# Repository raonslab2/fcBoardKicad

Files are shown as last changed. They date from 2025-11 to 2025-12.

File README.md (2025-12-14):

# fcBoard - ACU5EV SoM Carrier Board

ACU5EV (Zynq UltraScale+ XCZU5EV) SoM용 캐리어 보드 KiCad 프로젝트

## 프로젝트 구조

```
fcBoardKicad/
├── fcBoard.kicad_pro          # KiCad 프로젝트 파일
├── fcBoard.kicad_sch          # 메인 회로도
├── fcBoard.kicad_pcb          # PCB 레이아웃
├── libraries/                  # 커스텀 라이브러리
│   ├── fcBoard.kicad_sym      # 심볼 라이브러리
│   └── fcBoard.pretty/        # 풋프린트 라이브러리
├── datasheets/                # 데이터시트
├── docs/                      # 설계 문서
│   └── pinmap/                # SoM 커넥터 핀맵
├── gerber/                    # 거버 출력
└── production/                # 생산 파일 (BOM, PnP)
```

## SoM 커넥터 정보

| 커넥터 | 핀 수 | 주요 신호 |
|---|---|---|
| J29 | 120핀 | BANK65, BANK66 (HDMI, MIPI, Ethernet PL) |
| J30 | 120핀 | BANK25, BANK26, MGT505 (PCIe, SFP) |
| J31 | 120핀 | BANK24, BANK44 (RS485, LED, 버튼) |
| J32 | 120핀 | PS MIO, 전원 (+12V, VCCO) |

**커넥터 모델:** Panasonic AXK6A2337YG (120핀, 0.5mm 피치)

## 인터페이스 목록

### PS (Processing System) 인터페이스
- USB 3.0 x4 (USB Hub: USB5744)
- Gigabit Ethernet (PS GEM3, RGMII)
- SD Card (SDIO1)
- UART (USB-UART: CP2102)
- CAN x2
- DisplayPort (SoM 커넥터에서 직접 출력)

### PL (Programmable Logic) 인터페이스
- HDMI 입력 (IT6801FN)
- HDMI 출력 (IT66121FN)
- Gigabit Ethernet (PL RGMII)
- PCIe x2 (MGT505)
- MIPI CSI-2 (2 Lane)
- RS485 x2
- SFP+ x2 (옵션)

## 전원 요구사항

| 전원 | 전압 | 용도 |
|---|---|---|
| 입력 | DC 12V | 메인 전원 (최소 5A) |
| VCCO_65 | 1.8V | BANK65 I/O (캐리어 공급) |
| VCCO_66 | 1.8V | BANK66 I/O (캐리어 공급) |
| 내부 | 5V, 3.3V | 주변 IC 전원 |

## 참조 자료

- [ACU5EV SoM 회로도](../ACU2CG_ACU3EG_ACU4EV_ACU5EV/Schematics/ACU5EV_SCH.pdf)
- [AXU5EV-P 캐리어 보드 참조](../AXU4EV-P_AXU5EV-P/hardware/Schematics/)
- [ACU5EV 사용자 매뉴얼](../ACU2CG_ACU3EG_ACU4EV_ACU5EV/Technical_Reference_Manual/)

## 핀맵 파일

- `docs/pinmap/J29_BANK65_66.csv` - HDMI, MIPI, Ethernet PL
- `docs/pinmap/J30_BANK25_26_MGT.csv` - PCIe, SFP
- `docs/pinmap/J31_BANK24_44.csv` - RS485, GPIO
- `docs/pinmap/J32_MIO_POWER.csv` - PS MIO, 전원

## KiCad Auto Builder (회로도 자동 생성)

YAML 설정 파일로 KiCad 회로도를 자동 생성합니다.

### Quickstart

```bash
# 1. 설정 검증
python -m kicad_auto_builder.cli validate kicad_auto_builder/examples/fcboard_power.yaml

# 2. 빌드 실행
python -m kicad_auto_builder.cli build kicad_auto_builder/examples/fcboard_power.yaml

# 3. 출력 확인
# out/fcboard_power/
#   ├── fcBoard_Power_Auto.kicad_sch
#   ├── lib/custom.kicad_sym
#   ├── lib/custom.pretty/
#   ├── bom_jlc.csv
#   └── report.md
```

### YAML 예제

- `kicad_auto_builder/examples/fcboard_power.yaml` - 전원 공급 회로
- `kicad_auto_builder/examples/fcboard_usb.yaml` - USB 인터페이스
- `kicad_auto_builder/examples/hierarchical_board.yaml` - 계층 시트 예제

## 설계 시작하기

1. KiCad 8.0 이상 설치
2. `fcBoard.kicad_pro` 열기
3. 라이브러리 경로 설정 (libraries/ 폴더)
4. 핀맵 CSV 참조하여 회로도 작성
5. PCB 레이아웃 (6층 권장)

## PCB 권장 사양

- 층수: 6층
- 두께: 1.6mm
- 임피던스: 단일 50Ω, 차동 100Ω
- 최소 선폭/간격: 0.1mm / 0.1mm
- 최소 비아: 0.3mm 드릴

## 라이선스

MIT License

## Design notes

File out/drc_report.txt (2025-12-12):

** Drc report for fcBoard.kicad_pcb **
** Created on 2025-12-01T13:50:49+0900 **

** Found 384 DRC violations **
[clearance]: Clearance violation (netclass 'Default' clearance 0.2000 mm; actual 0.0000 mm)
    Rule: netclass 'Default'; error
    @(126.1200 mm, 369.1400 mm): Pad 2 [unconnected-(Y9-Pad2)] of Y9 on F.Cu
    @(125.6200 mm, 367.8150 mm): Pad 31 [<no net>] of U41 on F.Cu
[clearance]: Clearance violation (netclass 'Default' clearance 0.2000 mm; actual 0.0000 mm)
    Rule: netclass 'Default'; error
    @(126.1200 mm, 369.1400 mm): Pad 2 [unconnected-(Y9-Pad2)] of Y9 on F.Cu
    @(126.1200 mm, 367.8150 mm): Pad 32 [<no net>] of U41 on F.Cu
[shorting_items]: Items shorting two nets (nets unconnected-(J4-SHIELD-Pad5) and unconnected-(J3-SHIELD-Pad5))
    Local override; error
    @(272.3800 mm, 57.4400 mm): PTH pad 5 [unconnected-(J4-SHIELD-Pad5)] of J4
    @(272.3800 mm, 58.5800 mm): PTH pad 5 [unconnected-(J3-SHIELD-Pad5)] of J3
[shorting_items]: Items shorting two nets (nets Net-(U26-VIN) and GND)
    Local override; error
    @(42.6050 mm, 177.5450 mm): Pad 1 [Net-(U26-VIN)] of U28 on F.Cu
    @(36.7550 mm, 180.9450 mm): Pad 3 [GND] of U27 on F.Cu
[shorting_items]: Items shorting two nets (nets Net-(D14-A) and GND)
    Local override; error
    @(42.6050 mm, 179.2450 mm): Pad 2 [Net-(D14-A)] of U28 on F.Cu
    @(36.7550 mm, 180.9450 mm): Pad 3 [GND] of U27 on F.Cu
[shorting_items]: Items shorting two nets (nets unconnected-(U28-FB-Pad4) and GND)
    Local override; error
    @(42.6050 mm, 182.6450 mm): Pad 4 [unconnected-(U28-FB-Pad4)] of U28 on F.Cu
    @(36.7550 mm, 180.9450 mm): Pad 3 [GND] of U27 on F.Cu
[shorting_items]: Items shorting two nets (nets unconnected-(U28-~{ON}{slash}OFF-Pad5) and GND)
    Local override; error
    @(42.6050 mm, 184.3450 mm): Pad 5 [unconnected-(U28-~{ON}/OFF-Pad5)] of U28 on F.Cu
    @(36.7550 mm, 180.9450 mm): Pad 3 [GND] of U27 on F.Cu
[clearance]: Clearance violation (netclass 'Default' clearance 0.2000 mm; actual 0.0250 mm)
    Rule: netclass 'Default'; error
    @(121.3750 mm, 50.4450 mm): Pad 2 [unconnected-(U17-D--Pad2)] of U17 on F.Cu
    @(120.7000 mm, 51.5950 mm): Pad 9 [unconnected-(J11-CD-Pad9)] of J11 on F.Cu
[shorting_items]: Items shorting two nets (nets unconnected-(U17-VBUS-Pad3) and unconnected-(J11-CD-Pad9))
    Local override; error
    @(121.3750 mm, 50.9450 mm): Pad 3 [unconnected-(U17-VBUS-Pad3)] of U17 on F.Cu
    @(120.7000 mm, 51.5950 mm): Pad 9 [unconnected-(J11-CD-Pad9)] of J11 on F.Cu
[shorting_items]: Items shorting two nets (nets unconnected-(U17-TXD-Pad4) and unconnected-(J11-CD-Pad9))
    Local override; error
    @(121.3750 mm, 51.4450 mm): Pad 4 [unconnected-(U17-TXD-Pad4)] of U17 on F.Cu
    @(120.7000 mm, 51.5950 mm): Pad 9 [unconnected-(J11-CD-Pad9)] of J11 on F.Cu
[shorting_items]: Items shorting two nets (nets unconnected-(U17-RXD-Pad5) and unconnected-(J11-CD-Pad9))
    Local override; error
    @(121.3750 mm, 51.9450 mm): Pad 5 [unconnected-(U17-RXD-Pad5)] of U17 on F.Cu
    @(120.7000 mm, 51.5950 mm): Pad 9 [unconnected-(J11-CD-Pad9)] of J11 on F.Cu
[shorting_items]: Items shorting two nets (nets unconnected-(U17-RTS-Pad6) and unconnected-(J11-CD-Pad9))
    Local override; error
    @(121.3750 mm, 52.4450 mm): Pad 6 [unconnected-(U17-RTS-Pad6)] of U17 on F.Cu
    @(120.7000 mm, 51.5950 mm): Pad 9 [unconnected-(J11-CD-Pad9)] of J11 on F.Cu
[shorting_items]: Items shorting two nets (nets unconnected-(J3-SHIELD-Pad5) and unconnected-(J2-SHIELD-Pad5))
    Local override; error
    @(272.3800 mm, 45.4400 mm): PTH pad 5 [unconnected-(J3-SHIELD-Pad5)] of J3
    @(272.3800 mm, 46.5800 mm): PTH pad 5 [unconnected-(J2-SHIELD-Pad5)] of J2
[shorting_items]: Items shorting two nets (nets unconnected-(J11-CD-Pad9) and unconnected-(U16-~{RE}-Pad2))
    Local override; error
    @(106.9500 mm, 51.5950 mm): Pad 9 [unconnected-(J11-CD-Pad9)] of J11 on F.Cu
    @(106.3500 mm, 50.8100 mm): Pad 2 [unconnected-(U16-~{RE}-Pad2)] of U16 on F.Cu
[shorting_items]: Items shorting two nets (nets unconnected-(J11-CD-Pad9) and unconnected-(U16-DE-Pad3))
    Local override; error
    @(106.9500 mm, 51.5950 mm): Pad 9 [unconnected-(J11-CD-Pad9)] of J11 on F.Cu
    @(106.3500 mm, 52.0800 mm): Pad 3 [unconnected-(U16-DE-Pad3)] of U16 on F.Cu
[clearance]: Clearance violation (netclass 'Default' clearance 0.2000 mm; actual 0.1850 mm)
    Rule: netclass 'Default'; error
    @(232.1075 mm, 36.3100 mm): Pad 1 [unconnected-(U5-D+-Pad1)] of U5 on F.Cu
    @(232.6700 mm, 35.6475 mm): Pad 9 [<no net>] of U5 on F.Cu
[clearance]: Clearance violation (netclass 'Default' clearance 0.2000 mm; actual 0.1750 mm)
    Rule: netclass 'Default'; error
    @(232.1075 mm, 36.3100 mm): Pad 1 [unconnected-(U5-D+-Pad1)] of U5 on F.Cu
    @(232.2700 mm, 35.6475 mm): Pad 10 [<no net>] of U5 on F.Cu
[clearance]: Clearance violation (netclass 'Default' clearance 0.2000 mm; actual 0.1750 mm)
    Rule: netclass 'Default'; error
    @(232.0075 mm, 36.7100 mm): Pad 2 [unconnected-(U5-D--Pad2)] of U5 on F.Cu
    @(232.2700 mm, 37.3725 mm): Pad 3 [unconnected-(U5-D+_OUT-Pad3)] of U5 on F.Cu
[clearance]: Clearance violation (netclass 'Default' clearance 0.2000 mm; actual 0.1750 mm)
    Rule: netclass 'Default'; error
    @(233.0700 mm, 37.3725 mm): Pad 5 [GND] of U5 on F.Cu
    @(233.3325 mm, 36.7100 mm): Pad 6 [+3V3] of U5 on F.Cu
[clearance]: Clearance violation (netclass 'Default' clearance 0.2000 mm; actual 0.1750 mm)
    Rule: netclass 'Default'; error
    @(233.3325 mm, 36.3100 mm): Pad 7 [<no net>] of U5 on F.Cu
    @(233.0700 mm, 35.6475 mm): Pad 8 [<no net>] of U5 on F.Cu
[clearance]: Clearance violation (netclass 'Default' clearance 0.2000 mm; actual 0.1850 mm)
    Rule: netclass 'Default'; error
    @(242.1075 mm, 66.3100 mm): Pad 1 [unconnected-(U4-D+-Pad1)] of U4 on F.Cu
    @(242.6700 mm, 65.6475 mm): Pad 9 [<no net>] of U4 on F.Cu
[clearance]: Clearance violation (netclass 'Default' clearance 0.2000 mm; actual 0.1750 mm)
    Rule: netclass 'Default'; error
    @(242.1075 mm, 66.3100 mm): Pad 1 [unconnected-(U4-D+-Pad1)] of U4 on F.Cu
    @(242.2700 mm, 65.6475 mm): Pad 10 [<no net>] of U4 on F.Cu
[clearance]: Clearance violation (netclass 'Default' clearance 0.2000 mm; actual 0.1750 mm)
    Rule: netclass 'Default'; error
    @(242.0075 mm, 66.7100 mm): Pad 2 [unconnected-(U4-D--Pad2)] of U4 on F.Cu
    @(242.2700 mm, 67.3725 mm): Pad 3 [unconnected-(U4-D+_OUT-Pad3)] of U4 on F.Cu
[clearance]: Clearance violation (netclass 'Default' clearance 0.2000 mm; actual 0.1750 mm)
    Rule: netclass 'Default'; error
    @(243.0700 mm, 67.3725 mm): Pad 5 [GND] of U4 on F.Cu
    @(243.3325 mm, 66.7100 mm): Pad 6 [+3V3] of U4 on F.Cu
[clearance]: Clearance violation (netclass 'Default' clearance 0.2000 mm; actual 0.1750 mm)
    Rule: netclass 'Default'; error
    @(243.3325 mm, 66.3100 mm): Pad 7 [<no net>] of U4 on F.Cu
    @(243.0700 mm, 65.6475 mm): Pad 8 [<no net>] of U4 on F.Cu
[shorting_items]: Items shorting two nets (nets unconnected-(J2-SHIELD-Pad5) and unconnected-(J1-SHIELD-Pad5))
    Local override; error
    @(272.3800 mm, 33.4400 mm): PTH pad 5 [unconnected-(J2-SHIELD-Pad5)] of J2
    @(272.3800 mm, 34.5800 mm): PTH pad 5 [unconnected-(J1-SHIELD-Pad5)] of J1
[shorting_items]: Items shorting two nets (nets /HDMI In/Out/HDMI_IN_D2P and Net-(U41-CEC))
    Local override; error
    @(135.4075 mm, 375.8900 mm): Pad 1 [/HDMI In/Out/HDMI_IN_D2P] of U44 on F.Cu
    @(135.4075 mm, 375.8900 mm): Pad 5 [Net-(U41-CEC)] of U45 on F.Cu
[shorting_items]: Items shorting two nets (nets unconnected-(U44-D2--Pad2) and Net-(U41-CEC))
    Local override; error
    @(135.4075 mm, 376.3900 mm): Pad 2 [unconnected-(U44-D2--Pad2)] of U44 on F.Cu
    @(135.4075 mm, 376.3900 mm): Pad 6 [Net-(U41-CEC)] of U45 on F.Cu
[clearance]: Clearance violation (netclass 'Default' clearance 0.2000 mm; actual 0.1750 mm)
    Rule: netclass 'Default'; error
    @(135.4075 mm, 376.8900 mm): Pad 3 [/HDMI In/Out/HDMI_IN_D2N] of U44 on F.Cu
    @(136.1200 mm, 377.1025 mm): Pad 7 [Net-(U41-CEC)] of U45 on F.Cu
[clearance]: Clearance violation (netclass 'Default' clearance 0.2000 mm; actual 0.1750 mm)
    Rule: netclass 'Default'; error
    @(135.4075 mm, 377.3900 mm): Pad 4 [unconnected-(U44-D1--Pad4)] of U44 on F.Cu
    @(136.1200 mm, 377.1025 mm): Pad 7 [Net-(U41-CEC)] of U45 on F.Cu
[clearance]: Clearance violation (netclass 'Default' clearance 0.2000 mm; actual 0.1750 mm)
    Rule: netclass 'Default'; error
    @(139.3325 mm, 377.3900 mm): Pad 15 [Net-(U43-TMDS_CLK-)] of U44 on F.Cu
    @(138.6200 mm, 377.1025 mm): Pad 12 [Net-(J23-TMDS_D2-)] of U45 on F.Cu
[clearance]: Clearance violation (netclass 'Default' clearance 0.2000 mm; actual 0.1750 mm)
    Rule: netclass 'Default'; error
    @(139.3325 mm, 376.8900 mm): Pad 16 [unconnected-(U44-CLK+_O-Pad16)] of U44 on F.Cu
    @(138.6200 mm, 377.1025 mm): Pad 12 [Net-(J23-TMDS_D2-)] of U45 on F.Cu
[shorting_items]: Items shorting two nets (nets Net-(U43-CEC) and Net-(J23-TMDS_D1+))
    Local override; error
    @(139.3325 mm, 376.3900 mm): Pad 17 [Net-(U43-CEC)] of U44 on F.Cu
    @(139.3325 mm, 376.3900 mm): Pad 13 [Net-(J23-TMDS_D1+)] of U45 on F.Cu
[clearance]: Clearance violation (netclass 'Default' clearance 0.2000 mm; actual 0.0000 mm)
    Rule: netclass 'Default'; error
    @(139.3325 mm, 375.8900 mm): Pad 18 [<no net>] of U44 on F.Cu
    @(139.3325 mm, 375.8900 mm): Pad 14 [Net-(J23-TMDS_D1_SH)] of U45 on F.Cu
[clearance]: Clearance violation (netclass 'Default' clearance 0.2000 mm; actual 0.0000 mm)
    Rule: netclass 'Default'; error
    @(138.6200 mm, 375.1775 mm): Pad 19 [<no net>] of U44 on F.Cu
    @(137.3700 mm, 375.1400 mm): Pad 25 [<no net>] of U45 on F.Cu
[clearance]: Clearance violation (netclass 'Default' clearance 0.2000 mm; actual 0.1750 mm)
    Rule: netclass 'Default'; error
    @(138.6200 mm, 375.1775 mm): Pad 19 [<no net>] of U44 on F.Cu
    @(139.3325 mm, 375.3900 mm): Pad 15 [Net-(J23-TMDS_D1-)] of U45 on F.Cu
[clearance]: Clearance violation (netclass 'Default' clearance 0.2000 mm; actual 0.1750 mm)
    Rule: netclass 'Default'; error
    @(138.6200 mm, 375.1775 mm): Pad 19 [<no net>] of U44 on F.Cu
    @(139.3325 mm, 374.8900 mm): Pad 16 [Net-(J23-TMDS_D0+)] of U45 on F.Cu
[clearance]: Clearance violation (netclass 'Default' clearance 0.2000 mm; actual 0.0000 mm)
    Rule: netclass 'Default'; error
    @(138.1200 mm, 375.1775 mm): Pad 20 [<no net>] of U44 on F.Cu
    @(137.3700 mm, 375.1400 mm): Pad 25 [<no net>] of U45 on F.Cu
[clearance]: Clearance violation (netclass 'Default' clearance 0.2000 mm; actual 0.0000 mm)
    Rule: netclass 'Default'; error
    @(137.6200 mm, 375.1775 mm): Pad 21 [<no net>] of U44 on F.Cu
    @(137.3700 mm, 375.1400 mm): Pad 25 [<no net>] of U45 on F.Cu
[clearance]: Clearance violation (netclass 'Default' clearance 0.2000 mm; actual 0.0000 mm)
    Rule: netclass 'Default'; error
    @(137.1200 mm, 375.1775 mm): Pad 22 [<no net>] of U44 on F.Cu
    @(137.3700 mm, 375.1400 mm): Pad 25 [<no net>] of U45 on F.Cu
[clearance]: Clearance violation (netclass 'Default' clearance 0.2000 mm; actual 0.0000 mm)
    Rule: netclass 'Default'; error
    @(136.6200 mm, 375.1775 mm): Pad 23 [<no net>] of U44 on F.Cu
    @(137.3700 mm, 375.1400 mm): Pad 25 [<no net>] of U45 on F.Cu
[clearance]: Clearance violation (netclass 'Default' clearance 0.2000 mm; actual 0.0000 mm)
    Rule: netclass 'Default'; error
    @(136.1200 mm, 375.1775 mm): Pad 24 [<no net>] of U44 on F.Cu
    @(137.3700 mm, 375.1400 mm): Pad 25 [<no net>] of U45 on F.Cu
[clearance]: Clearance violation (netclass 'Default' clearance 0.2000 mm; actual 0.1750 mm)
    Rule: netclass 'Default'; error
    @(136.1200 mm, 375.1775 mm): Pad 24 [<no net>] of U44 on F.Cu
    @(135.4075 mm, 374.8900 mm): Pad 3 [Net-(U41-CEC)] of U45 on F.Cu
[clearance]: Clearance violation (netclass 'Default' clearance 0.2000 mm; actual 0.1750 mm)
    Rule: netclass 'Default'; error
    @(136.1200 mm, 375.1775 mm): Pad 24 [<no net>] of U44 on F.Cu
    @(135.4075 mm, 375.3900 mm): Pad 4 [Net-(U41-CEC)] of U45 on F.Cu
[clearance]: Clearance violation (netclass 'Default' clearance 0.2000 mm; actual 0.0000 mm)
    Rule: netclass 'Default'; error
    @(137.3700 mm, 377.1400 mm): Pad 25 [<no net>] of U44 on F.Cu
    @(137.3700 mm, 375.1400 mm): Pad 25 [<no net>] of U45 on F.Cu
[clearance]: Clearance violation (netclass 'Default' clearance 0.2000 mm; actual 0.0000 mm)
    Rule: netclass 'Default'; error
    @(137.3700 mm, 377.1400 mm): Pad 25 [<no net>] of U44 on F.Cu
    @(136.1200 mm, 377.1025 mm): Pad 7 [Net-(U41-CEC)] of U45 on F.Cu
[clearance]: Clearance violation (netclass 'Default' clearance 0.2000 mm; actual 0.0000 mm)
    Rule: netclass 'Default'; error
    @(137.3700 mm, 377.1400 mm): Pad 25 [<no net>] of U44 on F.Cu
    @(136.6200 mm, 377.1025 mm): Pad 8 [Net-(U41-CEC)] of U45 on F.Cu
[clearance]: Clearance violation (netclass 'Default' clearance 0.2000 mm; actual 0.0000 mm)
    Rule: netclass 'Default'; error
    @(137.3700 mm, 377.1400 mm): Pad 25 [<no net>] of U44 on F.Cu
    @(137.1200 mm, 377.1025 mm): Pad 9 [Net-(U41-CEC)] of U45 on F.Cu
[clearance]: Clearance violation (netclass 'Default' clearance 0.2000 mm; actual 0.0000 mm)
    Rule: netclass 'Default'; error
    @(137.3700 mm, 377.1400 mm): Pad 25 [<no net>] of U44 on F.Cu
    @(137.6200 mm, 377.1025 mm): Pad 10 [Net-(J23-TMDS_D2+)] of U45 on F.Cu
[clearance]: Clearance violation (netclass 'Default' clearance 0.2000 mm; actual 0.0000 mm)
    Rule: netclass 'Default'; error
    @(137.3700 mm, 377.1400 mm): Pad 25 [<no net>] of U44 on F.Cu
    @(138.1200 mm, 377.1025 mm): Pad 11 [Net-(J23-TMDS_D2_SH)] of U45 on F.Cu
[clearance]: Clearance violation (netclass 'Default' clearance 0.2000 mm; actual 0.0000 mm)
    Rule: netclass 'Default'; error
    @(137.3700 mm, 377.1400 mm): Pad 25 [<no net>] of U44 on F.Cu
    @(138.6200 mm, 377.1025 mm): Pad 12 [Net-(J23-TMDS_D2-)] of U45 on F.Cu
[shorting_items]: Items shorting two nets (nets Net-(J23-TMDS_D2+) and Net-(J23-TMDS_D2-))
    Local override; error
    @(168.7200 mm, 389.4000 mm): Pad 1 [Net-(J23-TMDS_D2+)] of J23 on F.Cu
    @(168.7200 mm, 388.4000 mm): Pad 3 [Net-(J23-TMDS_D2-)] of J23 on F.Cu
[shorting_items]: Items shorting two nets (nets Net-(J23-TMDS_D2+) and Net-(J23-TMDS_D1_SH))
    Local override; error
    @(168.7200 mm, 389.4000 mm): Pad 1 [Net-(J23-TMDS_D2+)] of J23 on F.Cu
    @(168.7200 mm, 387.4000 mm): Pad 5 [Net-(J23-TMDS_D1_SH)] of J23 on F.Cu
[clearance]: Clearance violation (netclass 'Default' clearance 0.2000 mm; actual 0.0000 mm)
    Rule: netclass 'Default'; error
    @(168.7200 mm, 389.4000 mm): Pad 1 [Net-(J23-TMDS_D2+)] of J23 on F.Cu
    @(168.8200 mm, 391.6750 mm): Pad SH [<no net>] of J23 on F.Cu
[shorting_items]: Items shorting two nets (nets Net-(J23-TMDS_D2_SH) and Net-(J23-TMDS_D1+))
    Local override; error
    @(168.7200 mm, 388.9000 mm): Pad 2 [Net-(J23-TMDS_D2_SH)] of J23 on B.Cu
    @(168.7200 mm, 387.9000 mm): Pad 4 [Net-(J23-TMDS_D1+)] of J23 on B.Cu
[shorting_items]: Items shorting two nets (nets Net-(J23-TMDS_D2_SH) and Net-(J23-TMDS_D1-))
    Local override; error
    @(168.7200 mm, 388.9000 mm): Pad 2 [Net-(J23-TMDS_D2_SH)] of J23 on B.Cu
    @(168.7200 mm, 386.9000 mm): Pad 6 [Net-(J23-TMDS_D1-)] of J23 on B.Cu
[clearance]: Clearance violation (netclass 'Default' clearance 0.2000 mm; actual 0.0750 mm)
    Rule: netclass 'Default'; error
    @(168.7200 mm, 388.9000 mm): Pad 2 [Net-(J23-TMDS_D2_SH)] of J23 on B.Cu
    @(168.8200 mm, 391.6750 mm): Pad SH [<no net>] of J23 on B.Cu
[shorting_items]: Items shorting two nets (nets Net-(J23-TMDS_D2-) and Net-(J23-TMDS_D1_SH))
    Local override; error
    @(168.7200 mm, 388.4000 mm): Pad 3 [Net-(J23-TMDS_D2-)] of J23 on F.Cu
    @(168.7200 mm, 387.4000 mm): Pad 5 [Net-(J23-TMDS_D1_SH)] of J23 on F.Cu
[shorting_items]: Items shorting two nets (nets Net-(J23-TMDS_D2-) and Net-(J23-TMDS_D0+))
    Local override; error
    @(168.7200 mm, 388.4000 mm): Pad 3 [Net-(J23-TMDS_D2-)] of J23 on F.Cu
    @(168.7200 mm, 386.4000 mm): Pad 7 [Net-(J23-TMDS_D0+)] of J23 on F.Cu
[shorting_items]: Items shorting two nets (nets Net-(J23-TMDS_D1+) and Net-(J23-TMDS_D1-))
    Local override; error
    @(168.7200 mm, 387.9000 mm): Pad 4 [Net-(J23-TMDS_D1+)] of J23 on B.Cu
    @(168.7200 mm, 386.9000 mm): Pad 6 [Net-(J23-TMDS_D1-)] of J23 on B.Cu
[shorting_items]: Items shorting two nets (nets Net-(J23-TMDS_D1+) and Net-(J23-TMDS_D0_SH))
    Local override; error
    @(168.7200 mm, 387.9000 mm): Pad 4 [Net-(J23-TMDS_D1+)] of J23 on B.Cu
    @(168.7200 mm, 385.9000 mm): Pad 8 [Net-(J23-TMDS_D0_SH)] of J23 on B.Cu
[shorting_items]: Items shorting two nets (nets Net-(J23-TMDS_D1_SH) and Net-(J23-TMDS_D0+))
    Local override; error
    @(168.7200 mm, 387.4000 mm): Pad 5 [Net-(J23-TMDS_D1_SH)] of J23 on F.Cu
    @(168.7200 mm, 386.4000 mm): Pad 7 [Net-(J23-TMDS_D0+)] of J23 on F.Cu
[shorting_items]: Items shorting two nets (nets Net-(J23-TMDS_D1_SH) and unconnected-(J23-TMDS_D0--Pad9))
    Local override; error
    @(168.7200 mm, 387.4000 mm): Pad 5 [Net-(J23-TMDS_D1_SH)] of J23 on F.Cu
    @(168.7200 mm, 385.4000 mm): Pad 9 [unconnected-(J23-TMDS_D0--Pad9)] of J23 on F.Cu
[shorting_items]: Items shorting two nets (nets Net-(J23-TMDS_D1-) and Net-(J23-TMDS_D0_SH))
    Local override; error
    @(168.7200 mm, 386.9000 mm): Pad 6 [Net-(J23-TMDS_D1-)] of J23 on B.Cu
    @(168.7200 mm, 385.9000 mm): Pad 8 [Net-(J23-TMDS_D0_SH)] of J23 on B.Cu
[shorting_items]: Items shorting two nets (nets Net-(J23-TMDS_D1-) and unconnected-(J23-TMDS_CLK+-Pad10))
    Local override; error
    @(168.7200 mm, 386.9000 mm): Pad 6 [Net-(J23-TMDS_D1-)] of J23 on B.Cu
    @(168.7200 mm, 384.9000 mm): Pad 10 [unconnected-(J23-TMDS_CLK+-Pad10)] of J23 on B.Cu
[shorting_items]: Items shorting two nets (nets Net-(J23-TMDS_D0+) and unconnected-(J23-TMDS_D0--Pad9))
    Local override; error
    @(168.7200 mm, 386.4000 mm): Pad 7 [Net-(J23-TMDS_D0+)] of J23 on F.Cu
    @(168.7200 mm, 385.4000 mm): Pad 9 [unconnected-(J23-TMDS_D0--Pad9)] of J23 on F.Cu
[shorting_items]: Items shorting two nets (nets Net-(J23-TMDS_D0+) and unconnected-(J23-TMDS_CLK_SH-Pad11))
    Local override; error
    @(168.7200 mm, 386.4000 mm): Pad 7 [Net-(J23-TMDS_D0+)] of J23 on F.Cu
    @(168.7200 mm, 384.4000 mm): Pad 11 [unconnected-(J23-TMDS_CLK_SH-Pad11)] of J23 on F.Cu
[shorting_items]: Items shorting two nets (nets Net-(J23-TMDS_D0_SH) and unconnected-(J23-TMDS_CLK+-Pad10))
    Local override; error
    @(168.7200 mm, 385.9000 mm): Pad 8 [Net-(J23-TMDS_D0_SH)] of J23 on B.Cu
    @(168.7200 mm, 384.9000 mm): Pad 10 [unconnected-(J23-TMDS_CLK+-Pad10)] of J23 on B.Cu
[shorting_items]: Items shorting two nets (nets Net-(J23-TMDS_D0_SH) and unconnected-(J23-TMDS_CLK--Pad12))
    Local override; error
    @(168.7200 mm, 385.9000 mm): Pad 8 [Net-(J23-TMDS_D0_SH)] of J23 on B.Cu
    @(168.7200 mm, 383.9000 mm): Pad 12 [unconnected-(J23-TMDS_CLK--Pad12)] of J23 on B.Cu
[shorting_items]: Items shorting two nets (nets unconnected-(J23-TMDS_D0--Pad9) and unconnected-(J23-TMDS_CLK_SH-Pad11))
    Local override; error
    @(168.7200 mm, 385.4000 mm): Pad 9 [unconnected-(J23-TMDS_D0--Pad9)] of J23 on F.Cu
    @(168.7200 mm, 384.4000 mm): Pad 11 [unconnected-(J23-TMDS_CLK_SH-Pad11)] of J23 on F.Cu
[shorting_items]: Items shorting two nets (nets unconnected-(J23-TMDS_D0--Pad9) and unconnected-(J23-CEC-Pad13))
    Local override; error
    @(168.7200 mm, 385.4000 mm): Pad 9 [unconnected-(J23-TMDS_D0--Pad9)] of J23 on F.Cu
    @(168.7200 mm, 383.4000 mm): Pad 13 [unconnected-(J23-CEC-Pad13)] of J23 on F.Cu
[shorting_items]: Items shorting two nets (nets unconnected-(J23-TMDS_CLK+-Pad10) and unconnected-(J23-TMDS_CLK--Pad12))
    Local override; error
    @(168.7200 mm, 384.9000 mm): Pad 10 [unconnected-(J23-TMDS_CLK+-Pad10)] of J23 on B.Cu
    @(168.7200 mm, 383.9000 mm): Pad 12 [unconnected-(J23-TMDS_CLK--Pad12)] of J23 on B.Cu
[shorting_items]: Items shorting two nets (nets unconnected-(J23-TMDS_CLK+-Pad10) and unconnected-(J23-NC-Pad14))
    Local override; error
    @(168.7200 mm, 384.9000 mm): Pad 10 [unconnected-(J23-TMDS_CLK+-Pad10)] of J23 on B.Cu
    @(168.7200 mm, 382.9000 mm): Pad 14 [unconnected-(J23-NC-Pad14)] of J23 on B.Cu
[shorting_items]: Items shorting two nets (nets unconnected-(J23-TMDS_CLK_SH-Pad11) and unconnected-(J23-CEC-Pad13))
    Local override; error
    @(168.7200 mm, 384.4000 mm): Pad 11 [unconnected-(J23-TMDS_CLK_SH-Pad11)] of J23 on F.Cu
    @(168.7200 mm, 383.4000 mm): Pad 13 [unconnected-(J23-CEC-Pad13)] of J23 on F.Cu
[shorting_items]: Items shorting two nets (nets unconnected-(J23-TMDS_CLK_SH-Pad11) and unconnected-(J23-SCL-Pad15))
    Local override; error
    @(168.7200 mm, 384.4000 mm): Pad 11 [unconnected-(J23-TMDS_CLK_SH-Pad11)] of J23 on F.Cu
    @(168.7200 mm, 382.4000 mm): Pad 15 [unconnected-(J23-SCL-Pad15)] of J23 on F.Cu
[shorting_items]: Items shorting two nets (nets unconnected-(J23-TMDS_CLK--Pad12) and unconnected-(J23-NC-Pad14))
    Local override; error
    @(168.7200 mm, 383.9000 mm): Pad 12 [unconnected-(J23-TMDS_CLK--Pad12)] of J23 on B.Cu
    @(168.7200 mm, 382.9000 mm): Pad 14 [unconnected-(J23-NC-Pad14)] of J23 on B.Cu
[shorting_items]: Items shorting two nets (nets unconnected-(J23-TMDS_CLK--Pad12) and unconnected-(J23-SDA-Pad16))
    Local override; error
    @(168.7200 mm, 383.9000 mm): Pad 12 [unconnected-(J23-TMDS_CLK--Pad12)] of J23 on B.Cu
    @(168.7200 mm, 381.9000 mm): Pad 16 [unconnected-(J23-SDA-Pad16)] of J23 on B.Cu
[shorting_items]: Items shorting two nets (nets unconnected-(J23-CEC-Pad13) and unconnected-(J23-SCL-Pad15))
    Local override; error
    @(168.7200 mm, 383.4000 mm): Pad 13 [unconnected-(J23-CEC-Pad13)] of J23 on F.Cu
    @(168.7200 mm, 382.4000 mm): Pad 15 [unconnected-(J23-SCL-Pad15)] of J23 on F.Cu
[shorting_items]: Items shorting two nets (nets unconnected-(J23-CEC-Pad13) and GND)
    Local override; error
    @(168.7200 mm, 383.4000 mm): Pad 13 [unconnected-(J23-CEC-Pad13)] of J23 on F.Cu
    @(168.7200 mm, 381.4000 mm): Pad 17 [GND] of J23 on F.Cu
[shorting_items]: Items shorting two nets (nets unconnected-(J23-NC-Pad14) and unconnected-(J23-SDA-Pad16))
    Local override; error
    @(168.7200 mm, 382.9000 mm): Pad 14 [unconnected-(J23-NC-Pad14)] of J23 on B.Cu
    @(168.7200 mm, 381.9000 mm): Pad 16 [unconnected-(J23-SDA-Pad16)] of J23 on B.Cu
[shorting_items]: Items shorting two nets (nets unconnected-(J23-NC-Pad14) and unconnected-(J23-+5V-Pad18))
    Local override; error
    @(168.7200 mm, 382.9000 mm): Pad 14 [unconnected-(J23-NC-Pad14)] of J23 on B.Cu
    @(168.7200 mm, 380.9000 mm): Pad 18 [unconnected-(J23-+5V-Pad18)] of J23 on B.Cu
[shorting_items]: Items shorting two nets (nets unconnected-(J23-SCL-Pad15) and GND)
    Local override; error
    @(168.7200 mm, 382.4000 mm): Pad 15 [unconnected-(J23-SCL-Pad15)] of J23 on F.Cu
    @(168.7200 mm, 381.4000 mm): Pad 17 [GND] of J23 on F.Cu
[shorting_items]: Items shorting two nets (nets unconnected-(J23-SCL-Pad15) and unconnected-(J23-HPD-Pad19))
    Local override; error
    @(168.7200 mm, 382.4000 mm): Pad 15 [unconnected-(J23-SCL-Pad15)] of J23 on F.Cu
    @(168.7200 mm, 380.4000 mm): Pad 19 [unconnected-(J23-HPD-Pad19)] of J23 on F.Cu
[shorting_items]: Items shorting two nets (nets unconnected-(J23-SDA-Pad16) and unconnected-(J23-+5V-Pad18))
    Local override; error
    @(168.7200 mm, 381.9000 mm): Pad 16 [unconnected-(J23-SDA-Pad16)] of J23 on B.Cu
    @(168.7200 mm, 380.9000 mm): Pad 18 [unconnected-(J23-+5V-Pad18)] of J23 on B.Cu
[shorting_items]: Items shorting two nets (nets GND and unconnected-(J23-HPD-Pad19))
    Local override; error
    @(168.7200 mm, 381.4000 mm): Pad 17 [GND] of J23 on F.Cu
    @(168.7200 mm, 380.4000 mm): Pad 19 [unconnected-(J23-HPD-Pad19)] of J23 on F.Cu
[clearance]: Clearance violation (netclass 'Default' clearance 0.2000 mm; actual 0.0750 mm)
    Rule: netclass 'Default'; error
    @(168.7200 mm, 380.9000 mm): Pad 18 [unconnected-(J23-+5V-Pad18)] of J23 on B.Cu
    @(168.8200 mm, 378.1250 mm): Pad SH [<no net>] of J23 on B.Cu
[clearance]: Clearance violation (netclass 'Default' clearance 0.2000 mm; actual 0.0000 mm)
    Rule: netclass 'Default'; error
    @(168.7200 mm, 380.4000 mm): Pad 19 [unconnected-(J23-HPD-Pad19)] of J23 on F.Cu
    @(168.8200 mm, 378.1250 mm): Pad SH [<no net>] of J23 on F.Cu
[clearance]: Clearance violation (netclass 'Default' clearance 0.2000 mm; actual 0.1850 mm)
    Rule: netclass 'Default'; error
    @(232.1075 mm, 51.3100 mm): Pad 1 [unconnected-(U6-D+-Pad1)] of U6 on F.Cu
    @(232.6700 mm, 50.6475 mm): Pad 9 [<no net>] of U6 on F.Cu
[clearance]: Clearance violation (netclass 'Default' clearance 0.2000 mm; actual 0.1750 mm)
    Rule: netclass 'Default'; error
    @(232.1075 mm, 51.3100 mm): Pad 1 [unconnected-(U6-D+-Pad1)] of U6 on F.Cu
    @(232.2700 mm, 50.6475 mm): Pad 10 [<no net>] of U6 on F.Cu
[clearance]: Clearance violation (netclass 'Default' clearance 0.2000 mm; actual 0.1750 mm)
    Rule: netclass 'Default'; error
    @(232.0075 mm, 51.7100 mm): Pad 2 [unconnected-(U6-D--Pad2)] of U6 on F.Cu
    @(232.2700 mm, 52.3725 mm): Pad 3 [unconnected-(U6-D+_OUT-Pad3)] of U6 on F.Cu
[clearance]: Clearance violation (netclass 'Default' clearance 0.2000 mm; actual 0.1750 mm)
    Rule: netclass 'Default'; error
    @(233.0700 mm, 52.3725 mm): Pad 5 [GND] of U6 on F.Cu
    @(233.3325 mm, 51.7100 mm): Pad 6 [+3V3] of U6 on F.Cu
[clearance]: Clearance violation (netclass 'Default' clearance 0.2000 mm; actual 0.1750 mm)
    Rule: netclass 'Default'; error
    @(233.3325 mm, 51.3100 mm): Pad 7 [<no net>] of U6 on F.Cu
    @(233.0700 mm, 50.6475 mm): Pad 8 [<no net>] of U6 on F.Cu
[clearance]: Clearance violation (netclass 'Default' clearance 0.2000 mm; actual 0.1850 mm)
    Rule: netclass 'Default'; error
    @(242.1075 mm, 51.3100 mm): Pad 1 [unconnected-(U3-D+-Pad1)] of U3 on F.Cu
    @(242.6700 mm, 50.6475 mm): Pad 9 [<no net>] of U3 on F.Cu
[clearance]: Clearance violation (netclass 'Default' clearance 0.2000 mm; actual 0.1750 mm)
    Rule: netclass 'Default'; error
    @(242.1075 mm, 51.3100 mm): Pad 1 [unconnected-(U3-D+-Pad1)] of U3 on F.Cu
    @(242.2700 mm, 50.6475 mm): Pad 10 [<no net>] of U3 on F.Cu
[clearance]: Clearance violation (netclass 'Default' clearance 0.2000 mm; actual 0.1750 mm)
    Rule: netclass 'Default'; error
    @(242.0075 mm, 51.7100 mm): Pad 2 [unconnected-(U3-D--Pad2)] of U3 on F.Cu
    @(242.2700 mm, 52.3725 mm): Pad 3 [unconnected-(U3-D+_OUT-Pad3)] of U3 on F.Cu
[clearance]: Clearance violation (netclass 'Default' clearance 0.2000 mm; actual 0.1750 mm)
    Rule: netclass 'Default'; error
    @(243.0700 mm, 52.3725 mm): Pad 5 [GND] of U3 on F.Cu
    @(243.3325 mm, 51.7100 mm): Pad 6 [+3V3] of U3 on F.Cu
[clearance]: Clearance violation (netclass 'Default' clearance 0.2000 mm; actual 0.1750 mm)
    Rule: netclass 'Default'; error
    @(243.3325 mm, 51.3100 mm): Pad 7 [<no net>] of U3 on F.Cu
    @(243.0700 mm, 50.6475 mm): Pad 8 [<no net>] of U3 on F.Cu
[shorting_items]: Items shorting two nets (nets unconnected-(J24-TMDS_D2+-Pad1) and unconnected-(J24-TMDS_D2--Pad3))
    Local override; error
    @(148.8000 mm, 390.8150 mm): Pad 1 [unconnected-(J24-TMDS_D2+-Pad1)] of J24 on F.Cu
    @(148.8000 mm, 389.8150 mm): Pad 3 [unconnected-(J24-TMDS_D2--Pad3)] of J24 on F.Cu
[shorting_items]: Items shorting two nets (nets unconnected-(J24-TMDS_D2+-Pad1) and unconnected-(J24-TMDS_D1_SH-Pad5))
    Local override; error
    @(148.8000 mm, 390.8150 mm): Pad 1 [unconnected-(J24-TMDS_D2+-Pad1)] of J24 on F.Cu
    @(148.8000 mm, 388.8150 mm): Pad 5 [unconnected-(J24-TMDS_D1_SH-Pad5)] of J24 on F.Cu
[clearance]: Clearance violation (netclass 'Default' clearance 0.2000 mm; actual 0.0000 mm)
    Rule: netclass 'Default'; error
    @(148.8000 mm, 390.8150 mm): Pad 1 [unconnected-(J24-TMDS_D2+-Pad1)] of J24 on F.Cu
    @(148.9000 mm, 393.0900 mm): Pad SH [<no net>] of J24 on F.Cu
[shorting_items]: Items shorting two nets (nets unconnected-(J24-TMDS_D2_SH-Pad2) and unconnected-(J24-TMDS_D1+-Pad4))
    Local override; error
    @(148.8000 mm, 390.3150 mm): Pad 2 [unconnected-(J24-TMDS_D2_SH-Pad2)] of J24 on B.Cu
    @(148.8000 mm, 389.3150 mm): Pad 4 [unconnected-(J24-TMDS_D1+-Pad4)] of J24 on B.Cu
[shorting_items]: Items shorting two nets (nets unconnected-(J24-TMDS_D2_SH-Pad2) and unconnected-(J24-TMDS_D1--Pad6))
    Local override; error
    @(148.8000 mm, 390.3150 mm): Pad 2 [unconnected-(J24-TMDS_D2_SH-Pad2)] of J24 on B.Cu
    @(148.8000 mm, 388.3150 mm): Pad 6 [unconnected-(J24-TMDS_D1--Pad6)] of J24 on B.Cu
[clearance]: Clearance violation (netclass 'Default' clearance 0.2000 mm; actual 0.0750 mm)
    Rule: netclass 'Default'; error
    @(148.8000 mm, 390.3150 mm): Pad 2 [unconnected-(J24-TMDS_D2_SH-Pad2)] of J24 on B.Cu
    @(148.9000 mm, 393.0900 mm): Pad SH [<no net>] of J24 on B.Cu
[shorting_items]: Items shorting two nets (nets unconnected-(J24-TMDS_D2--Pad3) and unconnected-(J24-TMDS_D1_SH-Pad5))
    Local override; error
    @(148.8000 mm, 389.8150 mm): Pad 3 [unconnected-(J24-TMDS_D2--Pad3)] of J24 on F.Cu
    @(148.8000 mm, 388.8150 mm): Pad 5 [unconnected-(J24-TMDS_D1_SH-Pad5)] of J24 on F.Cu
[shorting_items]: Items shorting two nets (nets unconnected-(J24-TMDS_D2--Pad3) and unconnected-(J24-TMDS_D0+-Pad7))
    Local override; error
    @(148.8000 mm, 389.8150 mm): Pad 3 [unconnected-(J24-TMDS_D2--Pad3)] of J24 on F.Cu
    @(148.8000 mm, 387.8150 mm): Pad 7 [unconnected-(J24-TMDS_D0+-Pad7)] of J24 on F.Cu
[shorting_items]: Items shorting two nets (nets unconnected-(J24-TMDS_D1+-Pad4) and unconnected-(J24-TMDS_D1--Pad6))
    Local override; error
    @(148.8000 mm, 389.3150 mm): Pad 4 [unconnected-(J24-TMDS_D1+-Pad4)] of J24 on B.Cu
    @(148.8000 mm, 388.3150 mm): Pad 6 [unconnected-(J24-TMDS_D1--Pad6)] of J24 on B.Cu
[shorting_items]: Items shorting two nets (nets unconnected-(J24-TMDS_D1+-Pad4) and unconnected-(J24-TMDS_D0_SH-Pad8))
    Local override; error
    @(148.8000 mm, 389.3150 mm): Pad 4 [unconnected-(J24-TMDS_D1+-Pad4)] of J24 on B.Cu
    @(148.8000 mm, 387.3150 mm): Pad 8 [unconnected-(J24-TMDS_D0_SH-Pad8)] of J24 on B.Cu
[shorting_items]: Items shorting two nets (nets unconnected-(J24-TMDS_D1_SH-Pad5) and unconnected-(J24-TMDS_D0+-Pad7))
    Local override; error
    @(148.8000 mm, 388.8150 mm): Pad 5 [unconnected-(J24-TMDS_D1_SH-Pad5)] of J24 on F.Cu
    @(148.8000 mm, 387.8150 mm): Pad 7 [unconnected-(J24-TMDS_D0+-Pad7)] of J24 on F.Cu
[shorting_items]: Items shorting two nets (nets unconnected-(J24-TMDS_D1_SH-Pad5) and unconnected-(J24-TMDS_D0--Pad9))
    Local override; error
    @(148.8000 mm, 388.8150 mm): Pad 5 [unconnected-(J24-TMDS_D1_SH-Pad5)] of J24 on F.Cu
    @(148.8000 mm, 386.8150 mm): Pad 9 [unconnected-(J24-TMDS_D0--Pad9)] of J24 on F.Cu
[shorting_items]: Items shorting two nets (nets unconnected-(J24-TMDS_D1--Pad6) and unconnected-(J24-TMDS_D0_SH-Pad8))
    Local override; error
    @(148.8000 mm, 388.3150 mm): Pad 6 [unconnected-(J24-TMDS_D1--Pad6)] of J24 on B.Cu
    @(148.8000 mm, 387.3150 mm): Pad 8 [unconnected-(J24-TMDS_D0_SH-Pad8)] of J24 on B.Cu
[shorting_items]: Items shorting two nets (nets unconnected-(J24-TMDS_D1--Pad6) and /HDMI In/Out/HDMI_IN_D2P)
    Local override; error
    @(148.8000 mm, 388.3150 mm): Pad 6 [unconnected-(J24-TMDS_D1--Pad6)] of J24 on B.Cu
    @(148.8000 mm, 386.3150 mm): Pad 10 [/HDMI In/Out/HDMI_IN_D2P] of J24 on B.Cu
[shorting_items]: Items shorting two nets (nets unconnected-(J24-TMDS_D0+-Pad7) and unconnected-(J24-TMDS_D0--Pad9))
    Local override; error
    @(148.8000 mm, 387.8150 mm): Pad 7 [unconnected-(J24-TMDS_D0+-Pad7)] of J24 on F.Cu
    @(148.8000 mm, 386.8150 mm): Pad 9 [unconnected-(J24-TMDS_D0--Pad9)] of J24 on F.Cu
[shorting_items]: Items shorting two nets (nets unconnected-(J24-TMDS_D0+-Pad7) and unconnected-(J24-TMDS_CLK_SH-Pad11))
    Local override; error
    @(148.8000 mm, 387.8150 mm): Pad 7 [unconnected-(J24-TMDS_D0+-Pad7)] of J24 on F.Cu
    @(148.8000 mm, 385.8150 mm): Pad 11 [unconnected-(J24-TMDS_CLK_SH-Pad11)] of J24 on F.Cu
[shorting_items]: Items shorting two nets (nets unconnected-(J24-TMDS_D0_SH-Pad8) and /HDMI In/Out/HDMI_IN_D2P)
    Local override; error
    @(148.8000 mm, 387.3150 mm): Pad 8 [unconnected-(J24-TMDS_D0_SH-Pad8)] of J24 on B.Cu
    @(148.8000 mm, 386.3150 mm): Pad 10 [/HDMI In/Out/HDMI_IN_D2P] of J24 on B.Cu
[shorting_items]: Items shorting two nets (nets unconnected-(J24-TMDS_D0_SH-Pad8) and /HDMI In/Out/HDMI_IN_D2N)
    Local override; error
    @(148.8000 mm, 387.3150 mm): Pad 8 [unconnected-(J24-TMDS_D0_SH-Pad8)] of J24 on B.Cu
    @(148.8000 mm, 385.3150 mm): Pad 12 [/HDMI In/Out/HDMI_IN_D2N] of J24 on B.Cu
[shorting_items]: Items shorting two nets (nets unconnected-(J24-TMDS_D0--Pad9) and unconnected-(J24-TMDS_CLK_SH-Pad11))
    Local override; error
    @(148.8000 mm, 386.8150 mm): Pad 9 [unconnected-(J24-TMDS_D0--Pad9)] of J24 on F.Cu
    @(148.8000 mm, 385.8150 mm): Pad 11 [unconnected-(J24-TMDS_CLK_SH-Pad11)] of J24 on F.Cu
[shorting_items]: Items shorting two nets (nets unconnected-(J24-TMDS_D0--Pad9) and unconnected-(J24-CEC-Pad13))
    Local override; error
    @(148.8000 mm, 386.8150 mm): Pad 9 [unconnected-(J24-TMDS_D0--Pad9)] of J24 on F.Cu
    @(148.8000 mm, 384.8150 mm): Pad 13 [unconnected-(J24-CEC-Pad13)] of J24 on F.Cu
[shorting_items]: Items shorting two nets (nets /HDMI In/Out/HDMI_IN_D2P and /HDMI In/Out/HDMI_IN_D2N)
    Local override; error
    @(148.8000 mm, 386.3150 mm): Pad 10 [/HDMI In/Out/HDMI_IN_D2P] of J24 on B.Cu
    @(148.8000 mm, 385.3150 mm): Pad 12 [/HDMI In/Out/HDMI_IN_D2N] of J24 on B.Cu
[shorting_items]: Items shorting two nets (nets /HDMI In/Out/HDMI_IN_D2P and unconnected-(J24-NC-Pad14))
    Local override; error
    @(148.8000 mm, 386.3150 mm): Pad 10 [/HDMI In/Out/HDMI_IN_D2P] of J24 on B.Cu
    @(148.8000 mm, 384.3150 mm): Pad 14 [unconnected-(J24-NC-Pad14)] of J24 on B.Cu
[shorting_items]: Items shorting two nets (nets unconnected-(J24-TMDS_CLK_SH-Pad11) and unconnected-(J24-CEC-Pad13))
    Local override; error
    @(148.8000 mm, 385.8150 mm): Pad 11 [unconnected-(J24-TMDS_CLK_SH-Pad11)] of J24 on F.Cu
    @(148.8000 mm, 384.8150 mm): Pad 13 [unconnected-(J24-CEC-Pad13)] of J24 on F.Cu
[shorting_items]: Items shorting two nets (nets unconnected-(J24-TMDS_CLK_SH-Pad11) and /HDMI In/Out/HDMI_IN_D1P)
    Local override; error
    @(148.8000 mm, 385.8150 mm): Pad 11 [unconnected-(J24-TMDS_CLK_SH-Pad11)] of J24 on F.Cu
    @(148.8000 mm, 383.8150 mm): Pad 15 [/HDMI In/Out/HDMI_IN_D1P] of J24 on F.Cu
[shorting_items]: Items shorting two nets (nets /HDMI In/Out/HDMI_IN_D2N and unconnected-(J24-NC-Pad14))
    Local override; error
    @(148.8000 mm, 385.3150 mm): Pad 12 [/HDMI In/Out/HDMI_IN_D2N] of J24 on B.Cu
    @(148.8000 mm, 384.3150 mm): Pad 14 [unconnected-(J24-NC-Pad14)] of J24 on B.Cu
[shorting_items]: Items shorting two nets (nets /HDMI In/Out/HDMI_IN_D2N and /HDMI In/Out/HDMI_IN_D1N)
    Local override; error
    @(148.8000 mm, 385.3150 mm): Pad 12 [/HDMI In/Out/HDMI_IN_D2N] of J24 on B.Cu
    @(148.8000 mm, 383.3150 mm): Pad 16 [/HDMI In/Out/HDMI_IN_D1N] of J24 on B.Cu
[shorting_items]: Items shorting two nets (nets unconnected-(J24-CEC-Pad13) and /HDMI In/Out/HDMI_IN_D1P)
    Local override; error
    @(148.8000 mm, 384.8150 mm): Pad 13 [unconnected-(J24-CEC-Pad13)] of J24 on F.Cu
    @(148.8000 mm, 383.8150 mm): Pad 15 [/HDMI In/Out/HDMI_IN_D1P] of J24 on F.Cu
[shorting_items]: Items shorting two nets (nets unconnected-(J24-CEC-Pad13) and unconnected-(J24-GND-Pad17))
    Local override; error
    @(148.8000 mm, 384.8150 mm): Pad 13 [unconnected-(J24-CEC-Pad13)] of J24 on F.Cu
    @(148.8000 mm, 382.8150 mm): Pad 17 [unconnected-(J24-GND-Pad17)] of J24 on F.Cu
[shorting_items]: Items shorting two nets (nets unconnected-(J24-NC-Pad14) and /HDMI In/Out/HDMI_IN_D1N)
    Local override; error
    @(148.8000 mm, 384.3150 mm): Pad 14 [unconnected-(J24-NC-Pad14)] of J24 on B.Cu
    @(148.8000 mm, 383.3150 mm): Pad 16 [/HDMI In/Out/HDMI_IN_D1N] of J24 on B.Cu
[shorting_items]: Items shorting two nets (nets unconnected-(J24-NC-Pad14) and unconnected-(J24-+5V-Pad18))
    Local override; error
    @(148.8000 mm, 384.3150 mm): Pad 14 [unconnected-(J24-NC-Pad14)] of J24 on B.Cu
    @(148.8000 mm, 382.3150 mm): Pad 18 [unconnected-(J24-+5V-Pad18)] of J24 on B.Cu
[shorting_items]: Items shorting two nets (nets /HDMI In/Out/HDMI_IN_D1P and unconnected-(J24-GND-Pad17))
    Local override; error
    @(148.8000 mm, 383.8150 mm): Pad 15 [/HDMI In/Out/HDMI_IN_D1P] of J24 on F.Cu
    @(148.8000 mm, 382.8150 mm): Pad 17 [unconnected-(J24-GND-Pad17)] of J24 on F.Cu
[shorting_items]: Items shorting two nets (nets /HDMI In/Out/HDMI_IN_D1P and unconnected-(J24-HPD-Pad19))
    Local override; error
    @(148.8000 mm, 383.8150 mm): Pad 15 [/HDMI In/Out/HDMI_IN_D1P] of J24 on F.Cu
    @(148.8000 mm, 381.8150 mm): Pad 19 [unconnected-(J24-HPD-Pad19)] of J24 on F.Cu
[shorting_items]: Items shorting two nets (nets /HDMI In/Out/HDMI_IN_D1N and unconnected-(J24-+5V-Pad18))
    Local override; error
    @(148.8000 mm, 383.3150 mm): Pad 16 [/HDMI In/Out/HDMI_IN_D1N] of J24 on B.Cu
    @(148.8000 mm, 382.3150 mm): Pad 18 [unconnected-(J24-+5V-Pad18)] of J24 on B.Cu
[shorting_items]: Items shorting two nets (nets unconnected-(J24-GND-Pad17) and unconnected-(J24-HPD-Pad19))
    Local override; error
    @(148.8000 mm, 382.8150 mm): Pad 17 [unconnected-(J24-GND-Pad17)] of J24 on F.Cu
    @(148.8000 mm, 381.8150 mm): Pad 19 [unconnected-(J24-HPD-Pad19)] of J24 on F.Cu
[clearance]: Clearance violation (netclass 'Default' clearance 0.2000 mm; actual 0.0750 mm)
    Rule: netclass 'Default'; error
    @(148.8000 mm, 382.3150 mm): Pad 18 [unconnected-(J24-+5V-Pad18)] of J24 on B.Cu
    @(148.9000 mm, 379.5400 mm): Pad SH [<no net>] of J24 on B.Cu
[clearance]: Clearance violation (netclass 'Default' clearance 0.2000 mm; actual 0.0000 mm)
    Rule: netclass 'Default'; error
    @(148.8000 mm, 381.8150 mm): Pad 19 [unconnected-(J24-HPD-Pad19)] of J24 on F.Cu
    @(148.9000 mm, 379.5400 mm): Pad SH [<no net>] of J24 on F.Cu
[courtyards_overlap]: Courtyards overlap
    Rule: board setup constraints courtyard; error
    @(103.8250 mm, 37.4450 mm): Footprint J7
    @(108.8250 mm, 39.4450 mm): Footprint U13
[courtyards_overlap]: Courtyards overlap
    Rule: board setup constraints courtyard; error
    @(127.3700 mm, 369.1400 mm): Footprint Y9
    @(122.3700 mm, 362.1400 mm): Footprint U41
[courtyards_overlap]: Courtyards overlap
    Rule: board setup constraints courtyard; error
    @(113.8250 mm, 37.4450 mm): Footprint J10
    @(108.8250 mm, 39.4450 mm): Footprint U13
[courtyards_overlap]: Courtyards overlap
    Rule: board setup constraints courtyard; error
    @(113.8250 mm, 37.4450 mm): Footprint J10
    @(113.8250 mm, 47.4450 mm): Footprint J11
[courtyards_overlap]: Courtyards overlap
    Rule: board setup constraints courtyard; error
    @(113.8250 mm, 57.4450 mm): Footprint J12
    @(113.8250 mm, 47.4450 mm): Footprint J11
[courtyards_overlap]: Courtyards overlap
    Rule: board setup constraints courtyard; error
    @(108.8250 mm, 39.4450 mm): Footprint U13
    @(113.8250 mm, 47.4450 mm): Footprint J11
[courtyards_overlap]: Courtyards overlap
    Rule: board setup constraints courtyard; error
    @(269.6700 mm, 67.5100 mm): Footprint J4
    @(269.6700 mm, 55.5100 mm): Footprint J3
[courtyards_overlap]: Courtyards overlap
    Rule: board setup constraints courtyard; error
    @(50.2550 mm, 180.9450 mm): Footprint U28
    @(35.2550 mm, 180.9450 mm): Footprint U27
[courtyards_overlap]: Courtyards overlap
    Rule: board setup constraints courtyard; error
    @(123.8250 mm, 51.4450 mm): Footprint U17
    @(113.8250 mm, 47.4450 mm): Footprint J11
[courtyards_overlap]: Courtyards overlap
    Rule: board setup constraints courtyard; error
    @(269.6700 mm, 55.5100 mm): Footprint J3
    @(269.6700 mm, 43.5100 mm): Footprint J2
[courtyards_overlap]: Courtyards overlap
    Rule: board setup constraints courtyard; error
    @(113.8250 mm, 47.4450 mm): Footprint J11
    @(123.8250 mm, 39.4450 mm): Footprint U14
[courtyards_overlap]: Courtyards overlap
    Rule: board setup constraints courtyard; error
    @(113.8250 mm, 47.4450 mm): Footprint J11
    @(108.8250 mm, 51.4450 mm): Footprint U16
[courtyards_overlap]: Courtyards overlap
    Rule: board setup constraints courtyard; error
    @(269.6700 mm, 43.5100 mm): Footprint J2
    @(269.6700 mm, 31.5100 mm): Footprint J1
[courtyards_overlap]: Courtyards overlap
    Rule: board setup constraints courtyard; error
    @(137.3700 mm, 377.1400 mm): Footprint U44
    @(137.3700 mm, 375.1400 mm): Footprint U45
[courtyards_overlap]: Courtyards overlap
    Rule: board setup constraints courtyard; error
    @(103.8250 mm, 47.4450 mm): Footprint J8
    @(108.8250 mm, 51.4450 mm): Footprint U16
[solder_mask_bridge]: Front solder mask aperture bridges items with different nets
    Rule: board setup solder mask min width; error
    @(126.1200 mm, 369.1400 mm): Pad 2 [unconnected-(Y9-Pad2)] of Y9 on F.Cu
    @(125.6200 mm, 367.8150 mm): Pad 31 [<no net>] of U41 on F.Cu
[solder_mask_bridge]: Front solder mask aperture bridges items with different nets
    Rule: board setup solder mask min width; error
    @(126.1200 mm, 369.1400 mm): Pad 2 [unconnected-(Y9-Pad2)] of Y9 on F.Cu
    @(126.1200 mm, 367.8150 mm): Pad 32 [<no net>] of U41 on F.Cu
[solder_mask_bridge]: Front solder mask aperture bridges items with different nets
    Rule: board setup solder mask min width; error
    @(272.3800 mm, 57.4400 mm): PTH pad 5 [unconnected-(J4-SHIELD-Pad5)] of J4
    @(272.3800 mm, 58.5800 mm): PTH pad 5 [unconnected-(J3-SHIELD-Pad5)] of J3
[solder_mask_bridge]: Rear solder mask aperture bridges items with different nets
    Rule: board setup solder mask min width; error
    @(272.3800 mm, 57.4400 mm): PTH pad 5 [unconnected-(J4-SHIELD-Pad5)] of J4
    @(272.3800 mm, 58.5800 mm): PTH pad 5 [unconnected-(J3-SHIELD-Pad5)] of J3
[solder_mask_bridge]: Front solder mask aperture bridges items with different nets
    Rule: board setup solder mask min width; error
    @(42.6050 mm, 177.5450 mm): Pad 1 [Net-(U26-VIN)] of U28 on F.Cu
    @(36.7550 mm, 180.9450 mm): Pad 3 [GND] of U27 on F.Cu
[solder_mask_bridge]: Front solder mask aperture bridges items with different nets
    Rule: board setup solder mask min width; error
    @(42.6050 mm, 179.2450 mm): Pad 2 [Net-(D14-A)] of U28 on F.Cu
    @(36.7550 mm, 180.9450 mm): Pad 3 [GND] of U27 on F.Cu
[solder_mask_bridge]: Front solder mask aperture bridges items with different nets
    Rule: board setup solder mask min width; error
    @(42.6050 mm, 182.6450 mm): Pad 4 [unconnected-(U28-FB-Pad4)] of U28 on F.Cu
    @(36.7550 mm, 180.9450 mm): Pad 3 [GND] of U27 on F.Cu
[solder_mask_bridge]: Front solder mask aperture bridges items with different nets
    Rule: board setup solder mask min width; error
    @(42.6050 mm, 184.3450 mm): Pad 5 [unconnected-(U28-~{ON}/OFF-Pad5)] of U28 on F.Cu
    @(36.7550 mm, 180.9450 mm): Pad 3 [GND] of U27 on F.Cu
[solder_mask_bridge]: Front solder mask aperture bridges items with different nets
    Rule: board setup solder mask min width; error
    @(121.3750 mm, 50.4450 mm): Pad 2 [unconnected-(U17-D--Pad2)] of U17 on F.Cu
    @(120.7000 mm, 51.5950 mm): Pad 9 [unconnected-(J11-CD-Pad9)] of J11 on F.Cu
[solder_mask_bridge]: Front solder mask aperture bridges items with different nets
    Rule: board setup solder mask min width; error
    @(121.3750 mm, 50.9450 mm): Pad 3 [unconnected-(U17-VBUS-Pad3)] of U17 on F.Cu
    @(120.7000 mm, 51.5950 mm): Pad 9 [unconnected-(J11-CD-Pad9)] of J11 on F.Cu
[solder_mask_bridge]: Front solder mask aperture bridges items with different nets
    Rule: board setup solder mask min width; error
    @(121.3750 mm, 51.4450 mm): Pad 4 [unconnected-(U17-TXD-Pad4)] of U17 on F.Cu
    @(120.7000 mm, 51.5950 mm): Pad 9 [unconnected-(J11-CD-Pad9)] of J11 on F.Cu
[solder_mask_bridge]: Front solder mask aperture bridges items with different nets
    Rule: board setup solder mask min width; error
    @(121.3750 mm, 51.9450 mm): Pad 5 [unconnected-(U17-RXD-Pad5)] of U17 on F.Cu
    @(120.7000 mm, 51.5950 mm): Pad 9 [unconnected-(J11-CD-Pad9)] of J11 on F.Cu
[solder_mask_bridge]: Front solder mask aperture bridges items with different nets
    Rule: board setup solder mask min width; error
    @(121.3750 mm, 52.4450 mm): Pad 6 [unconnected-(U17-RTS-Pad6)] of U17 on F.Cu
    @(120.7000 mm, 51.5950 mm): Pad 9 [unconnected-(J11-CD-Pad9)] of J11 on F.Cu
[solder_mask_bridge]: Front solder mask aperture bridges items with different nets
    Rule: board setup solder mask min width; error
    @(272.3800 mm, 45.4400 mm): PTH pad 5 [unconnected-(J3-SHIELD-Pad5)] of J3
    @(272.3800 mm, 46.5800 mm): PTH pad 5 [unconnected-(J2-SHIELD-Pad5)] of J2
[solder_mask_bridge]: Rear solder mask aperture bridges items with different nets
    Rule: board setup solder mask min width; error
    @(272.3800 mm, 45.4400 mm): PTH pad 5 [unconnected-(J3-SHIELD-Pad5)] of J3
    @(272.3800 mm, 46.5800 mm): PTH pad 5 [unconnected-(J2-SHIELD-Pad5)] of J2
[solder_mask_bridge]: Front solder mask aperture bridges items with different nets
    Rule: board setup solder mask min width; error
    @(106.9500 mm, 51.5950 mm): Pad 9 [unconnected-(J11-CD-Pad9)] of J11 on F.Cu
    @(106.3500 mm, 50.8100 mm): Pad 2 [unconnected-(U16-~{RE}-Pad2)] of U16 on F.Cu
[solder_mask_bridge]: Front solder mask aperture bridges items with different nets
    Rule: board setup solder mask min width; error
    @(106.9500 mm, 51.5950 mm): Pad 9 [unconnected-(J11-CD-Pad9)] of J11 on F.Cu
    @(106.3500 mm, 52.0800 mm): Pad 3 [unconnected-(U16-DE-Pad3)] of U16 on F.Cu
[solder_mask_bridge]: Front solder mask aperture bridges items with different nets
    Rule: board setup solder mask min width; error
    @(272.3800 mm, 33.4400 mm): PTH pad 5 [unconnected-(J2-SHIELD-Pad5)] of J2
    @(272.3800 mm, 34.5800 mm): PTH pad 5 [unconnected-(J1-SHIELD-Pad5)] of J1
[solder_mask_bridge]: Rear solder mask aperture bridges items with different nets
    Rule: board setup solder mask min width; error
    @(272.3800 mm, 33.4400 mm): PTH pad 5 [unconnected-(J2-SHIELD-Pad5)] of J2
    @(272.3800 mm, 34.5800 mm): PTH pad 5 [unconnected-(J1-SHIELD-Pad5)] of J1
[solder_mask_bridge]: Front solder mask aperture bridges items with different nets
    Rule: board setup solder mask min width; error
    @(135.4075 mm, 375.8900 mm): Pad 1 [/HDMI In/Out/HDMI_IN_D2P] of U44 on F.Cu
    @(135.4075 mm, 375.8900 mm): Pad 5 [Net-(U41-CEC)] of U45 on F.Cu
[solder_mask_bridge]: Front solder mask aperture bridges items with different nets
    Rule: board setup solder mask min width; error
    @(135.4075 mm, 376.3900 mm): Pad 2 [unconnected-(U44-D2--Pad2)] of U44 on F.Cu
    @(135.4075 mm, 376.3900 mm): Pad 6 [Net-(U41-CEC)] of U45 on F.Cu
[solder_mask_bridge]: Front solder mask aperture bridges items with different nets
    Rule: board setup solder mask min width; error
    @(139.3325 mm, 376.3900 mm): Pad 17 [Net-(U43-CEC)] of U44 on F.Cu
    @(139.3325 mm, 376.3900 mm): Pad 13 [Net-(J23-TMDS_D1+)] of U45 on F.Cu
[solder_mask_bridge]: Front solder mask aperture bridges items with different nets
    Rule: board setup solder mask min width; error
    @(139.3325 mm, 375.8900 mm): Pad 18 [<no net>] of U44 on F.Cu
    @(139.3325 mm, 375.8900 mm): Pad 14 [Net-(J23-TMDS_D1_SH)] of U45 on F.Cu
[solder_mask_bridge]: Front solder mask aperture bridges items with different nets
    Rule: board setup solder mask min width; error
    @(138.6200 mm, 375.1775 mm): Pad 19 [<no net>] of U44 on F.Cu
    @(137.3700 mm, 375.1400 mm): Pad 25 [<no net>] of U45 on F.Cu
[solder_mask_bridge]: Front solder mask aperture bridges items with different nets
    Rule: board setup solder mask min width; error
    @(138.1200 mm, 375.1775 mm): Pad 20 [<no net>] of U44 on F.Cu
    @(137.3700 mm, 375.1400 mm): Pad 25 [<no net>] of U45 on F.Cu
[solder_mask_bridge]: Front solder mask aperture bridges items with different nets
    Rule: board setup solder mask min width; error
    @(137.6200 mm, 375.1775 mm): Pad 21 [<no net>] of U44 on F.Cu
    @(137.3700 mm, 375.1400 mm): Pad 25 [<no net>] of U45 on F.Cu
[solder_mask_bridge]: Front solder mask aperture bridges items with different nets
    Rule: board setup solder mask min width; error
    @(137.1200 mm, 375.1775 mm): Pad 22 [<no net>] of U44 on F.Cu
    @(137.3700 mm, 375.1400 mm): Pad 25 [<no net>] of U45 on F.Cu
[solder_mask_bridge]: Front solder mask aperture bridges items with different nets
    Rule: board setup solder mask min width; error
    @(136.6200 mm, 375.1775 mm): Pad 23 [<no net>] of U44 on F.Cu
    @(137.3700 mm, 375.1400 mm): Pad 25 [<no net>] of U45 on F.Cu
[solder_mask_bridge]: Front solder mask aperture bridges items with different nets
    Rule: board setup solder mask min width; error
    @(136.1200 mm, 375.1775 mm): Pad 24 [<no net>] of U44 on F.Cu
    @(137.3700 mm, 375.1400 mm): Pad 25 [<no net>] of U45 on F.Cu
[solder_mask_bridge]: Front solder mask aperture bridges items with different nets
    Rule: board setup solder mask min width; error
    @(137.3700 mm, 377.1400 mm): Pad 25 [<no net>] of U44 on F.Cu
    @(137.3700 mm, 375.1400 mm): Pad 25 [<no net>] of U45 on F.Cu
[solder_mask_bridge]: Front solder mask aperture bridges items with different nets
    Rule: board setup solder mask min width; error
    @(137.3700 mm, 377.1400 mm): Pad 25 [<no net>] of U44 on F.Cu
    @(136.1200 mm, 377.1025 mm): Pad 7 [Net-(U41-CEC)] of U45 on F.Cu
[solder_mask_bridge]: Front solder mask aperture bridges items with different nets
    Rule: board setup solder mask min width; error
    @(137.3700 mm, 377.1400 mm): Pad 25 [<no net>] of U44 on F.Cu
    @(136.6200 mm, 377.1025 mm): Pad 8 [Net-(U41-CEC)] of U45 on F.Cu
[solder_mask_bridge]: Front solder mask aperture bridges items with different nets
    Rule: board setup solder mask min width; error
    @(137.3700 mm, 377.1400 mm): Pad 25 [<no net>] of U44 on F.Cu
    @(137.1200 mm, 377.1025 mm): Pad 9 [Net-(U41-CEC)] of U45 on F.Cu
[solder_mask_bridge]: Front solder mask aperture bridges items with different nets
    Rule: board setup solder mask min width; error
    @(137.3700 mm, 377.1400 mm): Pad 25 [<no net>] of U44 on F.Cu
    @(137.6200 mm, 377.1025 mm): Pad 10 [Net-(J23-TMDS_D2+)] of U45 on F.Cu
[solder_mask_bridge]: Front solder mask aperture bridges items with different nets
    Rule: board setup solder mask min width; error
    @(137.3700 mm, 377.1400 mm): Pad 25 [<no net>] of U44 on F.Cu
    @(138.1200 mm, 377.1025 mm): Pad 11 [Net-(J23-TMDS_D2_SH)] of U45 on F.Cu
[solder_mask_bridge]: Front solder mask aperture bridges items with different nets
    Rule: board setup solder mask min width; error
    @(137.3700 mm, 377.1400 mm): Pad 25 [<no net>] of U44 on F.Cu
    @(138.6200 mm, 377.1025 mm): Pad 12 [Net-(J23-TMDS_D2-)] of U45 on F.Cu
[solder_mask_bridge]: Front solder mask aperture bridges items with different nets
    Rule: board setup solder mask min width; error
    @(168.7200 mm, 389.4000 mm): Pad 1 [Net-(J23-TMDS_D2+)] of J23 on F.Cu
    @(168.7200 mm, 388.4000 mm): Pad 3 [Net-(J23-TMDS_D2-)] of J23 on F.Cu
[solder_mask_bridge]: Front solder mask aperture bridges items with different nets
    Rule: board setup solder mask min width; error
    @(168.7200 mm, 389.4000 mm): Pad 1 [Net-(J23-TMDS_D2+)] of J23 on F.Cu
    @(168.7200 mm, 387.4000 mm): Pad 5 [Net-(J23-TMDS_D1_SH)] of J23 on F.Cu
[solder_mask_bridge]: Front solder mask aperture bridges items with different nets
    Rule: board setup solder mask min width; error
    @(168.7200 mm, 389.4000 mm): Pad 1 [Net-(J23-TMDS_D2+)] of J23 on F.Cu
    @(168.8200 mm, 391.6750 mm): Pad SH [<no net>] of J23 on F.Cu
[solder_mask_bridge]: Rear solder mask aperture bridges items with different nets
    Rule: board setup solder mask min width; error
    @(168.7200 mm, 388.9000 mm): Pad 2 [Net-(J23-TMDS_D2_SH)] of J23 on B.Cu
    @(168.7200 mm, 387.9000 mm): Pad 4 [Net-(J23-TMDS_D1+)] of J23 on B.Cu
[solder_mask_bridge]: Rear solder mask aperture bridges items with different nets
    Rule: board setup solder mask min width; error
    @(168.7200 mm, 388.9000 mm): Pad 2 [Net-(J23-TMDS_D2_SH)] of J23 on B.Cu
    @(168.7200 mm, 386.9000 mm): Pad 6 [Net-(J23-TMDS_D1-)] of J23 on B.Cu
[solder_mask_bridge]: Rear solder mask aperture bridges items with different nets
    Rule: board setup solder mask min width; error
    @(168.7200 mm, 388.9000 mm): Pad 2 [Net-(J23-TMDS_D2_SH)] of J23 on B.Cu
    @(168.8200 mm, 391.6750 mm): Pad SH [<no net>] of J23 on B.Cu
[solder_mask_bridge]: Front solder mask aperture bridges items with different nets
    Rule: board setup solder mask min width; error
    @(168.7200 mm, 388.4000 mm): Pad 3 [Net-(J23-TMDS_D2-)] of J23 on F.Cu
    @(168.7200 mm, 387.4000 mm): Pad 5 [Net-(J23-TMDS_D1_SH)] of J23 on F.Cu
[solder_mask_bridge]: Front solder mask aperture bridges items with different nets
    Rule: board setup solder mask min width; error
    @(168.7200 mm, 388.4000 mm): Pad 3 [Net-(J23-TMDS_D2-)] of J23 on F.Cu
    @(168.7200 mm, 386.4000 mm): Pad 7 [Net-(J23-TMDS_D0+)] of J23 on F.Cu
[solder_mask_bridge]: Rear solder mask aperture bridges items with different nets
    Rule: board setup solder mask min width; error
    @(168.7200 mm, 387.9000 mm): Pad 4 [Net-(J23-TMDS_D1+)] of J23 on B.Cu
    @(168.7200 mm, 386.9000 mm): Pad 6 [Net-(J23-TMDS_D1-)] of J23 on B.Cu
[solder_mask_bridge]: Rear solder mask aperture bridges items with different nets
    Rule: board setup solder mask min width; error
    @(168.7200 mm, 387.9000 mm): Pad 4 [Net-(J23-TMDS_D1+)] of J23 on B.Cu
    @(168.7200 mm, 385.9000 mm): Pad 8 [Net-(J23-TMDS_D0_SH)] of J23 on B.Cu
[solder_mask_bridge]: Front solder mask aperture bridges items with different nets
    Rule: board setup solder mask min width; error
    @(168.7200 mm, 387.4000 mm): Pad 5 [Net-(J23-TMDS_D1_SH)] of J23 on F.Cu
    @(168.7200 mm, 386.4000 mm): Pad 7 [Net-(J23-TMDS_D0+)] of J23 on F.Cu
[solder_mask_bridge]: Front solder mask aperture bridges items with different nets
    Rule: board setup solder mask min width; error
    @(168.7200 mm, 387.4000 mm): Pad 5 [Net-(J23-TMDS_D1_SH)] of J23 on F.Cu
    @(168.7200 mm, 385.4000 mm): Pad 9 [unconnected-(J23-TMDS_D0--Pad9)] of J23 on F.Cu
[solder_mask_bridge]: Rear solder mask aperture bridges items with different nets
    Rule: board setup solder mask min width; error
    @(168.7200 mm, 386.9000 mm): Pad 6 [Net-(J23-TMDS_D1-)] of J23 on B.Cu
    @(168.7200 mm, 385.9000 mm): Pad 8 [Net-(J23-TMDS_D0_SH)] of J23 on B.Cu
[solder_mask_bridge]: Rear solder mask aperture bridges items with different nets
    Rule: board setup solder mask min width; error
    @(168.7200 mm, 386.9000 mm): Pad 6 [Net-(J23-TMDS_D1-)] of J23 on B.Cu
    @(168.7200 mm, 384.9000 mm): Pad 10 [unconnected-(J23-TMDS_CLK+-Pad10)] of J23 on B.Cu
[solder_mask_bridge]: Front solder mask aperture bridges items with different nets
    Rule: board setup solder mask min width; error
    @(168.7200 mm, 386.4000 mm): Pad 7 [Net-(J23-TMDS_D0+)] of J23 on F.Cu
    @(168.7200 mm, 385.4000 mm): Pad 9 [unconnected-(J23-TMDS_D0--Pad9)] of J23 on F.Cu
[solder_mask_bridge]: Front solder mask aperture bridges items with different nets
    Rule: board setup solder mask min width; error
    @(168.7200 mm, 386.4000 mm): Pad 7 [Net-(J23-TMDS_D0+)] of J23 on F.Cu
    @(168.7200 mm, 384.4000 mm): Pad 11 [unconnected-(J23-TMDS_CLK_SH-Pad11)] of J23 on F.Cu
[solder_mask_bridge]: Rear solder mask aperture bridges items with different nets
    Rule: board setup solder mask min width; error
    @(168.7200 mm, 385.9000 mm): Pad 8 [Net-(J23-TMDS_D0_SH)] of J23 on B.Cu
    @(168.7200 mm, 384.9000 mm): Pad 10 [unconnected-(J23-TMDS_CLK+-Pad10)] of J23 on B.Cu
[solder_mask_bridge]: Rear solder mask aperture bridges items with different nets
    Rule: board setup solder mask min width; error
    @(168.7200 mm, 385.9000 mm): Pad 8 [Net-(J23-TMDS_D0_SH)] of J23 on B.Cu
    @(168.7200 mm, 383.9000 mm): Pad 12 [unconnected-(J23-TMDS_CLK--Pad12)] of J23 on B.Cu
[solder_mask_bridge]: Front solder mask aperture bridges items with different nets
    Rule: board setup solder mask min width; error
    @(168.7200 mm, 385.4000 mm): Pad 9 [unconnected-(J23-TMDS_D0--Pad9)] of J23 on F.Cu
    @(168.7200 mm, 384.4000 mm): Pad 11 [unconnected-(J23-TMDS_CLK_SH-Pad11)] of J23 on F.Cu
[solder_mask_bridge]: Front solder mask aperture bridges items with different nets
    Rule: board setup solder mask min width; error
    @(168.7200 mm, 385.4000 mm): Pad 9 [unconnected-(J23-TMDS_D0--Pad9)] of J23 on F.Cu
    @(168.7200 mm, 383.4000 mm): Pad 13 [unconnected-(J23-CEC-Pad13)] of J23 on F.Cu
[solder_mask_bridge]: Rear solder mask aperture bridges items with different nets
    Rule: board setup solder mask min width; error
    @(168.7200 mm, 384.9000 mm): Pad 10 [unconnected-(J23-TMDS_CLK+-Pad10)] of J23 on B.Cu
    @(168.7200 mm, 383.9000 mm): Pad 12 [unconnected-(J23-TMDS_CLK--Pad12)] of J23 on B.Cu
[solder_mask_bridge]: Rear solder mask aperture bridges items with different nets
    Rule: board setup solder mask min width; error
    @(168.7200 mm, 384.9000 mm): Pad 10 [unconnected-(J23-TMDS_CLK+-Pad10)] of J23 on B.Cu
    @(168.7200 mm, 382.9000 mm): Pad 14 [unconnected-(J23-NC-Pad14)] of J23 on B.Cu
[solder_mask_bridge]: Front solder mask aperture bridges items with different nets
    Rule: board setup solder mask min width; error
    @(168.7200 mm, 384.4000 mm): Pad 11 [unconnected-(J23-TMDS_CLK_SH-Pad11)] of J23 on F.Cu
    @(168.7200 mm, 383.4000 mm): Pad 13 [unconnected-(J23-CEC-Pad13)] of J23 on F.Cu
[solder_mask_bridge]: Front solder mask aperture bridges items with different nets
    Rule: board setup solder mask min width; error
    @(168.7200 mm, 384.4000 mm): Pad 11 [unconnected-(J23-TMDS_CLK_SH-Pad11)] of J23 on F.Cu
    @(168.7200 mm, 382.4000 mm): Pad 15 [unconnected-(J23-SCL-Pad15)] of J23 on F.Cu
[solder_mask_bridge]: Rear solder mask aperture bridges items with different nets
    Rule: board setup solder mask min width; error
    @(168.7200 mm, 383.9000 mm): Pad 12 [unconnected-(J23-TMDS_CLK--Pad12)] of J23 on B.Cu
    @(168.7200 mm, 382.9000 mm): Pad 14 [unconnected-(J23-NC-Pad14)] of J23 on B.Cu
[solder_mask_bridge]: Rear solder mask aperture bridges items with different nets
    Rule: board setup solder mask min width; error
    @(168.7200 mm, 383.9000 mm): Pad 12 [unconnected-(J23-TMDS_CLK--Pad12)] of J23 on B.Cu
    @(168.7200 mm, 381.9000 mm): Pad 16 [unconnected-(J23-SDA-Pad16)] of J23 on B.Cu
[solder_mask_bridge]: Front solder mask aperture bridges items with different nets
    Rule: board setup solder mask min width; error
    @(168.7200 mm, 383.4000 mm): Pad 13 [unconnected-(J23-CEC-Pad13)] of J23 on F.Cu
    @(168.7200 mm, 382.4000 mm): Pad 15 [unconnected-(J23-SCL-Pad15)] of J23 on F.Cu
[solder_mask_bridge]: Front solder mask aperture bridges items with different nets
    Rule: board setup solder mask min width; error
    @(168.7200 mm, 383.4000 mm): Pad 13 [unconnected-(J23-CEC-Pad13)] of J23 on F.Cu
    @(168.7200 mm, 381.4000 mm): Pad 17 [GND] of J23 on F.Cu
[solder_mask_bridge]: Rear solder mask aperture bridges items with different nets
    Rule: board setup solder mask min width; error
    @(168.7200 mm, 382.9000 mm): Pad 14 [unconnected-(J23-NC-Pad14)] of J23 on B.Cu
    @(168.7200 mm, 381.9000 mm): Pad 16 [unconnected-(J23-SDA-Pad16)] of J23 on B.Cu
[solder_mask_bridge]: Rear solder mask aperture bridges items with different nets
    Rule: board setup solder mask min width; error
    @(168.7200 mm, 382.9000 mm): Pad 14 [unconnected-(J23-NC-Pad14)] of J23 on B.Cu
    @(168.7200 mm, 380.9000 mm): Pad 18 [unconnected-(J23-+5V-Pad18)] of J23 on B.Cu
[solder_mask_bridge]: Front solder mask aperture bridges items with different nets
    Rule: board setup solder mask min width; error
    @(168.7200 mm, 382.4000 mm): Pad 15 [unconnected-(J23-SCL-Pad15)] of J23 on F.Cu
    @(168.7200 mm, 381.4000 mm): Pad 17 [GND] of J23 on F.Cu
[solder_mask_bridge]: Front solder mask aperture bridges items with different nets
    Rule: board setup solder mask min width; error
    @(168.7200 mm, 382.4000 mm): Pad 15 [unconnected-(J23-SCL-Pad15)] of J23 on F.Cu
    @(168.7200 mm, 380.4000 mm): Pad 19 [unconnected-(J23-HPD-Pad19)] of J23 on F.Cu
[solder_mask_bridge]: Rear solder mask aperture bridges items with different nets
    Rule: board setup solder mask min width; error
    @(168.7200 mm, 381.9000 mm): Pad 16 [unconnected-(J23-SDA-Pad16)] of J23 on B.Cu
    @(168.7200 mm, 380.9000 mm): Pad 18 [unconnected-(J23-+5V-Pad18)] of J23 on B.Cu
[solder_mask_bridge]: Front solder mask aperture bridges items with different nets
    Rule: board setup solder mask min width; error
    @(168.7200 mm, 381.4000 mm): Pad 17 [GND] of J23 on F.Cu
    @(168.7200 mm, 380.4000 mm): Pad 19 [unconnected-(J23-HPD-Pad19)] of J23 on F.Cu
[solder_mask_bridge]: Rear solder mask aperture bridges items with different nets
    Rule: board setup solder mask min width; error
    @(168.7200 mm, 380.9000 mm): Pad 18 [unconnected-(J23-+5V-Pad18)] of J23 on B.Cu
    @(168.8200 mm, 378.1250 mm): Pad SH [<no net>] of J23 on B.Cu
[solder_mask_bridge]: Front solder mask aperture bridges items with different nets
    Rule: board setup solder mask min width; error
    @(168.7200 mm, 380.4000 mm): Pad 19 [unconnected-(J23-HPD-Pad19)] of J23 on F.Cu
    @(168.8200 mm, 378.1250 mm): Pad SH [<no net>] of J23 on F.Cu
[solder_mask_bridge]: Front solder mask aperture bridges items with different nets
    Rule: board setup solder mask min width; error
    @(148.8000 mm, 390.8150 mm): Pad 1 [unconnected-(J24-TMDS_D2+-Pad1)] of J24 on F.Cu
    @(148.8000 mm, 389.8150 mm): Pad 3 [unconnected-(J24-TMDS_D2--Pad3)] of J24 on F.Cu
[solder_mask_bridge]: Front solder mask aperture bridges items with different nets
    Rule: board setup solder mask min width; error
    @(148.8000 mm, 390.8150 mm): Pad 1 [unconnected-(J24-TMDS_D2+-Pad1)] of J24 on F.Cu
    @(148.8000 mm, 388.8150 mm): Pad 5 [unconnected-(J24-TMDS_D1_SH-Pad5)] of J24 on F.Cu
[solder_mask_bridge]: Front solder mask aperture bridges items with different nets
    Rule: board setup solder mask min width; error
    @(148.8000 mm, 390.8150 mm): Pad 1 [unconnected-(J24-TMDS_D2+-Pad1)] of J24 on F.Cu
    @(148.9000 mm, 393.0900 mm): Pad SH [<no net>] of J24 on F.Cu
[solder_mask_bridge]: Rear solder mask aperture bridges items with different nets
    Rule: board setup solder mask min width; error
    @(148.8000 mm, 390.3150 mm): Pad 2 [unconnected-(J24-TMDS_D2_SH-Pad2)] of J24 on B.Cu
    @(148.8000 mm, 389.3150 mm): Pad 4 [unconnected-(J24-TMDS_D1+-Pad4)] of J24 on B.Cu
[solder_mask_bridge]: Rear solder mask aperture bridges items with different nets
    Rule: board setup solder mask min width; error
    @(148.8000 mm, 390.3150 mm): Pad 2 [unconnected-(J24-TMDS_D2_SH-Pad2)] of J24 on B.Cu
    @(148.8000 mm, 388.3150 mm): Pad 6 [unconnected-(J24-TMDS_D1--Pad6)] of J24 on B.Cu
[solder_mask_bridge]: Rear solder mask aperture bridges items with different nets
    Rule: board setup solder mask min width; error
    @(148.8000 mm, 390.3150 mm): Pad 2 [unconnected-(J24-TMDS_D2_SH-Pad2)] of J24 on B.Cu
    @(148.9000 mm, 393.0900 mm): Pad SH [<no net>] of J24 on B.Cu
[solder_mask_bridge]: Front solder mask aperture bridges items with different nets
    Rule: board setup solder mask min width; error
    @(148.8000 mm, 389.8150 mm): Pad 3 [unconnected-(J24-TMDS_D2--Pad3)] of J24 on F.Cu
    @(148.8000 mm, 388.8150 mm): Pad 5 [unconnected-(J24-TMDS_D1_SH-Pad5)] of J24 on F.Cu
[solder_mask_bridge]: Front solder mask aperture bridges items with different nets
    Rule: board setup solder mask min width; error
    @(148.8000 mm, 389.8150 mm): Pad 3 [unconnected-(J24-TMDS_D2--Pad3)] of J24 on F.Cu
    @(148.8000 mm, 387.8150 mm): Pad 7 [unconnected-(J24-TMDS_D0+-Pad7)] of J24 on F.Cu
[solder_mask_bridge]: Rear solder mask aperture bridges items with different nets
    Rule: board setup solder mask min width; error
    @(148.8000 mm, 389.3150 mm): Pad 4 [unconnected-(J24-TMDS_D1+-Pad4)] of J24 on B.Cu
    @(148.8000 mm, 388.3150 mm): Pad 6 [unconnected-(J24-TMDS_D1--Pad6)] of J24 on B.Cu
[solder_mask_bridge]: Rear solder mask aperture bridges items with different nets
    Rule: board setup solder mask min width; error
    @(148.8000 mm, 389.3150 mm): Pad 4 [unconnected-(J24-TMDS_D1+-Pad4)] of J24 on B.Cu
    @(148.8000 mm, 387.3150 mm): Pad 8 [unconnected-(J24-TMDS_D0_SH-Pad8)] of J24 on B.Cu
[solder_mask_bridge]: Front solder mask aperture bridges items with different nets
    Rule: board setup solder mask min width; error
    @(148.8000 mm, 388.8150 mm): Pad 5 [unconnected-(J24-TMDS_D1_SH-Pad5)] of J24 on F.Cu
    @(148.8000 mm, 387.8150 mm): Pad 7 [unconnected-(J24-TMDS_D0+-Pad7)] of J24 on F.Cu
[solder_mask_bridge]: Front solder mask aperture bridges items with different nets
    Rule: board setup solder mask min width; error
    @(148.8000 mm, 388.8150 mm): Pad 5 [unconnected-(J24-TMDS_D1_SH-Pad5)] of J24 on F.Cu
    @(148.8000 mm, 386.8150 mm): Pad 9 [unconnected-(J24-TMDS_D0--Pad9)] of J24 on F.Cu
[solder_mask_bridge]: Rear solder mask aperture bridges items with different nets
    Rule: board setup solder mask min width; error
    @(148.8000 mm, 388.3150 mm): Pad 6 [unconnected-(J24-TMDS_D1--Pad6)] of J24 on B.Cu
    @(148.8000 mm, 387.3150 mm): Pad 8 [unconnected-(J24-TMDS_D0_SH-Pad8)] of J24 on B.Cu
[solder_mask_bridge]: Rear solder mask aperture bridges items with different nets
    Rule: board setup solder mask min width; error
    @(148.8000 mm, 388.3150 mm): Pad 6 [unconnected-(J24-TMDS_D1--Pad6)] of J24 on B.Cu
    @(148.8000 mm, 386.3150 mm): Pad 10 [/HDMI In/Out/HDMI_IN_D2P] of J24 on B.Cu
[solder_mask_bridge]: Front solder mask aperture bridges items with different nets
    Rule: board setup solder mask min width; error
    @(148.8000 mm, 387.8150 mm): Pad 7 [unconnected-(J24-TMDS_D0+-Pad7)] of J24 on F.Cu
    @(148.8000 mm, 386.8150 mm): Pad 9 [unconnected-(J24-TMDS_D0--Pad9)] of J24 on F.Cu
[solder_mask_bridge]: Front solder mask aperture bridges items with different nets
    Rule: board setup solder mask min width; error
    @(148.8000 mm, 387.8150 mm): Pad 7 [unconnected-(J24-TMDS_D0+-Pad7)] of J24 on F.Cu
    @(148.8000 mm, 385.8150 mm): Pad 11 [unconnected-(J24-TMDS_CLK_SH-Pad11)] of J24 on F.Cu
[solder_mask_bridge]: Rear solder mask aperture bridges items with different nets
    Rule: board setup solder mask min width; error
    @(148.8000 mm, 387.3150 mm): Pad 8 [unconnected-(J24-TMDS_D0_SH-Pad8)] of J24 on B.Cu
    @(148.8000 mm, 386.3150 mm): Pad 10 [/HDMI In/Out/HDMI_IN_D2P] of J24 on B.Cu
[solder_mask_bridge]: Rear solder mask aperture bridges items with different nets
    Rule: board setup solder mask min width; error
    @(148.8000 mm, 387.3150 mm): Pad 8 [unconnected-(J24-TMDS_D0_SH-Pad8)] of J24 on B.Cu
    @(148.8000 mm, 385.3150 mm): Pad 12 [/HDMI In/Out/HDMI_IN_D2N] of J24 on B.Cu
[solder_mask_bridge]: Front solder mask aperture bridges items with different nets
    Rule: board setup solder mask min width; error
    @(148.8000 mm, 386.8150 mm): Pad 9 [unconnected-(J24-TMDS_D0--Pad9)] of J24 on F.Cu
    @(148.8000 mm, 385.8150 mm): Pad 11 [unconnected-(J24-TMDS_CLK_SH-Pad11)] of J24 on F.Cu
[solder_mask_bridge]: Front solder mask aperture bridges items with different nets
    Rule: board setup solder mask min width; error
    @(148.8000 mm, 386.8150 mm): Pad 9 [unconnected-(J24-TMDS_D0--Pad9)] of J24 on F.Cu
    @(148.8000 mm, 384.8150 mm): Pad 13 [unconnected-(J24-CEC-Pad13)] of J24 on F.Cu
[solder_mask_bridge]: Rear solder mask aperture bridges items with different nets
    Rule: board setup solder mask min width; error
    @(148.8000 mm, 386.3150 mm): Pad 10 [/HDMI In/Out/HDMI_IN_D2P] of J24 on B.Cu
    @(148.8000 mm, 385.3150 mm): Pad 12 [/HDMI In/Out/HDMI_IN_D2N] of J24 on B.Cu
[solder_mask_bridge]: Rear solder mask aperture bridges items with different nets
    Rule: board setup solder mask min width; error
    @(148.8000 mm, 386.3150 mm): Pad 10 [/HDMI In/Out/HDMI_IN_D2P] of J24 on B.Cu
    @(148.8000 mm, 384.3150 mm): Pad 14 [unconnected-(J24-NC-Pad14)] of J24 on B.Cu
[solder_mask_bridge]: Front solder mask aperture bridges items with different nets
    Rule: board setup solder mask min width; error
    @(148.8000 mm, 385.8150 mm): Pad 11 [unconnected-(J24-TMDS_CLK_SH-Pad11)] of J24 on F.Cu
    @(148.8000 mm, 384.8150 mm): Pad 13 [unconnected-(J24-CEC-Pad13)] of J24 on F.Cu
[solder_mask_bridge]: Front solder mask aperture bridges items with different nets
    Rule: board setup solder mask min width; error
    @(148.8000 mm, 385.8150 mm): Pad 11 [unconnected-(J24-TMDS_CLK_SH-Pad11)] of J24 on F.Cu
    @(148.8000 mm, 383.8150 mm): Pad 15 [/HDMI In/Out/HDMI_IN_D1P] of J24 on F.Cu
[solder_mask_bridge]: Rear solder mask aperture bridges items with different nets
    Rule: board setup solder mask min width; error
    @(148.8000 mm, 385.3150 mm): Pad 12 [/HDMI In/Out/HDMI_IN_D2N] of J24 on B.Cu
    @(148.8000 mm, 384.3150 mm): Pad 14 [unconnected-(J24-NC-Pad14)] of J24 on B.Cu
[solder_mask_bridge]: Rear solder mask aperture bridges items with different nets
    Rule: board setup solder mask min width; error
    @(148.8000 mm, 385.3150 mm): Pad 12 [/HDMI In/Out/HDMI_IN_D2N] of J24 on B.Cu
    @(148.8000 mm, 383.3150 mm): Pad 16 [/HDMI In/Out/HDMI_IN_D1N] of J24 on B.Cu
[solder_mask_bridge]: Front solder mask aperture bridges items with different nets
    Rule: board setup solder mask min width; error
    @(148.8000 mm, 384.8150 mm): Pad 13 [unconnected-(J24-CEC-Pad13)] of J24 on F.Cu
    @(148.8000 mm, 383.8150 mm): Pad 15 [/HDMI In/Out/HDMI_IN_D1P] of J24 on F.Cu
[solder_mask_bridge]: Front solder mask aperture bridges items with different nets
    Rule: board setup solder mask min width; error
    @(148.8000 mm, 384.8150 mm): Pad 13 [unconnected-(J24-CEC-Pad13)] of J24 on F.Cu
    @(148.8000 mm, 382.8150 mm): Pad 17 [unconnected-(J24-GND-Pad17)] of J24 on F.Cu
[solder_mask_bridge]: Rear solder mask aperture bridges items with different nets
    Rule: board setup solder mask min width; error
    @(148.8000 mm, 384.3150 mm): Pad 14 [unconnected-(J24-NC-Pad14)] of J24 on B.Cu
    @(148.8000 mm, 383.3150 mm): Pad 16 [/HDMI In/Out/HDMI_IN_D1N] of J24 on B.Cu
[solder_mask_bridge]: Rear solder mask aperture bridges items with different nets
    Rule: board setup solder mask min width; error
    @(148.8000 mm, 384.3150 mm): Pad 14 [unconnected-(J24-NC-Pad14)] of J24 on B.Cu
    @(148.8000 mm, 382.3150 mm): Pad 18 [unconnected-(J24-+5V-Pad18)] of J24 on B.Cu
[solder_mask_bridge]: Front solder mask aperture bridges items with different nets
    Rule: board setup solder mask min width; error
    @(148.8000 mm, 383.8150 mm): Pad 15 [/HDMI In/Out/HDMI_IN_D1P] of J24 on F.Cu
    @(148.8000 mm, 382.8150 mm): Pad 17 [unconnected-(J24-GND-Pad17)] of J24 on F.Cu
[solder_mask_bridge]: Front solder mask aperture bridges items with different nets
    Rule: board setup solder mask min width; error
    @(148.8000 mm, 383.8150 mm): Pad 15 [/HDMI In/Out/HDMI_IN_D1P] of J24 on F.Cu
    @(148.8000 mm, 381.8150 mm): Pad 19 [unconnected-(J24-HPD-Pad19)] of J24 on F.Cu
[solder_mask_bridge]: Rear solder mask aperture bridges items with different nets
    Rule: board setup solder mask min width; error
    @(148.8000 mm, 383.3150 mm): Pad 16 [/HDMI In/Out/HDMI_IN_D1N] of J24 on B.Cu
    @(148.8000 mm, 382.3150 mm): Pad 18 [unconnected-(J24-+5V-Pad18)] of J24 on B.Cu
[solder_mask_bridge]: Front solder mask aperture bridges items with different nets
    Rule: board setup solder mask min width; error
    @(148.8000 mm, 382.8150 mm): Pad 17 [unconnected-(J24-GND-Pad17)] of J24 on F.Cu
    @(148.8000 mm, 381.8150 mm): Pad 19 [unconnected-(J24-HPD-Pad19)] of J24 on F.Cu
[solder_mask_bridge]: Rear solder mask aperture bridges items with different nets
    Rule: board setup solder mask min width; error
    @(148.8000 mm, 382.3150 mm): Pad 18 [unconnected-(J24-+5V-Pad18)] of J24 on B.Cu
    @(148.9000 mm, 379.5400 mm): Pad SH [<no net>] of J24 on B.Cu
[solder_mask_bridge]: Front solder mask aperture bridges items with different nets
    Rule: board setup solder mask min width; error
    @(148.8000 mm, 381.8150 mm): Pad 19 [unconnected-(J24-HPD-Pad19)] of J24 on F.Cu
    @(148.9000 mm, 379.5400 mm): Pad SH [<no net>] of J24 on F.Cu
[hole_to_hole]: Drilled hole too close to other hole (board setup constraints min 0.2495 mm; actual 0.0000 mm)
    Rule: board setup constraints; warning
    @(272.3800 mm, 57.4400 mm): PTH pad 5 [unconnected-(J4-SHIELD-Pad5)] of J4
    @(272.3800 mm, 58.5800 mm): PTH pad 5 [unconnected-(J3-SHIELD-Pad5)] of J3
[hole_to_hole]: Drilled hole too close to other hole (board setup constraints min 0.2495 mm; actual 0.0000 mm)
    Rule: board setup constraints; warning
    @(272.3800 mm, 45.4400 mm): PTH pad 5 [unconnected-(J3-SHIELD-Pad5)] of J3
    @(272.3800 mm, 46.5800 mm): PTH pad 5 [unconnected-(J2-SHIELD-Pad5)] of J2
[hole_to_hole]: Drilled hole too close to other hole (board setup constraints min 0.2495 mm; actual 0.0000 mm)
    Rule: board setup constraints; warning
    @(272.3800 mm, 33.4400 mm): PTH pad 5 [unconnected-(J2-SHIELD-Pad5)] of J2
    @(272.3800 mm, 34.5800 mm): PTH pad 5 [unconnected-(J1-SHIELD-Pad5)] of J1
[lib_footprint_mismatch]: Footprint 'TSSOP-20_4.4x6.5mm_P0.65mm' does not match copy in library 'Package_SO'.
    Local override; warning
    @(122.3700 mm, 377.1400 mm): Footprint U42
[lib_footprint_mismatch]: Footprint 'RJ45_Hanrun_HR911105A_Horizontal' does not match copy in library 'Connector_RJ'.
    Local override; warning
    @(296.1000 mm, 181.4900 mm): Footprint J6
[lib_footprint_mismatch]: Footprint 'QFN-32-1EP_5x5mm_P0.5mm_EP3.1x3.1mm' does not match copy in library 'Package_DFN_QFN'.
    Local override; warning
    @(227.6700 mm, 46.5100 mm): Footprint U1
[lib_footprint_mismatch]: Footprint 'LQFP-64_10x10mm_P0.5mm' does not match copy in library 'Package_QFP'.
    Local override; warning
    @(137.3700 mm, 362.1400 mm): Footprint U43
[lib_footprint_mismatch]: Footprint 'SOT-23-5' does not match copy in library 'Package_TO_SOT_SMD'.
    Local override; warning
    @(252.6700 mm, 36.5100 mm): Footprint U8
[lib_footprint_mismatch]: Footprint 'BarrelJack_Horizontal' does not match copy in library 'Connector_BarrelJack'.
    Local override; warning
    @(77.7700 mm, 171.1500 mm): Footprint J16
[lib_footprint_mismatch]: Footprint 'SOIC-8_3.9x4.9mm_P1.27mm' does not match copy in library 'Package_SO'.
    Local override; warning
    @(108.8250 mm, 39.4450 mm): Footprint U13
[lib_footprint_mismatch]: Footprint 'SOT-23-5' does not match copy in library 'Package_TO_SOT_SMD'.
    Local override; warning
    @(206.0025 mm, 63.6800 mm): Footprint U9
[lib_footprint_mismatch]: Footprint 'USB_A_Stewart_SS-52100-001_Horizontal' does not match copy in library 'Connector_USB'.
    Local override; warning
    @(269.6700 mm, 67.5100 mm): Footprint J4
[lib_footprint_mismatch]: Footprint 'MountingHole_3.2mm_M3_Pad' does not match copy in library 'MountingHole'.
    Local override; warning
    @(245.0000 mm, 105.0000 mm): Footprint MH2
[lib_footprint_mismatch]: Footprint 'QFN-48-1EP_7x7mm_P0.5mm_EP5.6x5.6mm' does not match copy in library 'Package_DFN_QFN'.
    Local override; warning
    @(308.4000 mm, 154.7400 mm): Footprint U11
[lib_footprint_mismatch]: Footprint 'QFN-28-1EP_5x5mm_P0.5mm_EP3.35x3.35mm' does not match copy in library 'Package_DFN_QFN'.
    Local override; warning
    @(123.8250 mm, 51.4450 mm): Footprint U17
[lib_footprint_mismatch]: Footprint 'SOT-23-5' does not match copy in library 'Package_TO_SOT_SMD'.
    Local override; warning
    @(232.6700 mm, 66.5100 mm): Footprint U7
[lib_footprint_mismatch]: Footprint 'QFN-48-1EP_7x7mm_P0.5mm_EP5.6x5.6mm' does not match copy in library 'Package_DFN_QFN'.
    Local override; warning
    @(278.4000 mm, 166.7400 mm): Footprint U12
[lib_footprint_mismatch]: Footprint 'USB_A_Stewart_SS-52100-001_Horizontal' does not match copy in library 'Connector_USB'.
    Local override; warning
    @(269.6700 mm, 55.5100 mm): Footprint J3
[lib_footprint_mismatch]: Footprint 'UQFN-10_1.4x1.8mm_P0.4mm' does not match copy in library 'Package_DFN_QFN'.
    Local override; warning
    @(232.6700 mm, 36.5100 mm): Footprint U5
[lib_footprint_mismatch]: Footprint 'QFN-48-1EP_7x7mm_P0.5mm_EP5.6x5.6mm' does not match copy in library 'Package_DFN_QFN'.
    Local override; warning
    @(242.6700 mm, 36.5100 mm): Footprint U2
[lib_footprint_mismatch]: Footprint 'UQFN-10_1.4x1.8mm_P0.4mm' does not match copy in library 'Package_DFN_QFN'.
    Local override; warning
    @(242.6700 mm, 66.5100 mm): Footprint U4
[lib_footprint_mismatch]: Footprint 'SOT-23-5' does not match copy in library 'Package_TO_SOT_SMD'.
    Local override; warning
    @(221.0025 mm, 63.6800 mm): Footprint U10
[lib_footprint_mismatch]: Footprint 'USB_A_Stewart_SS-52100-001_Horizontal' does not match copy in library 'Connector_USB'.
    Local override; warning
    @(269.6700 mm, 43.5100 mm): Footprint J2
[lib_footprint_mismatch]: Footprint 'USB_A_Stewart_SS-52100-001_Horizontal' does not match copy in library 'Connector_USB'.
    Local override; warning
    @(269.6700 mm, 31.5100 mm): Footprint J1
[lib_footprint_mismatch]: Footprint 'SOIC-8_3.9x4.9mm_P1.27mm' does not match copy in library 'Package_SO'.
    Local override; warning
    @(123.8250 mm, 39.4450 mm): Footprint U14
[lib_footprint_mismatch]: Footprint 'QFN-24-1EP_4x4mm_P0.5mm_EP2.7x2.7mm' does not match copy in library 'Package_DFN_QFN'.
    Local override; warning
    @(137.3700 mm, 377.1400 mm): Footprint U44
[lib_footprint_mismatch]: Footprint 'QFN-24-1EP_4x4mm_P0.5mm_EP2.7x2.7mm' does not match copy in library 'Package_DFN_QFN'.
    Local override; warning
    @(137.3700 mm, 375.1400 mm): Footprint U45
[lib_footprint_mismatch]: Footprint 'LQFP-64_10x10mm_P0.5mm' does not match copy in library 'Package_QFP'.
    Local override; warning
    @(122.3700 mm, 362.1400 mm): Footprint U41
[lib_footprint_mismatch]: Footprint 'MountingHole_3.2mm_M3_Pad' does not match copy in library 'MountingHole'.
    Local override; warning
    @(105.0000 mm, 105.0000 mm): Footprint MH1
[lib_footprint_mismatch]: Footprint 'SOIC-8_3.9x4.9mm_P1.27mm' does not match copy in library 'Package_SO'.
    Local override; warning
    @(93.8250 mm, 51.4450 mm): Footprint U15
[lib_footprint_mismatch]: Footprint 'HDMI_A_Contact_Technology_HDMI-19APL2_Horizontal' does not match copy in library 'fcBoard_Connectors'.
    Local override; warning
    @(168.7200 mm, 384.9000 mm): Footprint J23
[lib_footprint_mismatch]: Footprint 'UQFN-10_1.4x1.8mm_P0.4mm' does not match copy in library 'Package_DFN_QFN'.
    Local override; warning
    @(232.6700 mm, 51.5100 mm): Footprint U6
[lib_footprint_mismatch]: Footprint 'SOIC-8_3.9x4.9mm_P1.27mm' does not match copy in library 'Package_SO'.
    Local override; warning
    @(108.8250 mm, 51.4450 mm): Footprint U16
[lib_footprint_mismatch]: Footprint 'MountingHole_3.2mm_M3_Pad' does not match copy in library 'MountingHole'.
    Local override; warning
    @(245.0000 mm, 195.0000 mm): Footprint MH4
[lib_footprint_mismatch]: Footprint 'UQFN-10_1.4x1.8mm_P0.4mm' does not match copy in library 'Package_DFN_QFN'.
    Local override; warning
    @(242.6700 mm, 51.5100 mm): Footprint U3
[lib_footprint_mismatch]: Footprint 'HDMI_A_Contact_Technology_HDMI-19APL2_Horizontal' does not match copy in library 'fcBoard_Connectors'.
    Local override; warning
    @(148.8000 mm, 386.3150 mm): Footprint J24
[lib_footprint_mismatch]: Footprint 'MountingHole_3.2mm_M3_Pad' does not match copy in library 'MountingHole'.
    Local override; warning
    @(105.0000 mm, 195.0000 mm): Footprint MH3
[silk_over_copper]: Silkscreen clipped by solder mask
    Local override; warning
    @(126.6950 mm, 384.2650 mm): Segment of Y10 on F.Silkscreen
[silk_over_copper]: Silkscreen clipped by solder mask
    Local override; warning
    @(126.6950 mm, 386.0150 mm): Segment of Y10 on F.Silkscreen
[silk_over_copper]: Silkscreen clipped by solder mask
    Local override; warning
    @(126.6950 mm, 368.2650 mm): Segment of Y9 on F.Silkscreen
[silk_over_copper]: Silkscreen clipped by solder mask
    Local override; warning
    @(126.6950 mm, 370.0150 mm): Segment of Y9 on F.Silkscreen
[silk_over_copper]: Silkscreen clipped by solder mask
    Local override; warning
    @(327.7250 mm, 178.8650 mm): Segment of Y2 on F.Silkscreen
[silk_over_copper]: Silkscreen clipped by solder mask
    Local override; warning
    @(327.7250 mm, 180.6150 mm): Segment of Y2 on F.Silkscreen
[silk_over_copper]: Silkscreen clipped by solder mask
    Local override; warning
    @(327.7250 mm, 168.8650 mm): Segment of Y1 on F.Silkscreen
[silk_over_copper]: Silkscreen clipped by solder mask
    Local override; warning
    @(327.7250 mm, 170.6150 mm): Segment of Y1 on F.Silkscreen
[silk_over_copper]: Silkscreen clipped by solder mask
    Local override; warning
    @(37.1550 mm, 152.8450 mm): Segment of L6 on F.Silkscreen
[silk_over_copper]: Silkscreen clipped by solder mask
    Local override; warning
    @(37.1550 mm, 159.0450 mm): Segment of L6 on F.Silkscreen
[silk_over_copper]: Silkscreen clipped by solder mask
    Local override; warning
    @(43.3550 mm, 152.8450 mm): Segment of L6 on F.Silkscreen
[silk_over_copper]: Silkscreen clipped by solder mask
    Local override; warning
    @(43.3550 mm, 159.0450 mm): Segment of L6 on F.Silkscreen
[silk_over_copper]: Silkscreen clipped by solder mask
    Local override; warning
    @(30.2550 mm, 151.3450 mm): Reference field of L5
[silk_over_copper]: Silkscreen clipped by solder mask
    Local override; warning
    @(27.1550 mm, 152.8450 mm): Segment of L5 on F.Silkscreen
[silk_over_copper]: Silkscreen clipped by solder mask
    Local override; warning
    @(27.1550 mm, 159.0450 mm): Segment of L5 on F.Silkscreen
[silk_over_copper]: Silkscreen clipped by solder mask
    Local override; warning
    @(33.3550 mm, 152.8450 mm): Segment of L5 on F.Silkscreen
[silk_over_copper]: Silkscreen clipped by solder mask
    Local override; warning
    @(33.3550 mm, 159.0450 mm): Segment of L5 on F.Silkscreen
[silk_over_copper]: Silkscreen clipped by solder mask
    Local override; warning
    @(113.8250 mm, 39.4550 mm): Reference field of J11
[silk_over_copper]: Silkscreen clipped by solder mask
    Local override; warning
    @(106.9150 mm, 41.6350 mm): Segment of J11 on F.Silkscreen
[silk_over_copper]: Silkscreen clipped by solder mask
    Local override; warning
    @(106.9150 mm, 41.6350 mm): Segment of J11 on F.Silkscreen
[silk_over_copper]: Silkscreen clipped by solder mask
    Local override; warning
    @(106.9150 mm, 44.5550 mm): Segment of J11 on F.Silkscreen
[silk_over_copper]: Silkscreen clipped by solder mask
    Local override; warning
    @(106.9150 mm, 52.8550 mm): Segment of J11 on F.Silkscreen
[silk_over_copper]: Silkscreen clipped by solder mask
    Local override; warning
    @(108.8250 mm, 40.1350 mm): Segment of J11 on F.Silkscreen
[silk_over_copper]: Silkscreen clipped by solder mask
    Local override; warning
    @(109.1250 mm, 40.9350 mm): Segment of J11 on F.Silkscreen
[silk_over_copper]: Silkscreen clipped by solder mask
    Local override; warning
    @(110.8250 mm, 41.2350 mm): Segment of J11 on F.Silkscreen
[silk_over_copper]: Silkscreen clipped by solder mask
    Local override; warning
    @(111.6250 mm, 41.3350 mm): Segment of J11 on F.Silkscreen
[silk_over_copper]: Silkscreen clipped by solder mask
    Local override; warning
    @(120.7350 mm, 41.6350 mm): Segment of J11 on F.Silkscreen
[silk_over_copper]: Silkscreen clipped by solder mask
    Local override; warning
    @(137.3700 mm, 373.8100 mm): Reference field of U44
[silk_over_copper]: Silkscreen clipped by solder mask
    Local override; warning
    @(135.2600 mm, 375.5050 mm): Segment of U44 on F.Silkscreen
[silk_over_copper]: Silkscreen clipped by solder mask
    Local override; warning
    @(135.7350 mm, 375.0300 mm): Segment of U44 on F.Silkscreen
[silk_over_copper]: Silkscreen clipped by solder mask
    Local override; warning
    @(139.0050 mm, 375.0300 mm): Segment of U44 on F.Silkscreen
[silk_over_copper]: Silkscreen clipped by solder mask
    Local override; warning
    @(139.4800 mm, 375.0300 mm): Segment of U44 on F.Silkscreen
[silk_over_copper]: Silkscreen clipped by solder mask
    Local override; warning
    @(135.2600 mm, 375.0300 mm): Polygon of U44 on F.Silkscreen
[silk_over_copper]: Silkscreen clipped by solder mask
    Local override; warning
    @(135.2600 mm, 377.2500 mm): Segment of U45 on F.Silkscreen
[silk_over_copper]: Silkscreen clipped by solder mask
    Local override; warning
    @(135.7350 mm, 377.2500 mm): Segment of U45 on F.Silkscreen
[silk_over_copper]: Silkscreen clipped by solder mask
    Local override; warning
    @(139.0050 mm, 377.2500 mm): Segment of U45 on F.Silkscreen
[silk_over_copper]: Silkscreen clipped by solder mask
    Local override; warning
    @(139.4800 mm, 377.2500 mm): Segment of U45 on F.Silkscreen
[silk_over_copper]: Silkscreen clipped by solder mask
    Local override; warning
    @(167.2600 mm, 378.6900 mm): Segment of J23 on F.Silkscreen
[silk_over_copper]: Silkscreen clipped by solder mask
    Local override; warning
    @(167.2600 mm, 391.1100 mm): Segment of J23 on F.Silkscreen
[silk_over_copper]: Silkscreen clipped by solder mask
    Local override; warning
    @(170.0100 mm, 377.5600 mm): Segment of J23 on F.Silkscreen
[silk_over_copper]: Silkscreen clipped by solder mask
    Local override; warning
    @(170.0100 mm, 389.9100 mm): Segment of J23 on F.Silkscreen
[silk_over_copper]: Silkscreen clipped by solder mask
    Local override; warning
    @(170.0100 mm, 392.2400 mm): Segment of J23 on F.Silkscreen
[silk_over_copper]: Silkscreen clipped by solder mask
    Local override; warning
    @(167.2600 mm, 378.6900 mm): Segment of J23 on B.Silkscreen
[silk_over_copper]: Silkscreen clipped by solder mask
    Local override; warning
    @(167.2600 mm, 391.1100 mm): Segment of J23 on B.Silkscreen
[silk_over_copper]: Silkscreen clipped by solder mask
    Local override; warning
    @(170.0100 mm, 377.5600 mm): Segment of J23 on B.Silkscreen
[silk_over_copper]: Silkscreen clipped by solder mask
    Local override; warning
    @(170.0100 mm, 392.2400 mm): Segment of J23 on B.Silkscreen
[silk_over_copper]: Silkscreen clipped by solder mask
    Local override; warning
    @(147.3400 mm, 380.1050 mm): Segment of J24 on F.Silkscreen
[silk_over_copper]: Silkscreen clipped by solder mask
    Local override; warning
    @(147.3400 mm, 392.5250 mm): Segment of J24 on F.Silkscreen
[silk_over_copper]: Silkscreen clipped by solder mask
    Local override; warning
    @(150.0900 mm, 378.9750 mm): Segment of J24 on F.Silkscreen
[silk_over_copper]: Silkscreen clipped by solder mask
    Local override; warning
    @(150.0900 mm, 391.3250 mm): Segment of J24 on F.Silkscreen
[silk_over_copper]: Silkscreen clipped by solder mask
    Local override; warning
    @(150.0900 mm, 393.6550 mm): Segment of J24 on F.Silkscreen
[silk_over_copper]: Silkscreen clipped by solder mask
    Local override; warning
    @(147.3400 mm, 380.1050 mm): Segment of J24 on B.Silkscreen
[silk_over_copper]: Silkscreen clipped by solder mask
    Local override; warning
    @(147.3400 mm, 392.5250 mm): Segment of J24 on B.Silkscreen
[silk_over_copper]: Silkscreen clipped by solder mask
    Local override; warning
    @(150.0900 mm, 378.9750 mm): Segment of J24 on B.Silkscreen
[silk_over_copper]: Silkscreen clipped by solder mask
    Local override; warning
    @(150.0900 mm, 393.6550 mm): Segment of J24 on B.Silkscreen
[silk_over_copper]: Silkscreen clipped by solder mask
    Local override; warning
    @(17.1550 mm, 152.8450 mm): Segment of L4 on F.Silkscreen
[silk_over_copper]: Silkscreen clipped by solder mask
    Local override; warning
    @(17.1550 mm, 159.0450 mm): Segment of L4 on F.Silkscreen
[silk_over_copper]: Silkscreen clipped by solder mask
    Local override; warning
    @(23.3550 mm, 152.8450 mm): Segment of L4 on F.Silkscreen
[silk_over_copper]: Silkscreen clipped by solder mask
    Local override; warning
    @(23.3550 mm, 159.0450 mm): Segment of L4 on F.Silkscreen
[silk_overlap]: Silkscreen overlap
    Rule: board setup constraints silk; warning
    @(126.5300 mm, 367.2500 mm): Segment of U41 on F.Silkscreen
    @(127.3700 mm, 367.1400 mm): Reference field of Y9
[silk_overlap]: Silkscreen overlap
    Rule: board setup constraints silk; warning
    @(127.4800 mm, 367.2500 mm): Segment of U41 on F.Silkscreen
    @(127.3700 mm, 367.1400 mm): Reference field of Y9
[silk_overlap]: Silkscreen overlap
    Rule: board setup constraints silk; warning
    @(221.0025 mm, 61.2800 mm): Reference field of U10
    @(219.7025 mm, 62.1700 mm): Polygon of U10 on F.Silkscreen
[silk_overlap]: Silkscreen overlap
    Rule: board setup constraints silk; warning
    @(268.6600 mm, 34.2600 mm): Segment of J1 on F.Silkscreen
    @(268.6600 mm, 33.7600 mm): Segment of J2 on F.Silkscreen
[silk_overlap]: Silkscreen overlap
    Rule: board setup constraints silk; warning
    @(268.6600 mm, 45.7600 mm): Segment of J3 on F.Silkscreen
    @(268.6600 mm, 33.7600 mm): Segment of J2 on F.Silkscreen
[silk_overlap]: Silkscreen overlap
    Rule: board setup constraints silk; warning
    @(270.6600 mm, 45.7600 mm): Segment of J3 on F.Silkscreen
    @(268.6600 mm, 33.7600 mm): Segment of J2 on F.Silkscreen
[silk_overlap]: Silkscreen overlap
    Rule: board setup constraints silk; warning
    @(268.6600 mm, 21.7600 mm): Segment of J1 on F.Silkscreen
    @(268.6600 mm, 33.7600 mm): Segment of J2 on F.Silkscreen
[silk_overlap]: Silkscreen overlap
    Rule: board setup constraints silk; warning
    @(268.6600 mm, 21.7600 mm): Segment of J1 on F.Silkscreen
    @(270.6600 mm, 33.7600 mm): Segment of J2 on F.Silkscreen
[silk_overlap]: Silkscreen overlap
    Rule: board setup constraints silk; warning
    @(282.6600 mm, 47.2600 mm): Segment of J2 on F.Silkscreen
    @(282.1600 mm, 35.2600 mm): Segment of J1 on F.Silkscreen
[silk_overlap]: Silkscreen overlap
    Rule: board setup constraints silk; warning
    @(282.6600 mm, 47.2600 mm): Segment of J2 on F.Silkscreen
    @(282.6600 mm, 59.2600 mm): Segment of J3 on F.Silkscreen
[silk_overlap]: Silkscreen overlap
    Rule: board setup constraints silk; warning
    @(282.6600 mm, 47.2600 mm): Segment of J2 on F.Silkscreen
    @(282.6600 mm, 44.7600 mm): Segment of J3 on F.Silkscreen
[silk_overlap]: Silkscreen overlap
    Rule: board setup constraints silk; warning
    @(282.6600 mm, 35.2600 mm): Segment of J1 on F.Silkscreen
    @(282.6600 mm, 47.2600 mm): Segment of J2 on F.Silkscreen
[silk_overlap]: Silkscreen overlap
    Rule: board setup constraints silk; warning
    @(282.6600 mm, 32.7600 mm): Segment of J2 on F.Silkscreen
    @(282.6600 mm, 35.2600 mm): Segment of J1 on F.Silkscreen
[silk_overlap]: Silkscreen overlap
    Rule: board setup constraints silk; warning
    @(268.6600 mm, 57.7600 mm): Segment of J4 on F.Silkscreen
    @(268.6600 mm, 58.2600 mm): Segment of J3 on F.Silkscreen
[silk_overlap]: Silkscreen overlap
    Rule: board setup constraints silk; warning
    @(268.6600 mm, 45.7600 mm): Segment of J3 on F.Silkscreen
    @(268.6600 mm, 57.7600 mm): Segment of J4 on F.Silkscreen
[silk_overlap]: Silkscreen overlap
    Rule: board setup constraints silk; warning
    @(268.6600 mm, 45.7600 mm): Segment of J3 on F.Silkscreen
    @(270.6600 mm, 57.7600 mm): Segment of J4 on F.Silkscreen
[silk_overlap]: Silkscreen overlap
    Rule: board setup constraints silk; warning
    @(282.6600 mm, 71.2600 mm): Segment of J4 on F.Silkscreen
    @(282.6600 mm, 59.2600 mm): Segment of J3 on F.Silkscreen
[silk_overlap]: Silkscreen overlap
    Rule: board setup constraints silk; warning
    @(282.1600 mm, 59.2600 mm): Segment of J3 on F.Silkscreen
    @(282.6600 mm, 71.2600 mm): Segment of J4 on F.Silkscreen
[silk_overlap]: Silkscreen overlap
    Rule: board setup constraints silk; warning
    @(268.6600 mm, 45.7600 mm): Segment of J3 on F.Silkscreen
    @(268.6600 mm, 46.2600 mm): Segment of J2 on F.Silkscreen
[silk_overlap]: Silkscreen overlap
    Rule: board setup constraints silk; warning
    @(282.6600 mm, 56.7600 mm): Segment of J4 on F.Silkscreen
    @(282.6600 mm, 59.2600 mm): Segment of J3 on F.Silkscreen
[silk_overlap]: Silkscreen overlap
    Rule: board setup constraints silk; warning
    @(282.1600 mm, 47.2600 mm): Segment of J2 on F.Silkscreen
    @(282.6600 mm, 59.2600 mm): Segment of J3 on F.Silkscreen
[silk_overlap]: Silkscreen overlap
    Rule: board setup constraints silk; warning
    @(112.4450 mm, 38.7150 mm): Segment of J10 on F.Silkscreen
    @(108.8250 mm, 40.1350 mm): Segment of J11 on F.Silkscreen
[silk_overlap]: Silkscreen overlap
    Rule: board setup constraints silk; warning
    @(111.6250 mm, 41.3350 mm): Segment of J11 on F.Silkscreen
    @(112.4450 mm, 38.7150 mm): Segment of J10 on F.Silkscreen
[silk_overlap]: Silkscreen overlap
    Rule: board setup constraints silk; warning
    @(112.4450 mm, 41.3650 mm): Segment of J10 on F.Silkscreen
    @(112.9250 mm, 41.4350 mm): Segment of J11 on F.Silkscreen
[silk_overlap]: Silkscreen overlap
    Rule: board setup constraints silk; warning
    @(120.7350 mm, 55.5550 mm): Segment of J11 on F.Silkscreen
    @(113.8250 mm, 55.0650 mm): Reference field of J12
[silk_overlap]: Silkscreen overlap
    Rule: board setup constraints silk; warning
    @(112.4450 mm, 41.3650 mm): Segment of J10 on F.Silkscreen
    @(111.6250 mm, 41.3350 mm): Segment of J11 on F.Silkscreen
[silk_overlap]: Silkscreen overlap
    Rule: board setup constraints silk; warning
    @(112.4450 mm, 41.3650 mm): Segment of J10 on F.Silkscreen
    @(114.7250 mm, 41.4350 mm): Segment of J11 on F.Silkscreen
[silk_overlap]: Silkscreen overlap
    Rule: board setup constraints silk; warning
    @(108.8250 mm, 40.1350 mm): Segment of J11 on F.Silkscreen
    @(115.2050 mm, 38.7150 mm): Segment of J10 on F.Silkscreen
[silk_overlap]: Silkscreen overlap
    Rule: board setup constraints silk; warning
    @(114.7250 mm, 41.4350 mm): Segment of J11 on F.Silkscreen
    @(115.2050 mm, 38.7150 mm): Segment of J10 on F.Silkscreen
[silk_overlap]: Silkscreen overlap
    Rule: board setup constraints silk; warning
    @(108.8250 mm, 42.0050 mm): Segment of U13 on F.Silkscreen
    @(106.9150 mm, 41.6350 mm): Segment of J11 on F.Silkscreen
[silk_overlap]: Silkscreen overlap
    Rule: board setup constraints silk; warning
    @(106.9150 mm, 52.8550 mm): Segment of J11 on F.Silkscreen
    @(108.8250 mm, 54.0050 mm): Segment of U16 on F.Silkscreen
[silk_overlap]: Silkscreen overlap
    Rule: board setup constraints silk; warning
    @(108.8250 mm, 48.8850 mm): Segment of U16 on F.Silkscreen
    @(106.9150 mm, 44.5550 mm): Segment of J11 on F.Silkscreen
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

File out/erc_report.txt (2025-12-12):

ERC report (2025-12-01T13:47:10+0900, Encoding UTF8)

***** Sheet /
[pin_not_connected]: Pin not connected
    ; error
    @(76.20 mm, 81.28 mm): Hierarchical Sheet Pin +12V
[pin_not_connected]: Pin not connected
    ; error
    @(76.20 mm, 86.36 mm): Hierarchical Sheet Pin +5V
[pin_not_connected]: Pin not connected
    ; error
    @(76.20 mm, 91.44 mm): Hierarchical Sheet Pin +3V3
[pin_not_connected]: Pin not connected
    ; error
    @(76.20 mm, 96.52 mm): Hierarchical Sheet Pin +1V8
[pin_not_connected]: Pin not connected
    ; error
    @(76.20 mm, 101.60 mm): Hierarchical Sheet Pin GND
[label_dangling]: Label not connected to anything
    ; error
    @(138.43 mm, 72.39 mm): Hierarchical Label '+12V'
[label_dangling]: Label not connected to anything
    ; error
    @(181.61 mm, 207.01 mm): Hierarchical Label 'GND'
[label_dangling]: Label not connected to anything
    ; error
    @(78.52 mm, 63.50 mm): Label 'ULPI_CLK'
[label_dangling]: Label not connected to anything
    ; error
    @(78.52 mm, 66.04 mm): Label 'ULPI_DIR'
[label_dangling]: Label not connected to anything
    ; error
    @(78.52 mm, 76.20 mm): Label 'ULPI_D0'
[label_dangling]: Label not connected to anything
    ; error
    @(78.52 mm, 81.28 mm): Label 'ULPI_D2'
[label_dangling]: Label not connected to anything
    ; error
    @(78.52 mm, 83.82 mm): Label 'ULPI_D3'
[label_dangling]: Label not connected to anything
    ; error
    @(78.52 mm, 86.36 mm): Label 'ULPI_D4'
[label_dangling]: Label not connected to anything
    ; error
    @(78.52 mm, 88.90 mm): Label 'ULPI_D5'
[label_dangling]: Label not connected to anything
    ; error
    @(78.52 mm, 91.44 mm): Label 'ULPI_D6'
[label_dangling]: Label not connected to anything
    ; error
    @(78.52 mm, 93.98 mm): Label 'ULPI_D7'
[label_dangling]: Label not connected to anything
    ; error
    @(114.52 mm, 73.66 mm): Label 'DN2_DN'
[label_dangling]: Label not connected to anything
    ; error
    @(114.52 mm, 78.74 mm): Label 'DN3_DP'
[label_dangling]: Label not connected to anything
    ; error
    @(114.52 mm, 86.36 mm): Label 'DN4_DP'
[label_dangling]: Label not connected to anything
    ; error
    @(174.52 mm, 51.28 mm): Label 'DN1_DP'
[label_dangling]: Label not connected to anything
    ; error
    @(174.52 mm, 53.82 mm): Label 'DN1_DN'
[label_dangling]: Label not connected to anything
    ; error
    @(88.68 mm, 161.30 mm): Label 'ULPI_D1'
[label_dangling]: Label not connected to anything
    ; error
    @(174.52 mm, 91.28 mm): Label 'DN2_DP'
[label_dangling]: Label not connected to anything
    ; error
    @(118.68 mm, 163.84 mm): Label 'ULPI_NXT'
[label_dangling]: Label not connected to anything
    ; error
    @(118.68 mm, 166.38 mm): Label 'ULPI_STP'
[label_dangling]: Label not connected to anything
    ; error
    @(198.52 mm, 91.28 mm): Label 'USB2_DP'
[label_dangling]: Label not connected to anything
    ; error
    @(198.52 mm, 93.82 mm): Label 'USB2_DN'
[label_dangling]: Label not connected to anything
    ; error
    @(174.52 mm, 133.82 mm): Label 'DN3_DN'
[label_dangling]: Label not connected to anything
    ; error
    @(198.52 mm, 131.28 mm): Label 'USB3_DP'
[label_dangling]: Label not connected to anything
    ; error
    @(174.52 mm, 173.82 mm): Label 'DN4_DN'
[label_dangling]: Label not connected to anything
    ; error
    @(198.52 mm, 173.82 mm): Label 'USB4_DN'
[label_dangling]: Label not connected to anything
    ; error
    @(278.52 mm, 51.28 mm): Label 'USB1_VBUS'
[label_dangling]: Label not connected to anything
    ; error
    @(278.52 mm, 91.28 mm): Label 'USB2_VBUS'
[label_dangling]: Label not connected to anything
    ; error
    @(278.52 mm, 131.28 mm): Label 'USB3_VBUS'
[label_dangling]: Label not connected to anything
    ; error
    @(278.52 mm, 171.28 mm): Label 'USB4_VBUS'
[label_dangling]: Label not connected to anything
    ; error
    @(334.52 mm, 53.82 mm): Label 'USB1_DN'
[label_dangling]: Label not connected to anything
    ; error
    @(334.52 mm, 56.36 mm): Label 'USB1_DP'
[label_dangling]: Label not connected to anything
    ; error
    @(334.52 mm, 133.82 mm): Label 'USB3_DN'
[label_dangling]: Label not connected to anything
    ; error
    @(334.52 mm, 176.36 mm): Label 'USB4_DP'
[label_dangling]: Label not connected to anything
    ; error
    @(129.07 mm, 88.60 mm): Hierarchical Label 'ETH1_TX_EN'
[label_dangling]: Label not connected to anything
    ; error
    @(159.07 mm, 76.20 mm): Label 'ETH1_TXD0'
[label_dangling]: Label not connected to anything
    ; error
    @(159.07 mm, 78.74 mm): Label 'ETH1_TXD1'
[label_dangling]: Label not connected to anything
    ; error
    @(159.07 mm, 81.28 mm): Label 'ETH1_TXD2'
[label_dangling]: Label not connected to anything
    ; error
    @(159.07 mm, 83.82 mm): Label 'ETH1_TXD3'
[label_dangling]: Label not connected to anything
    ; error
    @(159.07 mm, 88.90 mm): Label 'ETH1_TX_CLK'
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

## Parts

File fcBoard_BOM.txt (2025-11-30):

====================================================================================================
BILL OF MATERIALS - fcBoard Carrier Board
Generated: 2025-12-01 00:58:07
====================================================================================================

Qty   References                          Value                Footprint                          
----------------------------------------------------------------------------------------------------
1     C1                                  470uF                C_0402_1005Metric                  
3     C2, C3, C4                          220uF                C_0402_1005Metric                  
4     C6, C7, C9, C10                     22pF                 C_0402_1005Metric                  
5     C5, C8, C11, C12, C13               100nF                C_0402_1005Metric                  
1     D1                                  LED_5V               LED_0603_1608Metric                
1     D3                                  LED_3V3              LED_0603_1608Metric                
1     D5                                  LED_1V8              LED_0603_1608Metric                
3     D2, D4, D6                          SS34                 LED_0603_1608Metric                
1     D7                                  LED_USER0            LED_0603_1608Metric                
1     D8                                  LED_USER1            LED_0603_1608Metric                
1     D9                                  LED_USER2            LED_0603_1608Metric                
1     D10                                 LED_USER3            LED_0603_1608Metric                
2     FB1, FB2                            600R@100MHz          L_0402_1005Metric                  
1     J1                                  DC_12V               BarrelJack_Horizontal              
4     J2, J3, J4, J5                      USB_A                USB_A_Stewart_SS-52100-001_Hor...  
2     J6, J7                              RJ45_MagJack         RJ45_Amphenol_RJHSE538X_Horizo...  
1     J8                                  HDMI_IN              HDMI_A_Molex_2086581051_Horizo...  
1     J9                                  HDMI_OUT             HDMI_A_Molex_2086581051_Horizo...  
1     J10                                 MicroSD              microSD_HC_Wuerth_693072010801     
1     J11                                 USB_Debug            PinHeader_1x02_P2.54mm_Vertical    
1     J12                                 CAN0                 PinHeader_1x02_P2.54mm_Vertical    
1     J13                                 RS485_0              PinHeader_1x02_P2.54mm_Vertical    
1     J14                                 CAN1                 PinHeader_1x02_P2.54mm_Vertical    
1     J15                                 RS485_1              PinHeader_1x02_P2.54mm_Vertical    
3     L1, L2, L3                          33uH                 L_Bourns_SRN6045TA                 
1     R2                                  3.3K                 R_0402_1005Metric                  
1     R3                                  470                  R_0402_1005Metric                  
2     R4, R7                              1.5K                 R_0402_1005Metric                  
2     R1, R5                              1K                   R_0402_1005Metric                  
1     R6                                  100                  R_0402_1005Metric                  
2     R8, R9                              4.7K                 R_0402_1005Metric                  
1     R10                                 10K                  R_0402_1005Metric                  
4     R11, R12, R13, R14                  470R                 R_0402_1005Metric                  
1     SW1                                 BTN0                 SW_SPST_TL3342                     
1     SW2                                 BTN1                 SW_SPST_TL3342                     
1     U1                                  LM2596S-5            TO-263-5_TabPin3                   
2     U2, U3                              LM2596S-ADJ          TO-263-5_TabPin3                   
4     U4, U8, U10, U12                    TPD4S012             UQFN-10_1.4x1.8mm_P0.4mm           
4     U5, U9, U11, U13                    TPS2041B             SOT-23-5                           
1     U6                                  USB3320              QFN-32-1EP_5x5mm_P0.5mm_EP3.1x...  
1     U7                                  USB5744              QFN-48-1EP_6x6mm_P0.4mm_EP4.25...  
2     U14, U15                            RTL8211F-CG          QFN-48-1EP_6x6mm_P0.4mm_EP4.25...  
2     U16, U20                            TPD12S016            QFN-24-1EP_4x4mm_P0.5mm_EP2.7x...  
1     U17                                 IT6801FN             LQFP-64_10x10mm_P0.5mm             
1     U18                                 TXB0108              TSSOP-20_4.4x6.5mm_P0.65mm         
1     U19                                 IT66121FN            LQFP-64_10x10mm_P0.5mm             
1     U21                                 CP2102N              QFN-28-1EP_5x5mm_P0.5mm_EP3.35...  
2     U23, U25                            MAX485               SOIC-8_3.9x4.9mm_P1.27mm           
2     U22, U24                            SN65HVD230           SOIC-8_3.9x4.9mm_P1.27mm           
2     Y1, Y2                              25MHz                Crystal_SMD_3215-2Pin_3.2x1.5mm    
2     Y3, Y4                              27MHz                Crystal_SMD_3215-2Pin_3.2x1.5mm    
----------------------------------------------------------------------------------------------------
Unique parts: 51
Total components: 88

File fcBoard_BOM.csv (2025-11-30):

Qty | References | Value | Footprint
1 | C1 | 470uF | Capacitor_SMD:C_0402_1005Metric
3 | C2 C3 C4 | 220uF | Capacitor_SMD:C_0402_1005Metric
4 | C6 C7 C9 C10 | 22pF | Capacitor_SMD:C_0402_1005Metric
5 | C5 C8 C11 C12 C13 | 100nF | Capacitor_SMD:C_0402_1005Metric
1 | D1 | LED_5V | LED_SMD:LED_0603_1608Metric
1 | D3 | LED_3V3 | LED_SMD:LED_0603_1608Metric
1 | D5 | LED_1V8 | LED_SMD:LED_0603_1608Metric
3 | D2 D4 D6 | SS34 | LED_SMD:LED_0603_1608Metric
1 | D7 | LED_USER0 | LED_SMD:LED_0603_1608Metric
1 | D8 | LED_USER1 | LED_SMD:LED_0603_1608Metric
1 | D9 | LED_USER2 | LED_SMD:LED_0603_1608Metric
1 | D10 | LED_USER3 | LED_SMD:LED_0603_1608Metric
2 | FB1 FB2 | 600R@100MHz | Inductor_SMD:L_0402_1005Metric
1 | J1 | DC_12V | Connector_BarrelJack:BarrelJack_Horizontal
4 | J2 J3 J4 J5 | USB_A | Connector_USB:USB_A_Stewart_SS-52100-001_Horizontal
2 | J6 J7 | RJ45_MagJack | Connector_RJ:RJ45_Amphenol_RJHSE538X_Horizontal
1 | J8 | HDMI_IN | Connector_HDMI:HDMI_A_Molex_2086581051_Horizontal
1 | J9 | HDMI_OUT | Connector_HDMI:HDMI_A_Molex_2086581051_Horizontal
1 | J10 | MicroSD | Connector_Card:microSD_HC_Wuerth_693072010801
1 | J11 | USB_Debug | Connector_PinHeader_2.54mm:PinHeader_1x02_P2.54mm_Vertical
1 | J12 | CAN0 | Connector_PinHeader_2.54mm:PinHeader_1x02_P2.54mm_Vertical
1 | J13 | RS485_0 | Connector_PinHeader_2.54mm:PinHeader_1x02_P2.54mm_Vertical
1 | J14 | CAN1 | Connector_PinHeader_2.54mm:PinHeader_1x02_P2.54mm_Vertical
1 | J15 | RS485_1 | Connector_PinHeader_2.54mm:PinHeader_1x02_P2.54mm_Vertical
3 | L1 L2 L3 | 33uH | Inductor_SMD:L_Bourns_SRN6045TA
1 | R2 | 3.3K | Resistor_SMD:R_0402_1005Metric
1 | R3 | 470 | Resistor_SMD:R_0402_1005Metric
2 | R4 R7 | 1.5K | Resistor_SMD:R_0402_1005Metric
2 | R1 R5 | 1K | Resistor_SMD:R_0402_1005Metric
1 | R6 | 100 | Resistor_SMD:R_0402_1005Metric
2 | R8 R9 | 4.7K | Resistor_SMD:R_0402_1005Metric
1 | R10 | 10K | Resistor_SMD:R_0402_1005Metric
4 | R11 R12 R13 R14 | 470R | Resistor_SMD:R_0402_1005Metric
1 | SW1 | BTN0 | Button_Switch_SMD:SW_SPST_TL3342
1 | SW2 | BTN1 | Button_Switch_SMD:SW_SPST_TL3342
1 | U1 | LM2596S-5 | Package_TO_SOT_SMD:TO-263-5_TabPin3
2 | U2 U3 | LM2596S-ADJ | Package_TO_SOT_SMD:TO-263-5_TabPin3
4 | U4 U8 U10 U12 | TPD4S012 | Package_DFN_QFN:UQFN-10_1.4x1.8mm_P0.4mm
4 | U5 U9 U11 U13 | TPS2041B | Package_TO_SOT_SMD:SOT-23-5
1 | U6 | USB3320 | Package_DFN_QFN:QFN-32-1EP_5x5mm_P0.5mm_EP3.1x3.1mm
1 | U7 | USB5744 | Package_DFN_QFN:QFN-48-1EP_6x6mm_P0.4mm_EP4.25x4.25mm
2 | U14 U15 | RTL8211F-CG | Package_DFN_QFN:QFN-48-1EP_6x6mm_P0.4mm_EP4.25x4.25mm
2 | U16 U20 | TPD12S016 | Package_DFN_QFN:QFN-24-1EP_4x4mm_P0.5mm_EP2.7x2.7mm
1 | U17 | IT6801FN | Package_QFP:LQFP-64_10x10mm_P0.5mm
1 | U18 | TXB0108 | Package_SO:TSSOP-20_4.4x6.5mm_P0.65mm
1 | U19 | IT66121FN | Package_QFP:LQFP-64_10x10mm_P0.5mm
1 | U21 | CP2102N | Package_DFN_QFN:QFN-28-1EP_5x5mm_P0.5mm_EP3.35x3.35mm
2 | U23 U25 | MAX485 | Package_SO:SOIC-8_3.9x4.9mm_P1.27mm
2 | U22 U24 | SN65HVD230 | Package_SO:SOIC-8_3.9x4.9mm_P1.27mm
2 | Y1 Y2 | 25MHz | Crystal:Crystal_SMD_3215-2Pin_3.2x1.5mm
2 | Y3 Y4 | 27MHz | Crystal:Crystal_SMD_3215-2Pin_3.2x1.5mm

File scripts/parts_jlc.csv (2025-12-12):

lcsc_id | ref_prefix | comment | footprint_hint | notes
C25804 | R | 10k 0402 1% | 0402 | Basic resistor
C25752 | R | 4.7k 0402 1% | 0402 | Basic resistor
C25905 | R | 1k 0402 1% | 0402 | Basic resistor
C11702 | C | 100nF 0402 X7R 16V | 0402 | Decoupling cap
C19702 | C | 10uF 0805 X5R 25V | 0805 | Bulk cap
C14663 | C | 1uF 0402 X5R 16V | 0402 | Decoupling cap
C347421 | U | LM2596S-5.0 TO-263 | TO-263-5 | 5V Buck regulator
C29781 | U | LM2596S-ADJ TO-263 | TO-263-5 | Adjustable Buck regulator
C35722 | D | SS34 Schottky SMA | SMA | 3A 40V Schottky
C90748 | L | 33uH 3A Inductor | 12x12mm | Power inductor
C72505 | C | 470uF 25V Electrolytic | 8x10.5mm | Input cap
C72499 | C | 220uF 25V Electrolytic | 6.3x7.7mm | Output cap
C2286 | D | LED Green 0603 | 0603 | Power LED
C2290 | D | LED Red 0603 | 0603 | Power LED
C72038 | R | 330R 0402 1% | 0402 | LED resistor
C25077 | R | 1.5k 0402 1% | 0402 | Feedback resistor
C25087 | R | 470R 0402 1% | 0402 | Feedback resistor
C381125 | J | DC Jack 5.5x2.1mm | Through-hole | 12V input

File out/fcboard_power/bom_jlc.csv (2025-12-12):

Comment | Designator | Footprint | JLCPCB Part #
DC Jack 12V | J1
LM2596S-5.0 | U1
220uF/25V | C1
220uF/10V | C2
33uH | L1
SS34 | D1
Green | D2
1k | R1
LM2596S-ADJ | U2
3.3k | R2
1k | R3
10uF | C3
220uF/10V | C4
33uH | L2
SS34 | D3
Yellow | D4
470 | R4
LM2596S-ADJ | U3
1.5k | R5
1k | R6
10uF | C5
100uF/10V | C6
33uH | L3
SS34 | D5
Red | D6
100 | R7
100nF | C7
100nF | C8
100nF | C9

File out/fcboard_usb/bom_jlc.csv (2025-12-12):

Comment | Designator | Footprint | JLCPCB Part #
USB5744 | U1 |  | C132563
24MHz | Y1
18pF | C1
18pF | C2
10k | R1
100nF | C3
10uF | C4
USB-A Port 1 | J1
USB-A Port 2 | J2
USB-A Port 3 | J3
USB-A Port 4 | J4
USB3320 | U2 |  | C132942
10k | R2
100nF | C5
10uF | C6
100uF | C7
100nF | C8

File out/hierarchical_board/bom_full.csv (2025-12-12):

Designator | Value | Footprint | LCSC | MPN | Manufacturer | Description | DNP | Qty
J1 | DC Jack 12V |  |  |  |  |  |  | 1
U1 | LM2596S-5.0 |  |  | LM2596S-5.0/NOPB | Texas Instruments | 5V 3A Step-Down Regulator |  | 1
C1,C2 | 220uF |  | C134799 |  | Nichicon |  |  | 2
L1 | 33uH |  |  |  |  |  |  | 1
D1 | SS34 |  |  |  |  |  |  | 1
D2 | Green |  |  |  |  | Optional power indicator LED | Yes | 1
R1 | 1k |  |  |  |  | LED current limiting resistor | Yes | 1
J2 | USB-A |  |  |  |  |  |  | 1
C3 | 100nF |  |  |  |  |  |  | 1
C4 | 10uF |  |  |  |  |  |  | 1
R2,R3 | 22R |  | C17560 | RC0402FR-0722RL | Yageo |  |  | 2

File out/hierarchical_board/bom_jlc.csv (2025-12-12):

Comment | Designator | Footprint | JLCPCB Part #
DC Jack 12V | J1
LM2596S-5.0 | U1
220uF | C1,C2 |  | C134799
33uH | L1
SS34 | D1
USB-A | J2
100nF | C3
10uF | C4
22R | R2,R3 |  | C17560

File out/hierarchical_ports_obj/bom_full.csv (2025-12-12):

Designator | Value | Footprint | LCSC | MPN | Manufacturer | Description | DNP | Qty
J1 | DC Jack |  |  |  |  |  |  | 1
U1 | LM2596S-5.0 |  |  | LM2596S-5.0/NOPB | Texas Instruments |  |  | 1
C1,C2 | 220uF |  |  |  |  |  |  | 2
R1,R2 | 10k |  | C17414 |  |  |  |  | 2
C3 | 100nF |  |  |  |  |  |  | 1

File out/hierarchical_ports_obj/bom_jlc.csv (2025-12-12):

Comment | Designator | Footprint | JLCPCB Part #
DC Jack | J1
LM2596S-5.0 | U1
220uF | C1,C2
10k | R1,R2 |  | C17414
100nF | C3

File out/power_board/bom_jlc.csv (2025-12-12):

Comment | Designator | Footprint | JLCPCB Part #
DC Jack 12V | J1
LM2596S-5.0 | U1
100uF | C1
220uF | C2
33uH | L1
SS34 | D1
Green | D2
1k | R1
LM2596S-ADJ | U2
10uF | C3
100uF | C4
33uH | L2
SS34 | D3
Yellow | D4
330 | R2

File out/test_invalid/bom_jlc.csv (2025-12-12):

Comment | Designator | Footprint | JLCPCB Part #
10k | R1
4.7k | R2

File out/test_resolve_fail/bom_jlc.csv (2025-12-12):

Comment | Designator | Footprint | JLCPCB Part #
10k | R1
Unknown IC | U1

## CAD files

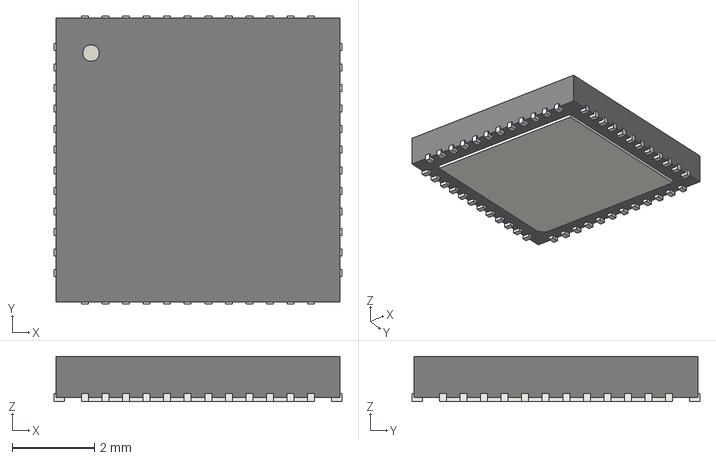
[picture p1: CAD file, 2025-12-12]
3dmodels/QFN-48-1EP_7x7mm_P0.5mm_EP5.6x5.6mm.step
7.00 x 7.00 x 1.10 mm

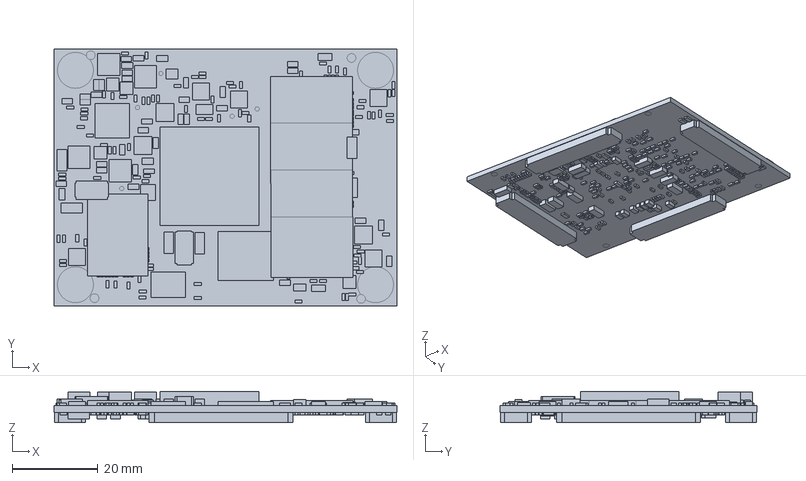
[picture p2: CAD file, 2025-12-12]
docs/ACU5EV/ACU5EV.1.1/ACU5EV.1.1.stp
80.0 x 60.0 x 7.29 mm
BOARD_OUTLINE
OSC3_2X2_5
L4_2X4_2 x 3
L5_2X5_2 x 4
L0603 x 6
LED_0805 x 2
CC0805 x 15
D7343 x 2
C1206 x 17
MLP8-1
SX2-3215
DSBGA8
VSON-10 x 2
CC0402 x 211
RR0402 x 145
TSSOP8
6-TDFN-EP
TLV62130RGT
TP x 6
CC0603 x 43
SOT23-5
CSD87381P x 3
VQFN64
AXK5A2137YG x 4
VFBGA_13X11_5
TPS51200DRCR x 2
OSC6-3225
WSON-08MM
MH_250H125 x 4
SFVC784
MT40A256M16GE-075E x 5
FID_C40M80 x 8

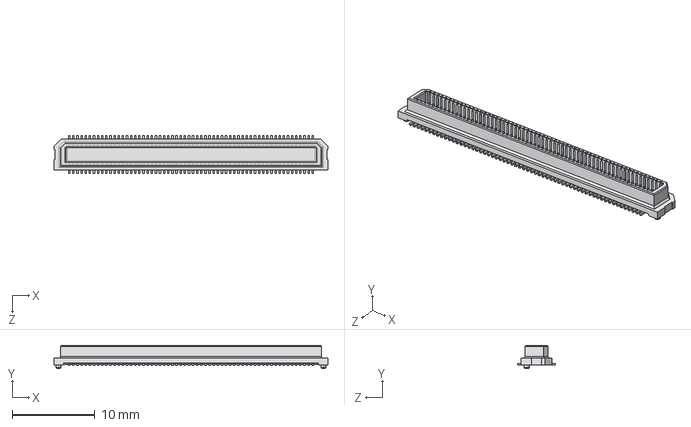
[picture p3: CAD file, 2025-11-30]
down/AXK6A2337YG/AXK6A2337YG.step
33.2 x 2.80 x 4.60 mm
AXK6A2337YG_AXK6A2347YG
pin^AXK6A2337YG ass x 120

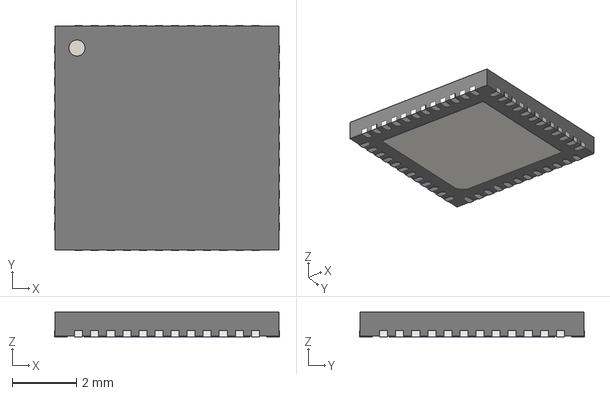
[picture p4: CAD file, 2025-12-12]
3dmodels/QFN-48-1EP_7x7mm_P0.5mm_EP5.15x5.15mm.step
7.00 x 7.00 x 0.77 mm

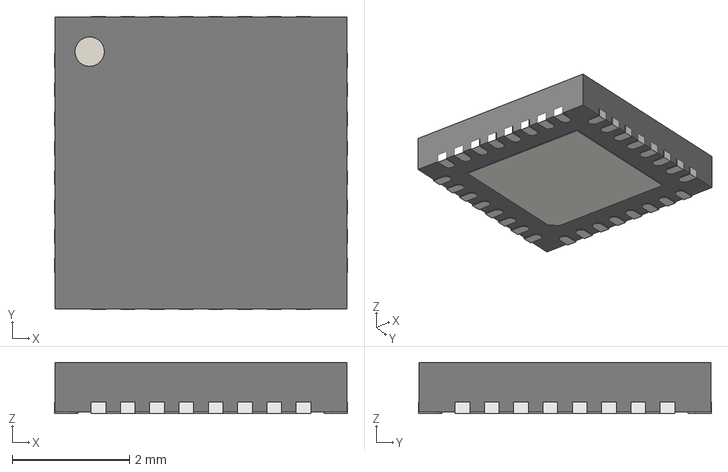
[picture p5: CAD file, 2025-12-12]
3dmodels/QFN-32-1EP_5x5mm_P0.5mm_EP3.3x3.3mm.step
5.00 x 5.00 x 0.875 mm

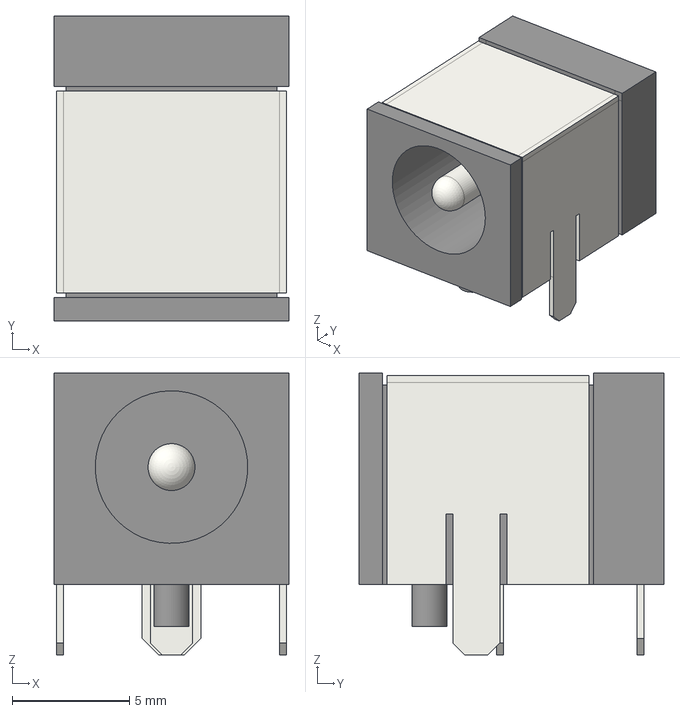
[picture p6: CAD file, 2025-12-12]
3dmodels/BarrelJack_Horizontal.step
10.0 x 13.0 x 12.0 mm

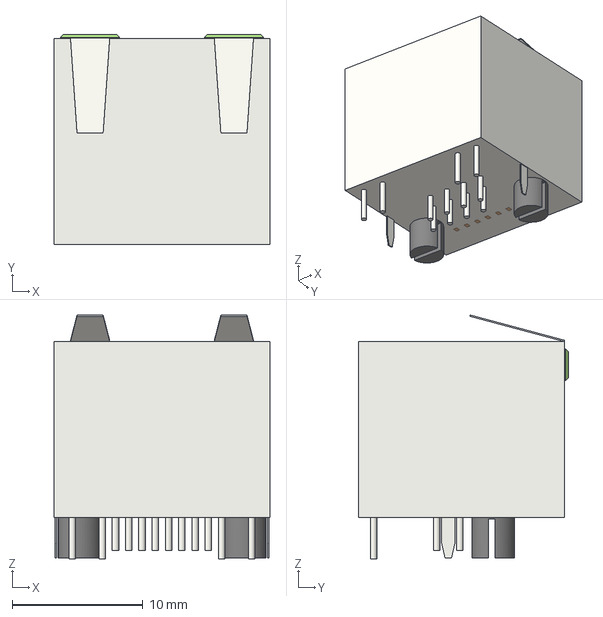
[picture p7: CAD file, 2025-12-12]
3dmodels/RJ45_Hanrun_HR911105A_Horizontal.step
16.5 x 16.1 x 18.7 mm

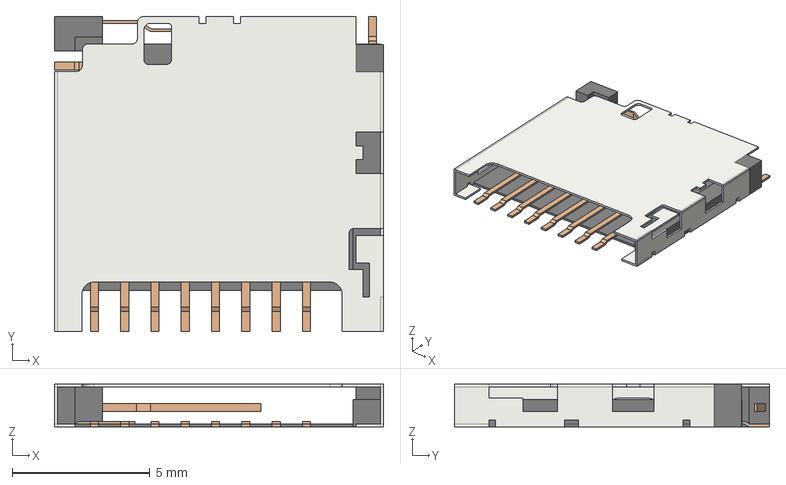
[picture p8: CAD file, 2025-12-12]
3dmodels/microSD_HC_Wuerth_693072010801.step
11.9 x 11.5 x 1.55 mm

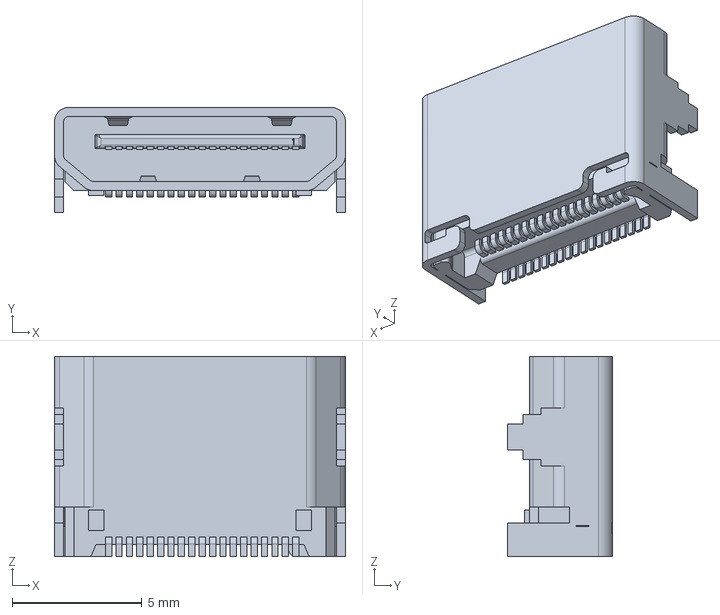
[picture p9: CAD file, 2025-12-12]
3dmodels/HDMI_A.step
11.2 x 4.05 x 7.70 mm

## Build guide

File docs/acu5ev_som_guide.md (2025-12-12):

# ALINX ACU5EV SoM 가이드

## 제품 개요

ALINX ACU5EV는 AMD/Xilinx Zynq UltraScale+ MPSoC XCZU5EV 기반 System-on-Module(SoM)입니다.

| 항목 | 사양 |
|---|---|
| FPGA | XCZU5EV-2SFVC784I |
| 크기 | 80mm × 60mm |
| PCB | 16층, 침금(Immersion Gold) |
| 전원 | +12V 단일 전원 |
| 커넥터 | 4× Panasonic AXK6A2337YG (120핀) |
| 동작 온도 | -40°C ~ +85°C |

---

## 프로세서 사양

### Processing System (PS)

| 항목 | 사양 |
|---|---|
| Application Processor | 4× ARM Cortex-A53 @ 1.333GHz |
| Real-Time Processor | 2× ARM Cortex-R5F @ 533MHz |
| GPU | ARM Mali-400 MP2 |
| Video Codec | H.264/H.265 VCU |

### Programmable Logic (PL)

| 항목 | 사양 |
|---|---|
| Logic Cells | 256K |
| CLB Flip-Flops | 234K |
| LUTs | 117K |
| UltraRAM | 18.0Mb |
| Block RAM | 11.0Mb |
| DSP Slices | 1,248 |

---

## 메모리 구성

| 메모리 | 용량 | 버스 | 속도 |
|---|---|---|---|
| PS DDR4 | 4GB | 64-bit | 2400Mbps |
| PL DDR4 | 1GB | 16-bit | 2400Mbps |
| eMMC Flash | 8GB | - | - |
| QSPI Flash | 256Mbit (32MB) | - | - |

---

## 고속 인터페이스

### PS 측

| 인터페이스 | 사양 |
|---|---|
| PCIe | Gen2 ×4 |
| USB | 2× USB 3.0 |
| SATA | SATA 3.1 |
| DisplayPort | DP 1.2 |
| Ethernet | 4× Tri-mode GbE |
| PS-GTR | 4× (최대 6Gbps) |

### PL 측

| 인터페이스 | 사양 |
|---|---|
| GTH Transceiver | 16× (최대 16.3Gbps) |
| PCIe | Gen3 ×4 |
| HP I/O | 96개 |
| HD I/O | 84개 |

---

## 커넥터 사양

### Panasonic AXK6A2337YG

| 항목 | 사양 |
|---|---|
| 핀 수 | 120핀 (2열) |
| 피치 | 0.5mm |
| 메이팅 높이 | 3.0mm |
| 타입 | SMD, Vertical |
| 접점 | Gold plating |

**메이팅 커넥터:** AXK5A2337YG (캐리어 보드용)

---

## SoM 커넥터 배치

### 뒷면 배치도

```
                    80mm
    ┌─────────────────────────────────────┐
    │                                     │
    │   ┌─────┐              ┌─────┐     │
    │   │ J29 │              │ J30 │     │
    │   │     │              │     │     │
    │   └─────┘              └─────┘     │ 60mm
    │                                     │
    │   ┌─────┐              ┌─────┐     │
    │   │ J31 │              │ J32 │     │
    │   │     │              │     │     │
    │   └─────┘              └─────┘     │
    │                                     │
    └─────────────────────────────────────┘
```

### 커넥터 기능

| 커넥터 | Bank | 주요 기능 |
|---|---|---|
| J29 | BANK65/66 | HDMI I/O, MIPI, Ethernet PL |
| J30 | MGT505/BANK25/26 | PCIe ×2, SFP+ ×2 |
| J31 | BANK24/44 | RS485, GPIO, LED |
| J32 | PS MIO/Power | USB, Ethernet PS, +12V |

---

## 커넥터별 핀맵 요약

### J29 - HDMI, MIPI, Ethernet PL

| 핀 | 용도 |
|----|---|
| 1-7 | MIPI CSI-2 (CLK, D0, D1) |
| 13-50 | HDMI 입력 (24-bit + 제어) |
| 58-75 | Ethernet PL RGMII |
| 76-110 | HDMI 출력 (24-bit + 제어) |
| 111-112 | PL CLK 200MHz |

### J30 - PCIe, SFP

| 핀 | 용도 |
|----|---|
| 1-2 | PCIe RefCLK |
| 3-11 | PCIe TX/RX ×2 |
| 13-21 | SFP+ TX/RX ×2 |
| 22-23 | SFP RefCLK |
| 25-86 | Reserved |

### J31 - Peripherals

| 핀 | 용도 |
|----|---|
| 1-7 | RS485 ×2 |
| 8-9 | PL_LED ×2 |
| 10-11 | PL_KEY ×2 |
| 13 | FAN_PWM |
| 14-62 | Reserved |

### J32 - USB, Ethernet PS, Power

| 핀 | 용도 |
|----|---|
| 29-31 | I2C1 |
| 38-41 | CAN1 |
| 41-55 | Ethernet PS RGMII |
| 56-61 | SD Card |
| 63-77 | USB0 ULPI |
| 99-104 | VCCO 1.8V |
| 107-120 | +12V (14핀) |

---

## 캐리어 보드 설계

### 권장 보드 크기

- 최소: 100mm × 80mm
- 권장: 150mm × 100mm

### 커넥터 배치 좌표

보드 중심 (75mm, 50mm) 기준:

| 커넥터 | X | Y |
|---|---|---|
| J29 | 55mm | 35mm |
| J30 | 95mm | 35mm |
| J31 | 55mm | 65mm |
| J32 | 95mm | 65mm |

### 커넥터 간격

- 수평: 40mm (J29-J30, J31-J32)
- 수직: 30mm (J29-J31, J30-J32)

---

## 전원 요구사항

| 전압 | 용도 | 공급 |
|---|---|---|
| +12V | SoM 메인 | J32 핀 107-120 |
| +1.8V | BANK65/66 VCCO | J32 핀 99-104 |

예상 전류: 2-5A (부하에 따라)

---

## 참고 자료

- [ALINX ACU5EV 공식](https://www.en.alinx.com/Product/SoC-System-on-Modules/Zynq-UltraScale-plus-MPSoC/ACU5EV.html)
- [CodeRobin ACU5EV](https://coderobin.com/products/alinx-acu5ev-xilinx-zynq-ultrascale-mpsoc-xczu5ev-fpga-som)
- [JLCPCB AXK6A2337YG](https://jlcpcb.com/partdetail/PANASONIC-AXK6A2337YG/C2843222)
- [SnapEDA Footprint](https://www.snapeda.com/parts/AXK6A2337YG/Panasonic/view-part/)

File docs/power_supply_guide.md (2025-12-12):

# fcBoard 전원 공급 회로 가이드

## 개요

fcBoard는 DC 12V 입력을 받아 3개의 전압 레일을 생성합니다:
- **+5V** - USB, 일부 주변장치
- **+3V3** - 대부분의 디지털 IC
- **+1V8** - HDMI 칩 내부 코어

```
DC 12V Input (J16)
       │
       ▼
   +12V_IN (글로벌 네트)
       │
       ├──► U28 (LM2596S-5)    ──► +5V
       │
       ├──► U26 (LM2596S-ADJ)  ──► +3V3
       │
       └──► U27 (LM2596S-ADJ)  ──► +1V8
```

---

## 전원 입력

### DC Barrel Jack (J16)
| 항목 | 사양 |
|---|---|
| 커넥터 | 5.5mm x 2.1mm Barrel Jack |
| 입력 전압 | DC 12V |
| 권장 전류 | 5A 이상 |
| 극성 | Center Positive |

**주의사항:**
- 입력 전압 범위: 10V ~ 15V (LM2596 스펙 기준)
- 역극성 보호 없음 - 극성 확인 필수

---

## 전압 레귤레이터

### U28: LM2596S-5 (+5V 출력)

| 파라미터 | 값 |
|---|-----|
| IC | LM2596S-5 (고정 5V 출력) |
| 입력 | +12V_IN |
| 출력 | +5V |
| 최대 전류 | 3A |
| 패키지 | TO-263-5 |

**핀 연결:**
| 핀 | 이름 | 연결 |
|----|---|---|
| 1 | VIN | +12V_IN |
| 2 | OUT | +5V (인덕터 통해) |
| 3 | GND | GND |
| 4 | FB | 내부 연결 (고정 출력) |
| 5 | ON/OFF | GND (상시 ON) |

**외부 부품:**
- L4: 33µH 인덕터 (Bourns SRN6045TA)
- D11: SS34 쇼트키 다이오드
- C20: 220µF 입력 커패시터
- C_out: 220µF 출력 커패시터

**+5V 사용처:**
- USB5744 USB Hub (VIN)
- TPS2041B USB 전원 스위치 (U7-U10)
- LED 표시등 (D12)

---

### U26: LM2596S-ADJ (+3V3 출력)

| 파라미터 | 값 |
|---|-----|
| IC | LM2596S-ADJ (가변 출력) |
| 입력 | +12V_IN |
| 출력 | +3V3 |
| 최대 전류 | 3A |
| 패키지 | TO-263-5 |

**핀 연결:**
| 핀 | 이름 | 연결 |
|----|---|---|
| 1 | VIN | +12V_IN |
| 2 | OUT | +3V3 (인덕터 통해) |
| 3 | GND | GND |
| 4 | FB | 저항 분배기 |
| 5 | ON/OFF | GND (상시 ON) |

**출력 전압 설정:**
```
Vout = Vref × (1 + R1/R2)
Vref = 1.23V

3.3V 출력의 경우:
R1 = 1.5KΩ (R16)
R2 = 1KΩ (또는 계산값)

Vout = 1.23 × (1 + 1.5K/0.73K) ≈ 3.3V
```

**외부 부품:**
- L5: 33µH 인덕터
- D13: SS34 쇼트키 다이오드
- C21: 220µF 입력 커패시터
- C_out: 220µF 출력 커패시터
- R16, R17: FB 저항 분배기

**+3V3 사용처:**
- USB3320 ULPI PHY (U1)
- USB5744 USB Hub (VDD33)
- RTL8211F-CG Ethernet PHY (U11, U12)
- IT6801FN HDMI 수신기 (VDD33)
- IT66121FN HDMI 송신기 (VDD33)
- SN65HVD230 CAN 트랜시버 (U13, U14)
- MAX485 RS485 트랜시버 (U15, U16)
- CP2102N USB-UART (U17)
- TPD4S012 ESD 보호 (U3-U6)
- TPD12S016 HDMI ESD (U44, U45)
- LED 표시등 (D15)

---

### U27: LM2596S-ADJ (+1V8 출력)

| 파라미터 | 값 |
|---|-----|
| IC | LM2596S-ADJ (가변 출력) |
| 입력 | +12V_IN |
| 출력 | +1V8 |
| 최대 전류 | 3A |
| 패키지 | TO-263-5 |

**핀 연결:**
| 핀 | 이름 | 연결 |
|----|---|---|
| 1 | VIN | +12V_IN |
| 2 | OUT | +1V8 (인덕터 통해) |
| 3 | GND | GND |
| 4 | FB | 저항 분배기 |
| 5 | ON/OFF | GND (상시 ON) |

**출력 전압 설정:**
```
Vout = Vref × (1 + R1/R2)
Vref = 1.23V

1.8V 출력의 경우:
R1 = 약 470Ω
R2 = 1KΩ

Vout = 1.23 × (1 + 0.47K/1K) ≈ 1.8V
```

**외부 부품:**
- L6: 33µH 인덕터
- D14: SS34 쇼트키 다이오드
- C22: 470µF 입력 커패시터
- C_out: 220µF 출력 커패시터
- R15, R20: FB 저항 분배기

**+1V8 사용처:**
- IT6801FN HDMI 수신기 (VDD18 - 내부 코어)
- IT66121FN HDMI 송신기 (VDD18 - 내부 코어)
- LED 표시등 (D16)

---

## LED 전원 표시등

각 전압 레일에 LED 표시등이 연결되어 전원 상태를 표시합니다:

| LED | 전압 | 저항 | 저항값 | LED 전류 |
|-----|---|---|---|---|
| D12 | +5V | R21 | 1KΩ | ~3mA |
| D15 | +3V3 | R18 | 470Ω | ~4mA |
| D16 | +1V8 | R19 | 3.3KΩ | ~0.2mA |

**회로:**
```
+5V  ──►──  D12 (LED_5V)  ──  R21 (1K)  ──  GND
+3V3 ──►──  D15 (LED_3V3) ──  R18 (470) ──  GND
+1V8 ──►──  D16 (LED_1V8) ──  R19 (3.3K) ── GND
```

**참고:** +1V8 LED는 순방향 전압(Vf ~1.6V)이 공급 전압에 가까워 밝기가 약할 수 있음

---

## 전원 네트 구조

### 파워 심볼 기반 연결

KiCad에서 파워 심볼은 **글로벌 네트**로 작동합니다. 즉, 같은 이름의 파워 심볼은 모든 시트에서 자동으로 연결됩니다.

| 파워 심볼 | 라이브러리 | 설명 |
|---|---|---|
| +12V_IN | fcBoard | DC 입력 (커스텀) |
| +5V | power | 5V 레일 |
| +3V3 | power | 3.3V 레일 |
| +1V8 | power | 1.8V 레일 |
| GND | power | 공통 접지 |

### 시트별 전원 사용

| 시트 | +12V_IN | +5V | +3V3 | +1V8 | GND |
|---|---|-----|---|---|-----|
| Power | ✓ | ✓ | ✓ | ✓ | ✓ |
| USB | - | ✓ | ✓ | - | ✓ |
| Ethernet | - | - | ✓ | - | ✓ |
| HDMI | - | - | ✓ | ✓ | ✓ |
| Peripherals | - | - | ✓ | - | ✓ |

---

## 전류 예산

### +5V 레일 (최대 3A)
| 부하 | 예상 전류 |
|---|---|
| USB5744 Hub | 100mA |
| USB 포트 x4 | 2A (각 500mA) |
| LED D12 | 3mA |
| **합계** | ~2.1A |

### +3V3 레일 (최대 3A)
| 부하 | 예상 전류 |
|---|---|
| USB3320 | 50mA |
| USB5744 (3.3V) | 100mA |
| RTL8211F x2 | 200mA |
| IT6801FN (3.3V) | 100mA |
| IT66121FN (3.3V) | 100mA |
| CAN/RS485/UART | 50mA |
| ESD 보호 IC | 10mA |
| LED D15 | 4mA |
| **합계** | ~600mA |

### +1V8 레일 (최대 3A)
| 부하 | 예상 전류 |
|---|---|
| IT6801FN (1.8V) | 150mA |
| IT66121FN (1.8V) | 150mA |
| LED D16 | 0.2mA |
| **합계** | ~300mA |

---

## 열 설계 고려사항

### LM2596 효율
- 일반적인 효율: 75-85%
- 입력-출력 전압 차이가 클수록 손실 증가

### 발열 계산 예시 (U28: 12V→5V, 2A)
```
Pin = 12V × 2A = 24W
Pout = 5V × 2A = 10W
효율 80% 가정 시:
Ploss = 24W × 0.2 = 4.8W
```

**권장사항:**
- TO-263 패키지의 탭을 PCB GND 플레인에 충분히 연결
- 고전류 사용 시 방열판 고려
- 열 비아 추가 권장

---

## PCB 레이아웃 가이드라인

### 전원 트레이스 폭
| 전류 | 권장 폭 (1oz Cu) |
|---|---|
| 1A | 0.5mm |
| 2A | 1.0mm |
| 3A | 1.5mm |

### 배치 권장사항
1. 입력 커패시터를 VIN 핀 가까이 배치
2. 출력 커패시터를 OUT 핀 가까이 배치
3. FB 저항 분배기를 FB 핀 가까이 배치
4. 인덕터와 다이오드 루프 최소화
5. GND 플레인 연속성 유지

### 스위칭 노이즈 대책
- 입력/출력에 세라믹 커패시터 추가 (100nF~1µF)
- 고속 신호선과 전원 스위칭 노드 분리
- EMI 민감 회로 근처에 페라이트 비드 사용

---

## 트러블슈팅

### 출력 전압이 낮음
- 입력 전압 확인 (12V인지)
- 부하 전류 확인 (과부하?)
- FB 저항 분배기 값 확인

### 출력 전압이 높음
- FB 핀 연결 확인
- FB 저항 분배기 값 확인
- 부하 연결 확인 (무부하 시 약간 높을 수 있음)

### 과열
- 입력 전압 확인
- 부하 전류 측정
- 열 방출 경로 확인
- 효율 개선 고려 (더 낮은 입력 전압 또는 2단계 변환)

### LED가 안 켜짐
- 해당 전압 레일 출력 확인
- LED 극성 확인
- 저항값 확인

---

## 부품 리스트 (전원부)

| Reference | Part | Value | Footprint |
|---|---|---|---|
| J16 | DC Barrel Jack | 5.5x2.1mm | BarrelJack_Horizontal |
| U28 | LM2596S-5 | 5V/3A | TO-263-5 |
| U26 | LM2596S-ADJ | 3.3V/3A | TO-263-5 |
| U27 | LM2596S-ADJ | 1.8V/3A | TO-263-5 |
| L4, L5, L6 | Inductor | 33µH | Bourns SRN6045TA |
| D11, D13, D14 | Schottky | SS34 | SMA |
| D12 | LED | Green | 0603 |
| D15 | LED | Green | 0603 |
| D16 | LED | Green | 0603 |
| C20, C21, C23 | Capacitor | 220µF | SMD |
| C22 | Capacitor | 470µF | SMD |
| R21 | Resistor | 1KΩ | 0402 |
| R18 | Resistor | 470Ω | 0402 |
| R19 | Resistor | 3.3KΩ | 0402 |
| R15 | Resistor | 470Ω (FB, +1V8 상단) | 0402 |
| R20 | Resistor | 1KΩ (FB, +1V8 하단) | 0402 |
| R16 | Resistor | 1.5KΩ (FB, +3V3 하단) | 0402 |
| R17 | Resistor | 1KΩ (FB, +3V3 상단) | 0402 |

---

## 참고 자료

- [LM2596 데이터시트](https://www.ti.com/lit/ds/symlink/lm2596.pdf)
- [Switching Regulator Design Guide](https://www.ti.com/lit/an/slva477b/slva477b.pdf)
- KiCad 프로젝트: `fcBoard_Power.kicad_sch`

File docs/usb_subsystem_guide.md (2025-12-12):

# fcBoard USB 서브시스템 가이드

## 개요

fcBoard USB 서브시스템은 Zynq UltraScale+ MPSoC의 USB 3.0 포트를 4개의 외부 USB Type-A 포트로 확장합니다.

```
Zynq MPSoC USB 3.0 (PS)
         │
         ▼
    ┌─────────┐
    │ USB3320 │  ULPI PHY (U1)
    │  (U1)   │
    └────┬────┘
         │ USB 2.0 DP/DN
         ▼
    ┌─────────┐
    │ USB5744 │  4-Port USB 3.0 Hub (U2)
    │  (U2)   │
    └────┬────┘
         │
    ┌────┴────┬────────┬────────┐
    ▼         ▼        ▼        ▼
  Port1     Port2    Port3    Port4
  (J17)     (J18)    (J19)    (J20)
```

---

## 주요 IC

### U1: USB3320 - ULPI USB PHY

| 파라미터 | 값 |
|---|-----|
| 제조사 | Microchip (SMSC) |
| 기능 | USB 2.0 ULPI PHY |
| 패키지 | QFN-32 (5x5mm) |
| 전원 | 3.3V (VDD33), 1.8V (VDD18 내부 생성) |

**역할:**
- FPGA의 ULPI 인터페이스를 USB 2.0 물리 계층으로 변환
- USB5744 허브의 업스트림 포트에 연결

**ULPI 인터페이스 핀:**
| 신호 | 방향 | 핀 | 설명 |
|---|---|-----|---|
| DATA[7:0] | Bidir | 1-8 | 8비트 양방향 데이터 버스 |
| CLK | Output | 9 | 60MHz ULPI 클럭 출력 |
| DIR | Output | 10 | 데이터 방향 제어 |
| NXT | Output | 11 | 다음 데이터 요청 |
| STP | Input | 12 | 전송 정지 신호 |
| DP | Bidir | 13 | USB D+ |
| DN | Bidir | 14 | USB D- |

**전원 핀:**
| 핀 | 이름 | 연결 |
|----|---|---|
| 16 | VDD33 | +3V3 |
| 17 | VDD18 | 내부 1.8V LDO (외부 커패시터) |
| 15 | GND | GND |

**Zynq 연결 (ULPI):**
```
USB3320          Zynq UltraScale+
────────         ────────────────
DATA0   ◄──────► MIO52 (ULPI_D0)
DATA1   ◄──────► MIO53 (ULPI_D1)
DATA2   ◄──────► MIO54 (ULPI_D2)
DATA3   ◄──────► MIO55 (ULPI_D3)
DATA4   ◄──────► MIO56 (ULPI_D4)
DATA5   ◄──────► MIO57 (ULPI_D5)
DATA6   ◄──────► MIO58 (ULPI_D6)
DATA7   ◄──────► MIO59 (ULPI_D7)
CLK     ───────► MIO60 (ULPI_CLK)
DIR     ───────► MIO61 (ULPI_DIR)
NXT     ───────► MIO62 (ULPI_NXT)
STP     ◄─────── MIO63 (ULPI_STP)
```

---

### U2: USB5744 - 4-Port USB 3.0 Hub

| 파라미터 | 값 |
|---|-----|
| 제조사 | Microchip |
| 기능 | 4-Port USB 3.0 Super-Speed Hub |
| 패키지 | QFN-48 (7x7mm) |
| 전원 | 5V (VDD5), 3.3V (VDD33), 1.2V (내부 생성) |

**역할:**
- USB 2.0 업스트림을 4개의 USB 2.0 다운스트림으로 분배
- USB 3.0 Super-Speed 지원 (5Gbps)
- 각 포트별 전류 제한 지원

**업스트림 포트 (USB3320에서):**
| 신호 | 핀 | 설명 |
|---|-----|---|
| UP_DP | - | USB 2.0 D+ (USB3320 DP) |
| UP_DN | - | USB 2.0 D- (USB3320 DN) |

**다운스트림 포트 핀:**
| 포트 | D+ 핀 | D- 핀 | 연결 |
|---|---|---|---|
| DN1 | 13 | 14 | J17 (USB Port 1) |
| DN2 | 15 | 16 | J18 (USB Port 2) |
| DN3 | 17 | 18 | J19 (USB Port 3) |
| DN4 | 19 | 20 | J20 (USB Port 4) |

**ULPI 인터페이스 (업스트림):**
| 신호 | 핀 | 연결 |
|---|-----|---|
| CLK | 1 | USB3320.CLK |
| DIR | 2 | USB3320.DIR |
| NXT | 3 | USB3320.NXT |
| STP | 4 | USB3320.STP |
| DATA[0:7] | 5-12 | USB3320.DATA[0:7] |

**전원 핀:**
| 핀 | 이름 | 연결 | 설명 |
|----|---|---|---|
| 22 | VDD33 | +3V3 | 3.3V 디지털 전원 |
| 23 | VDD12 | 내부 LDO | 1.2V 코어 (외부 커패시터) |
| - | VDD5 | +5V | 5V 입력 (VBUS 생성용) |
| 21 | GND | GND | 접지 |

---

## USB 커넥터

### J17, J18, J19, J20: USB Type-A 커넥터

| 파라미터 | 값 |
|---|-----|
| 타입 | USB Type-A Female |
| 풋프린트 | Stewart SS-52100-001 Horizontal |

**핀 배치:**
| 핀 | 이름 | 연결 |
|----|---|---|
| 1 | VBUS | TPS2041B 출력 (+5V 스위치) |
| 2 | D- | USB5744 DNx_DN (ESD 보호 후) |
| 3 | D+ | USB5744 DNx_DP (ESD 보호 후) |
| 4 | GND | GND |
| Shell | Shield | GND (페라이트 비드 통해) |

---

## 전원 스위치

### U7, U8, U9, U10: TPS2041B - USB 전원 스위치

| 파라미터 | 값 |
|---|-----|
| 제조사 | Texas Instruments |
| 기능 | 단일 채널 전류 제한 전원 스위치 |
| 패키지 | SOT-23-5 |
| 전류 제한 | 500mA (내부 설정) |

**역할:**
- 각 USB 포트에 VBUS (+5V) 공급
- 과전류 보호 (500mA 제한)
- 소프트 스타트 (돌입 전류 제한)
- 폴트 표시 출력

**핀 연결:**
| 핀 | 이름 | 연결 | 설명 |
|----|---|---|---|
| 1 | VIN | +5V | 5V 전원 입력 |
| 2 | VOUT | USB VBUS | 스위치 출력 |
| 3 | EN | 제어 신호/+3V3 | 활성화 (Active Low) |
| 4 | FAULT | 폴트 표시 | 과전류 시 Low 출력 |
| 5 | GND | GND | 접지 |

**포트별 할당:**
| IC | USB 포트 | EN 제어 |
|----|---|---|
| U7 | J17 (Port 1) | 상시 ON 또는 GPIO |
| U8 | J18 (Port 2) | 상시 ON 또는 GPIO |
| U9 | J19 (Port 3) | 상시 ON 또는 GPIO |
| U10 | J20 (Port 4) | 상시 ON 또는 GPIO |

---

## ESD 보호

### U3, U4, U5, U6: TPD4S012 - USB ESD 보호

| 파라미터 | 값 |
|---|-----|
| 제조사 | Texas Instruments |
| 기능 | 4채널 USB ESD 보호 |
| 패키지 | UQFN-10 (1.4x1.8mm) |
| ESD 내성 | ±8kV (접촉), ±15kV (공기) |

**역할:**
- USB 데이터 라인 (D+/D-) ESD 보호
- 낮은 기생 커패시턴스 (USB 2.0 High-Speed 호환)
- IEC 61000-4-2 레벨 4 준수

**핀 연결:**
| 핀 | 이름 | 연결 |
|----|---|---|
| 1 | D+ | USB5744 DNx_DP |
| 2 | D- | USB5744 DNx_DN |
| 3 | D+_OUT | USB 커넥터 D+ |
| 4 | D-_OUT | USB 커넥터 D- |
| 5 | GND | GND |
| 6 | VCC | +3V3 |

**포트별 할당:**
| IC | USB 포트 | 보호 대상 |
|----|---|---|
| U3 | J17 (Port 1) | DN1_DP, DN1_DN |
| U4 | J18 (Port 2) | DN2_DP, DN2_DN |
| U5 | J19 (Port 3) | DN3_DP, DN3_DN |
| U6 | J20 (Port 4) | DN4_DP, DN4_DN |

---

## 신호 연결도

### USB3320 ↔ USB5744 연결

```
USB3320 (U1)              USB5744 (U2)
─────────────             ───────────
CLK (9)      ──────────►  CLK (1)
DIR (10)     ──────────►  DIR (2)
NXT (11)     ──────────►  NXT (3)
STP (12)     ◄──────────  STP (4)
DATA0 (1)    ◄─────────►  DATA0 (5)
DATA1 (2)    ◄─────────►  DATA1 (6)
DATA2 (3)    ◄─────────►  DATA2 (7)
DATA3 (4)    ◄─────────►  DATA3 (8)
DATA4 (5)    ◄─────────►  DATA4 (9)
DATA5 (6)    ◄─────────►  DATA5 (10)
DATA6 (7)    ◄─────────►  DATA6 (11)
DATA7 (8)    ◄─────────►  DATA7 (12)
DP (13)      ◄─────────►  UP_DP
DN (14)      ◄─────────►  UP_DN
```

### USB5744 → USB 포트 연결

```
USB5744 (U2)    ESD (U3-U6)    Power (U7-U10)    Connector
────────────    ───────────    ──────────────    ─────────
DN1_DP (13) ──► TPD4S012 ──────────────────────► J17.D+ (3)
DN1_DN (14) ──► (U3)     ──────────────────────► J17.D- (2)
                              TPS2041B (U7) ───► J17.VBUS (1)

DN2_DP (15) ──► TPD4S012 ──────────────────────► J18.D+ (3)
DN2_DN (16) ──► (U4)     ──────────────────────► J18.D- (2)
                              TPS2041B (U8) ───► J18.VBUS (1)

DN3_DP (17) ──► TPD4S012 ──────────────────────► J19.D+ (3)
DN3_DN (18) ──► (U5)     ──────────────────────► J19.D- (2)
                              TPS2041B (U9) ───► J19.VBUS (1)

DN4_DP (19) ──► TPD4S012 ──────────────────────► J20.D+ (3)
DN4_DN (20) ──► (U6)     ──────────────────────► J20.D- (2)
                              TPS2041B (U10) ──► J20.VBUS (1)
```

---

## 전원 공급

### 전압 레일

| 전압 | 사용처 | 공급원 |
|---|---|---|
| +5V | TPS2041B VIN, USB VBUS | fcBoard_Power |
| +3V3 | USB3320, USB5744, TPD4S012 | fcBoard_Power |
| +1V8 | USB3320 내부 | 내부 LDO |
| +1V2 | USB5744 코어 | 내부 LDO |

### 전원 심볼 사용

| IC | 전원 핀 | 파워 심볼 |
|----|---|---|
| U1 (USB3320) | VDD33 | +3V3 |
| U2 (USB5744) | VDD33 | +3V3 |
| U2 (USB5744) | VDD5 | +5V |
| U3-U6 (TPD4S012) | VCC | +3V3 |
| U7-U10 (TPS2041B) | VIN | +5V |
| All | GND | GND |

---

## 바이패스 커패시터

각 IC에 적절한 바이패스 커패시터가 필요합니다:

| IC | 전원 | 권장 커패시터 |
|----|---|---|
| USB3320 | VDD33 | 100nF + 10µF |
| USB3320 | VDD18 | 1µF (LDO 출력) |
| USB5744 | VDD33 | 100nF + 10µF |
| USB5744 | VDD12 | 4.7µF (LDO 출력) |
| USB5744 | VDD5 | 100nF + 10µF |
| TPD4S012 | VCC | 100nF |
| TPS2041B | VIN | 100nF |

---

## PCB 레이아웃 가이드라인

### USB 2.0 차동 쌍

| 파라미터 | 권장값 |
|---|---|
| 임피던스 | 90Ω (차동) |
| 트레이스 폭 | 0.15mm (4층 기준) |
| 간격 | 0.15mm |
| 길이 매칭 | ±2.5mm 이내 |

### 배치 권장사항

1. **USB3320**: Zynq에 가깝게 배치 (ULPI 신호 길이 최소화)
2. **USB5744**: USB3320 근처에 배치
3. **TPD4S012**: 각 USB 커넥터에 최대한 가깝게
4. **TPS2041B**: 각 USB 커넥터에 가깝게
5. **크리스털**: USB3320 근처, GND 플레인 위

### GND 처리

- USB 커넥터 쉴드는 페라이트 비드를 통해 GND 연결
- 디지털 GND와 USB GND 분리 고려
- Star 접지 또는 단일 포인트 연결

---

## 소프트웨어 설정

### Zynq USB 컨트롤러

PetaLinux/Vivado에서 USB 컨트롤러 설정:

```
# Device Tree 예시
&usb0 {
    status = "okay";
    dr_mode = "host";
    phy-names = "usb3-phy";
    phys = <&lane2 PHY_TYPE_USB3 0 2 26000000>;
};
```

### USB3320 초기화

USB3320은 하드웨어 스트랩으로 자동 설정됩니다:
- REFCLK: 외부 26MHz 또는 내부 오실레이터
- 모드: ULPI

---

## 트러블슈팅

### USB 장치 인식 안 됨

1. VBUS 전압 확인 (4.75V ~ 5.25V)
2. TPS2041B EN 핀 상태 확인
3. TPS2041B FAULT 출력 확인
4. USB3320 CLK 출력 확인 (60MHz)

### 열거 실패

1. ULPI 신호 연결 확인
2. USB3320 전원 (3.3V) 확인
3. 바이패스 커패시터 확인
4. D+/D- 임피던스 확인

### 간헐적 연결 끊김

1. VBUS 전류 확인 (과전류?)
2. ESD 보호 IC 확인
3. 커넥터 접촉 상태 확인
4. EMI/노이즈 확인

### 전류 제한 동작

TPS2041B는 500mA에서 전류 제한:
- FAULT 핀이 Low로 변경
- 출력 전압 감소
- 열 차단 가능

---

## 부품 리스트

| Reference | Part | Value/Type | Footprint |
|---|---|---|---|
| U1 | USB3320 | ULPI PHY | QFN-32 (5x5mm) |
| U2 | USB5744 | USB 3.0 Hub | QFN-48 (7x7mm) |
| U3-U6 | TPD4S012 | ESD Protection | UQFN-10 |
| U7-U10 | TPS2041B | Power Switch | SOT-23-5 |
| J17-J20 | USB_A | Type-A Female | SS-52100-001 |
| C_bypass | Capacitor | 100nF | 0402 |
| C_bulk | Capacitor | 10µF | 0603 |
| FB | Ferrite Bead | 600Ω@100MHz | 0402 |

---

## 참고 자료

- [USB3320 데이터시트](https://ww1.microchip.com/downloads/en/DeviceDoc/00001792E.pdf)
- [USB5744 데이터시트](https://ww1.microchip.com/downloads/en/DeviceDoc/USB5744-Data-Sheet-DS00001855D.pdf)
- [TPS2041B 데이터시트](https://www.ti.com/lit/ds/symlink/tps2041b.pdf)
- [TPD4S012 데이터시트](https://www.ti.com/lit/ds/symlink/tpd4s012.pdf)
- KiCad 프로젝트: `fcBoard_USB.kicad_sch`

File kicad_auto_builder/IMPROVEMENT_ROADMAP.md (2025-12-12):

# KiCad Auto Builder 개선 로드맵

## 현재 버전: v1.3.0

**최종 업데이트:** 2025-12-12

---

## 소스 구조

```
kicad_auto_builder/
├── __init__.py           # 버전 정의 (__version__ = "1.3.0")
├── cli.py                # CLI 인터페이스 (build, validate 명령)
├── config_loader.py      # YAML 설정 파서
├── part_resolver.py      # LCSC 부품 리졸버
├── kicad_builder.py      # KiCad 파일 생성 (심볼, 풋프린트, 회로도, BOM)
├── net_validator.py      # 핀-넷 매칭 검증
├── templates/
│   ├── schematic.py      # 회로도 템플릿
│   └── symbol.py         # 심볼 템플릿 (BUILTIN_SYMBOLS)
└── examples/
    ├── fcboard_power.yaml
    ├── hierarchical_board.yaml
    ├── hierarchical_board_ports_obj.yaml  # v1.3 ports 객체 예제
    └── test_resolve_fail.yaml
```

---

## v1.3.0 완료 기능

### 1. 버전 단일화 (Single Source of Truth)
- `__init__.py`의 `__version__`이 유일한 버전 소스
- CLI, manifest.json, report.md, .kicad_sch 모두 동일 버전 표시

### 2. 타이틀 블록 동적 생성
```yaml
project:
  title_block:
    rev: "2.0"              # 리비전
    company: "My Company"   # 회사명
    date: "auto"            # "auto" 또는 "YYYY-MM-DD"
    comment1: "Description"
    comment2: "Additional info"
```

### 3. Ports 확장 명세
```yaml
ports:
  # 문자열 형식 (기존 호환)
  - "+5V"
  - "GND"

  # 객체 형식 (v1.3 확장)
  - name: "DATA0"
    shape: "bidirectional"  # input/output/bidirectional/passive
    side: "right"           # left/right (시트 심볼 핀 배치)
```

### 4. validate 커맨드
```bash
python -m kicad_auto_builder.cli validate config.yaml
# 파일 생성 없이 설정/리졸브/핀-넷 검증만 수행
```

### 5. BOM 고도화
- `bom_jlc.csv`: JLCPCB용 (DNP 제외, 수량 그룹화)
- `bom_full.csv`: 상세 BOM (MPN, Manufacturer, Description, DNP, Qty)
- `report.md`: 빌드 리포트 (통계, 부품목록, DNP목록, 시트정보)

---

## 향후 개선 방향 (vNEXT)

### P0 (필수)

| 항목 | 설명 | 복잡도 |
|---|---|---|
| **Role 매핑 확장** | 더 많은 부품 역할 지원 (op-amp, mosfet, relay 등) | 중 |
| **LCSC 캐시 고도화** | 캐시 만료/갱신 로직, 오프라인 모드 | 중 |
| **핀 위치 자동 계산** | 심볼 핀 좌표에서 라벨/와이어 위치 자동 계산 | 상 |

### P1 (권장)

| 항목 | 설명 | 복잡도 |
|---|---|---|
| **ERC 검증** | Electrical Rule Check (전원/접지 연결 검증) | 상 |
| **심볼 자동 생성** | LCSC 데이터시트에서 핀 정보 파싱 | 상 |
| **프로젝트 템플릿** | 자주 사용하는 회로 블록 템플릿 (USB, 전원, MCU 등) | 중 |
| **다중 출력 포맷** | Altium/Eagle 변환 지원 | 상 |

### P2 (선택)

| 항목 | 설명 | 복잡도 |
|---|---|---|
| **GUI 래퍼** | 웹/데스크톱 GUI 인터페이스 | 상 |
| **PCB 배치 힌트** | 회로도에서 PCB 배치 제약조건 주석 | 중 |
| **버전 관리 통합** | Git 커밋과 연동한 자동 리비전 | 하 |

---

## 제외 범위 (Out of Scope)

아래 기능은 현재 프로젝트 범위 외:
- PCB 레이아웃 (.kicad_pcb) 자동 생성
- 배치 최적화/오토라우팅
- DRC/LVS 검증
- Gerber 출력

---

## 사용법

### 빌드
```bash
# 단일 시트
python -m kicad_auto_builder.cli build examples/fcboard_power.yaml

# 계층 시트
python -m kicad_auto_builder.cli build examples/hierarchical_board.yaml

# Dry-run (파일 생성 없이 계획 확인)
python -m kicad_auto_builder.cli build examples/hierarchical_board.yaml --dry-run
```

### 검증
```bash
python -m kicad_auto_builder.cli validate examples/hierarchical_board.yaml
```

### 출력 파일
```
out/<project>/
├── <project>.kicad_sch     # 회로도 (단일 또는 루트)
├── <sheet>.kicad_sch       # 서브시트 (계층 모드)
├── lib/
│   ├── custom.kicad_sym    # 심볼 라이브러리
│   └── custom.pretty/      # 풋프린트 라이브러리
├── bom_jlc.csv             # JLCPCB BOM
├── bom_full.csv            # 상세 BOM
├── report.md               # 빌드 리포트
└── manifest.json           # 빌드 메타데이터
```

---

## YAML 스키마 (v1.3)

```yaml
project:
  name: "ProjectName"        # 필수
  kicad_version: 9           # 8 또는 9
  out_dir: "out/project"     # 출력 디렉토리
  title_block:               # v1.3 타이틀 블록 옵션
    rev: "1.0"
    company: "Auto Generated"
    date: "auto"
    comment1: ""
    comment2: ""

net_presets:
  VIN: "+12V"
  GND: "GND"

# 단일 시트 모드
parts:
  - ref: "R1"
    role: "resistor"
    lcsc: "C17414"
    value: "10k"
    nets:
      "1": "+5V"
      "2": "GND"
    # v1.3 BOM 필드
    mpn: "RC0402FR-0710KL"
    manufacturer: "Yageo"
    dnp: false
    description: "Pull-up resistor"

# 계층 시트 모드
sheets:
  - name: "Power"
    filename: "Power.kicad_sch"
    ports:                   # 문자열 또는 객체
      - "+5V"
      - name: "GND"
        shape: "passive"
        side: "left"
    parts:
      - ref: "U1"
        role: "buck_5v"
        ...
```

---

## 변경 이력

### v1.3.0 (2025-12-12)
- 버전 단일화 (`__version__` 기반)
- 타이틀 블록 동적 생성 (rev/company/date YAML 옵션)
- Ports 확장 명세 (shape/side 지원)
- `validate` CLI 커맨드 추가
- BOM 고도화 (MPN, manufacturer, DNP, 수량 그룹화)

### v1.2.0
- 계층 시트 지원 (sheets YAML 키)
- 루트/서브시트 자동 생성

### v1.1.0
- 핀-넷 검증 (net_validator)
- 와이어 자동 생성 (그리드 스냅, L자 라우팅)
- manifest.json 생성

### v1.0.0
- 초기 릴리스
- YAML 기반 설정
- LCSC 부품 리졸브
- 심볼/풋프린트 라이브러리 생성
- 회로도 자동 생성

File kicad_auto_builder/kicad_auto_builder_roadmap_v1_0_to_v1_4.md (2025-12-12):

# KiCad Auto Builder 로드맵 (v1.0 → v1.4) — 1페이지

## 0) 현 상태 (v1.0 완료)
- YAML 1개로 **부품 리졸브(LCSC/easyeda2kicad + role 매핑)** → **심볼/풋프린트 라이브러리 생성** → **회로도(.kicad_sch) 생성** → **JLC BOM 생성**까지 동작
- 회로도는 현재 “배치 + 라벨” 중심이며, **자동 wire 생성은 미구현(wires 비어 있음)**

## 1) 제품 목표(큰 틀)
**“설계 의도 입력 → 정합성 검증 → 회로/제조 산출물 생성 → 확장 가능한 자동화 플랫폼”**으로 발전  
- 신뢰성: 잘못된 핀/넷/풋프린트는 “즉시 발견”  
- 재현성: 동일 입력이면 동일 출력(버전/해시/manifest)  
- 확장성: 역할(role)/블록 템플릿을 코드 수정 없이 추가

---

## 2) 버전별 로드맵

### v1.1 — 안정화 핵심: 검증 + 연결
**기능**
- 핀-넷 검증 강화(내장 심볼 포함) + 에러 메시지 표준화(ref/role/pin_key/가능 핀 후보)
- net 라벨 좌표 기반 **wire 자동 생성(그리드 스냅/중복 제거/체인 연결)**
- YAML `value/footprint` override를 **LCSC 성공 여부와 무관하게 항상 우선 적용**

**산출물**
- `manifest.json`(리졸브 출처, 경고, 생성 파일 목록)
- 예제 YAML 3종(정상/핀오류/리졸브 실패) 고정

**완료 조건**
- 핀 오류는 빌드 중단(필수 부품), optional은 경고
- 동일 net이 2개 이상이면 `.kicad_sch`에 wire가 생성됨

---

### v1.2 — 규모 대응: 블록/시트화 + 템플릿 연결
**기능**
- YAML에 `sheet:` 또는 `block:` 도입 → Power/USB/IO 등 **계층 시트 생성**
- 블록 템플릿(예: buck_5v 표준 연결)으로 **규칙 기반 자동 연결**(최소 범위)

**산출물**
- 템플릿 카탈로그 문서 + 샘플 프로젝트 2종(전원보드, USB보드)

**완료 조건**
- 블록 2개 이상에서 시트 분리 생성 + 각 시트 간 글로벌 라벨/포트 연결 정상

---

### v1.3 — 제조 연계: BOM 고도화 + 리포트 체계
**기능**
- BOM 고도화: MPN/Manufacturer/대체품/수량 집계/DNP/옵션 BOM 분리
- 제조 리포트: 누락 풋프린트/심볼 불일치/리졸브 실패 원인 요약

**산출물**
- `bom_jlc.csv` 외 `bom_full.csv`(현업형), `report.md`(요약 리포트)

**완료 조건**
- 동일 부품 묶음 집계 정확 + 필수 제조 필드 누락 시 경고/오류 정책 일관

---

### v1.4 — PCB 자동화(선택/확장 단계)
**기능**
- (선택) `.kicad_pcb` 생성 기반 마련: 풋프린트 배치 프리셋, net class 기본 룰 세팅
- (선택) 외부 라우터/플러그인 연계 포인트 제공(내장 최적화는 범위 밖)

**산출물**
- `board_preset.yaml`(배치/룰 프리셋), 최소 동작 데모 프로젝트 1종

**완료 조건**
- PCB 파일 생성/열림 정상 + 기본 net class/룰이 적용되어 있음

---

## 3) 우선순위(권장 실행 순서)
1. **v1.1(검증+wire+manifest)**: 실사용 안정성 확보  
2. **v1.2(시트/블록/템플릿)**: 큰 설계 대응  
3. **v1.3(제조 산출물/리포트)**: 생산 연계  
4. **v1.4(PCB 자동화)**: “원클릭 보드” 확장

## 4) 운영 원칙(개발 규율)
- 스코프 관리: v1.1~v1.3은 “회로도 품질/제조 산출물” 중심, PCB 최적화는 v1.4 이후
- 회귀 방지: 예제 YAML 고정 + 최소 테스트 3개(정상/오류/경고)

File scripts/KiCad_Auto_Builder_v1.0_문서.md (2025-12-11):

# KiCad Auto Builder v1.0 사용 및 설계 문서

## 1. 개요

**KiCad Auto Builder v1.0**은 YAML 설정 파일 한 장으로 KiCad 회로도(.kicad_sch)와 심볼 라이브러리(.kicad_sym), 그리고 JLCPCB BOM(.csv)을 자동 생성하는 CLI 도구입니다.

- 목표
  - 부품 선택 → 심볼/풋프린트 수집 → 회로도 생성 → BOM 출력까지를 자동화
  - LCSC 부품 번호 및 내부 역할(role) 기반으로 회로를 빠르게 프로토타이핑

---

## 2. 설치 및 실행 환경

### 2.1 필수 환경

- Python 3.10 이상
- KiCad 8.x 포맷을 이해하는 사용자 (툴 자체는 KiCad 설치 없이도 동작 가능)
- OS: Windows / macOS / Linux

### 2.2 권장 도구

- `easyeda2kicad`
  - LCSC/LCSC 기반 EasyEDA 라이브러리에서 심볼/풋프린트 추출에 사용
  - 설치되어 있으면 KiCad Auto Builder가 자동으로 호출하여 심볼/풋프린트를 다운로드

---

## 3. 기본 사용법

### 3.1 기본 빌드

```bash
python -m kicad_auto_builder.cli build kicad_auto_builder/examples/power_board.yaml
```

### 3.2 Dry-run (실제 파일 생성 없이 확인)

```bash
python -m kicad_auto_builder.cli build power_board.yaml --dry-run
```

- YAML을 파싱하고, 부품/넷/역할 매핑 결과만 터미널 로그로 출력
- 실제 파일(`.kicad_sch`, `.kicad_sym`, `.csv`)은 생성하지 않음

### 3.3 출력 디렉터리 지정

```bash
python -m kicad_auto_builder.cli build power_board.yaml -o output/my_project
```

- 기본 `out/` 대신 지정한 디렉터리에 결과 파일 생성

---

## 4. 생성 결과 구조

기본 예시(`power_board.yaml`) 기준 디렉터리 구조는 다음과 같습니다.

```text
out/power_board/
├── lib/
│   └── custom.kicad_sym          # 자동 생성 심볼 라이브러리
├── PowerBoard_5V_3V3.kicad_sch   # 자동 생성 회로도
└── bom_jlc.csv                   # JLCPCB BOM CSV
```

- `lib/custom.kicad_sym`
  - LCSC/easyeda2kicad 및 내부 라이브러리에서 수집한 심볼을 통합한 라이브러리
- `PowerBoard_5V_3V3.kicad_sch`
  - YAML 설정을 기반으로 자동 배치된 회로도
- `bom_jlc.csv`
  - JLCPCB 업로드를 고려한 기본 BOM 포맷 (Comment, Designator, Footprint, LCSC Part# 등)

---

## 5. YAML 설정 파일 구조

기본 구조는 다음과 같습니다.

```yaml
project:
  name: "ProjectName"
  kicad_version: 8
  out_dir: "out/project"

net_presets:
  VIN: "VIN"
  V5: "+5V"
  GND: "GND"

parts:
  - ref: "U1"
    role: "buck_5v"           # 내부 역할 매핑 사용
    lcsc: "C12345"            # LCSC 부품번호
    value: "LM2596"
    nets:
      VIN: "VIN"
      VOUT: "+5V"
      GND: "GND"
```

### 5.1 `project` 섹션

- `name` : 프로젝트/회로도 이름 (예: `PowerBoard_5V_3V3`)
- `kicad_version` : 타깃 KiCad 포맷 버전 (현재 8 기준)
- `out_dir` : 출력 디렉터리 루트 경로

### 5.2 `net_presets` 섹션

자주 사용하는 넷 이름을 미리 정의하는 영역입니다.

- 키: 논리 키 (도구 내부에서 사용)
- 값: 실제 회로도에 표시될 넷 라벨

예:

```yaml
net_presets:
  VIN: "VIN"
  V5: "+5V"
  GND: "GND"
```

- 이후 `parts[].nets`에서 `VIN`, `VOUT`, `GND` 등으로 참조합니다.

### 5.3 `parts` 섹션

각 부품(Part)을 정의하는 리스트입니다.

#### 필드 설명

- `ref`
  - 회로도 상의 레퍼런스 (예: U1, R3, C10)
- `role`
  - 내부 역할 기반 템플릿 이름
  - 예: `buck_5v`, `resistor`, `capacitor`, `led` 등
  - 역할에 따라 기본 심볼/풋프린트/핀 구조를 매핑
- `lcsc`
  - LCSC 부품 번호 (예: `C12345`)
  - `easyeda2kicad`가 설치되어 있으면 해당 부품의 심볼/풋프린트를 자동 다운로드 후 사용
- `value`
  - 회로도에 표시될 값 (예: `LM2596`, `10k`, `100nF`)
- `nets`
  - 부품의 핀과 넷을 매핑하는 객체
  - 키: 핀 또는 역할명 (예: VIN, VOUT, GND)
  - 값: 실제 넷 이름(보통 `net_presets`에 정의된 값을 사용)

예:

```yaml
parts:
  - ref: "U1"
    role: "buck_5v"
    lcsc: "C12345"
    value: "LM2596"
    nets:
      VIN: "VIN"
      VOUT: "+5V"
      GND: "GND"
```

---

## 6. 지원 기능 요약

1. **내부 역할 매핑**
   - `buck_5v`, `resistor`, `capacitor`, `led` 등 역할 기반으로
   - 기본 심볼/풋프린트/핀 구조를 자동으로 선택

2. **LCSC 연동 (easyeda2kicad 사용)**
   - `lcsc` 필드를 통해 LCSC 번호를 지정하면
   - `easyeda2kicad` CLI를 호출하여 심볼/풋프린트 파일을 다운로드
   - 캐시 디렉터리를 사용하여 동일 부품의 중복 호출 최소화

3. **자동 배치**
   - 부품을 단순한 그리드 규칙으로 자동 배치
   - X/Y 좌표를 행/열 단위로 자동 계산하여 회로도에 배치

4. **JLCPCB BOM 생성**
   - `bom_jlc.csv` 파일 생성
   - 각 파트의 `ref`, `value`, `footprint`, `lcsc` 정보를 포함
   - JLCPCB 업로드용 기본 템플릿에 맞춘 컬럼 구성

---

## 7. 아키텍처 개요

KiCad Auto Builder는 크게 다음 3개 모듈로 구성됩니다.

1. **config_loader**
   - YAML 파일을 파싱하여 내부 도메인 모델(`ProjectConfig`, `PartSpec` 등)로 변환

2. **part_resolver**
   - `role`, `lcsc` 값을 기반으로
     - 내부 매핑
     - LCSC/easyeda2kicad 호출
   - 결과로 `ResolvedPart`(심볼 이름, footprint, 메타데이터)를 반환

3. **kicad_builder**
   - 모든 `ResolvedPart`를 입력으로 받아
     - `custom.kicad_sym` 심볼 라이브러리 생성
     - `.kicad_sch` 회로도 파일 생성
     - `bom_jlc.csv` BOM 파일 생성

CLI는 이 세 모듈을 순차적으로 호출하는 얇은 래퍼 역할을 합니다.

---

## 8. 향후 확장 아이디어

- **다중 시트 지원**
  - `sheets:` 섹션을 도입하여 시트별 부품 정의 및 별도 `.kicad_sch` 생성
- **회로 블록 템플릿**
  - `buck_5v`처럼 하나의 역할이 여러 부품(R/L/C 포함)을 자동 배치하도록 확장
- **웹 UI 연동**
  - YAML 대신 웹 폼/캔버스에서 부품을 입력 후
  - 서버에서 KiCad Auto Builder를 호출해 결과 ZIP 제공
- **PCB 자동 라우팅 연계**
  - 추후 PCBNew/FreeRouting 등과 연계하는 별도 모듈 추가

---

## 9. 요약

- KiCad Auto Builder v1.0은 **YAML 파일 하나로 회로도 + 심볼 라이브러리 + JLC BOM**을 자동 생성하는 도구입니다.
- 내부 역할(role)과 LCSC 연동을 통해
  - 반복적인 전원보드/공통모듈 설계를 빠르게 자동화할 수 있습니다.
- 현재 버전은 단일 시트와 단순 배치에 초점을 맞추고 있으며,
  - 향후 다중 시트, 블록 템플릿, 웹 UI 연동 등으로 확장 가능하도록 설계되었습니다.

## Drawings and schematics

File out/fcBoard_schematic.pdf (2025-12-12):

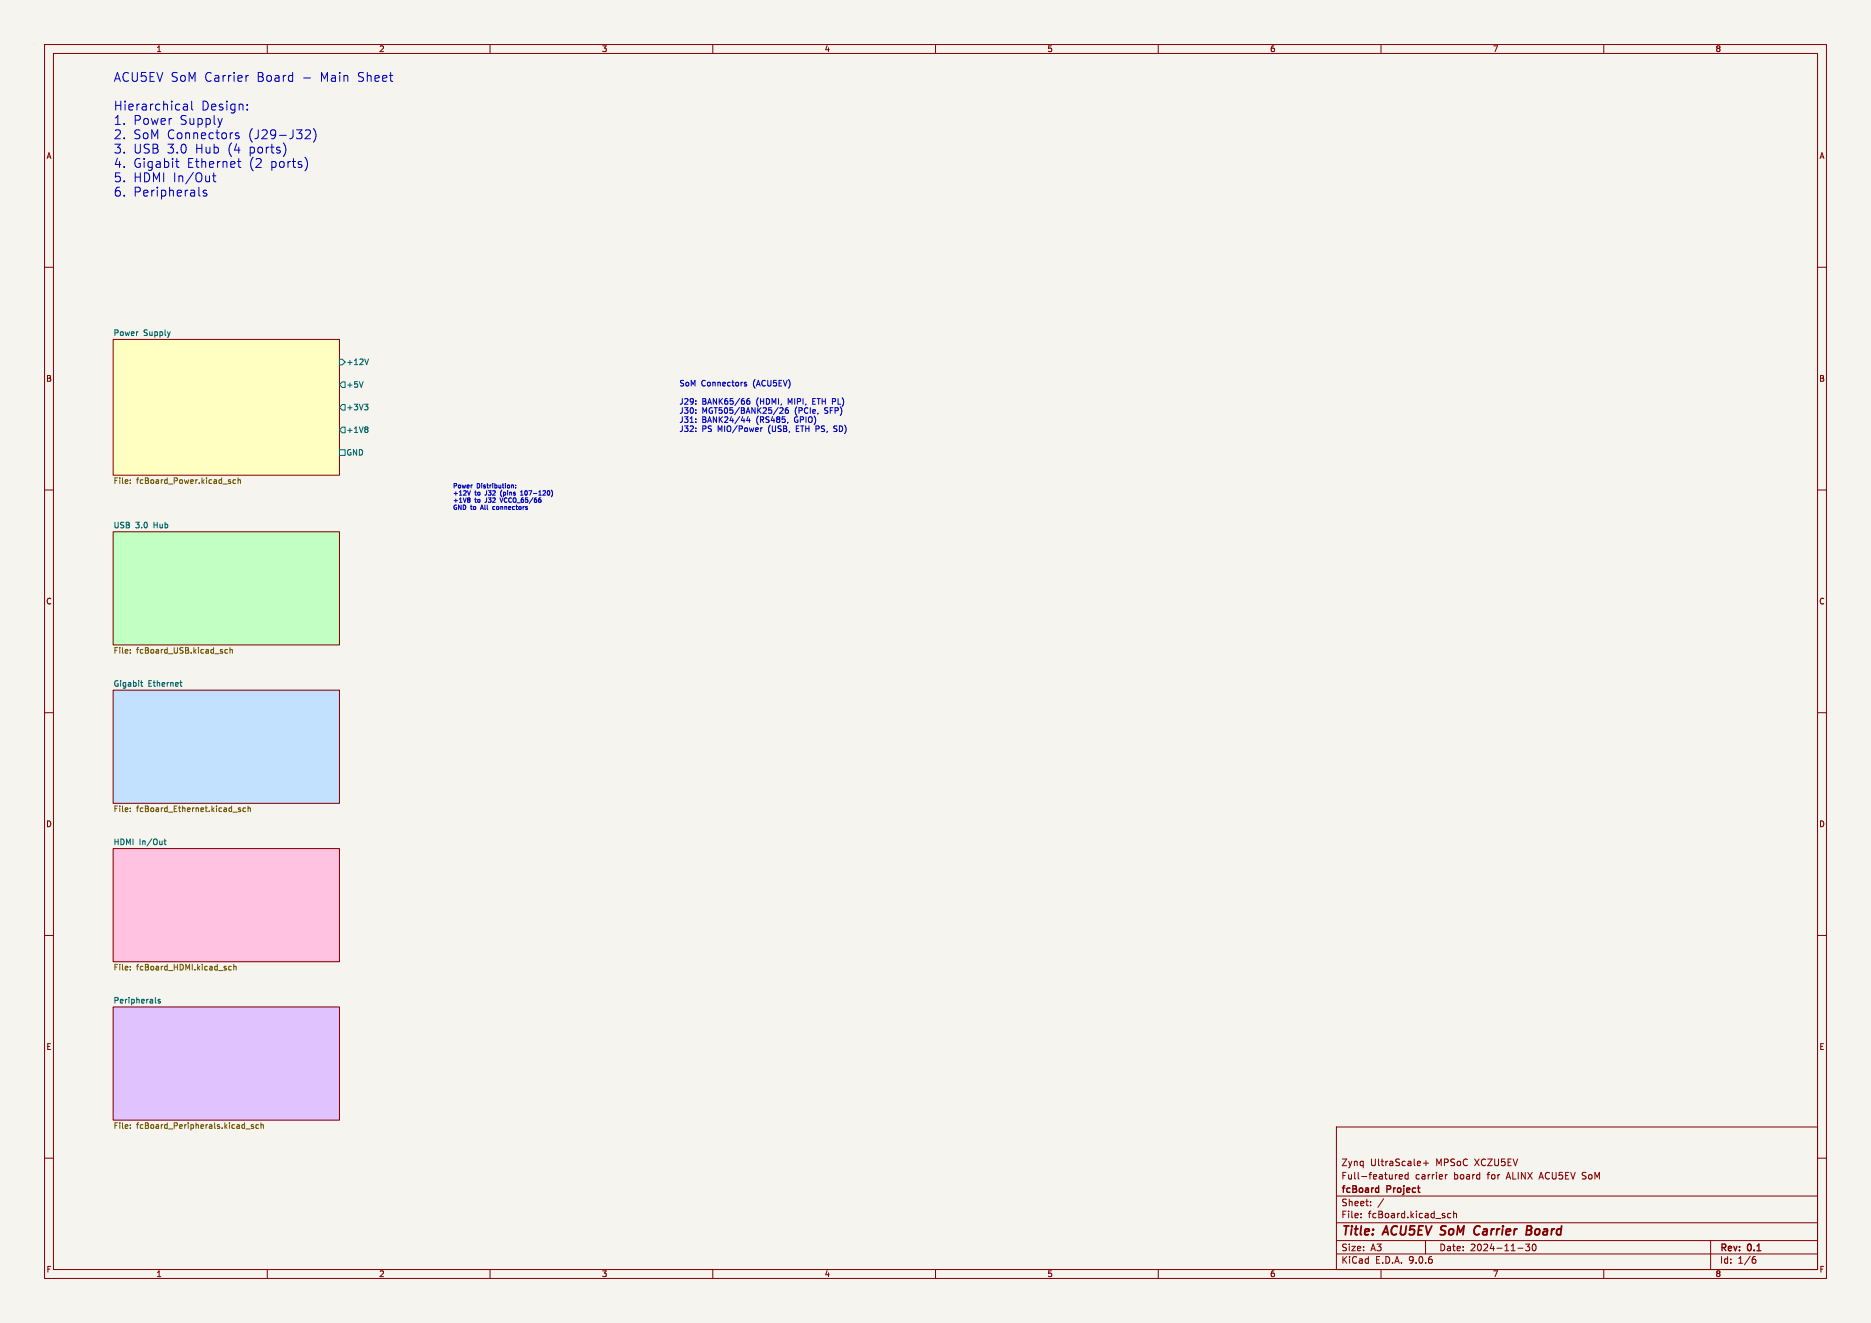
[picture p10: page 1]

1. Power Supply
6. Peripherals
Power Supply File: fcBoard_Power.kicad_sch USB 3.0 Hub File: fcBoard_USB.kicad_sch Gigabit Ethernet File: fcBoard_Ethernet.kicad_sch HDMI In/Out File: fcBoard_HDMI.kicad_sch Peripherals File: fcBoard_Peripherals.kicad_sch

Id: 1/6 Title: ACU5EV SoM Carrier Board

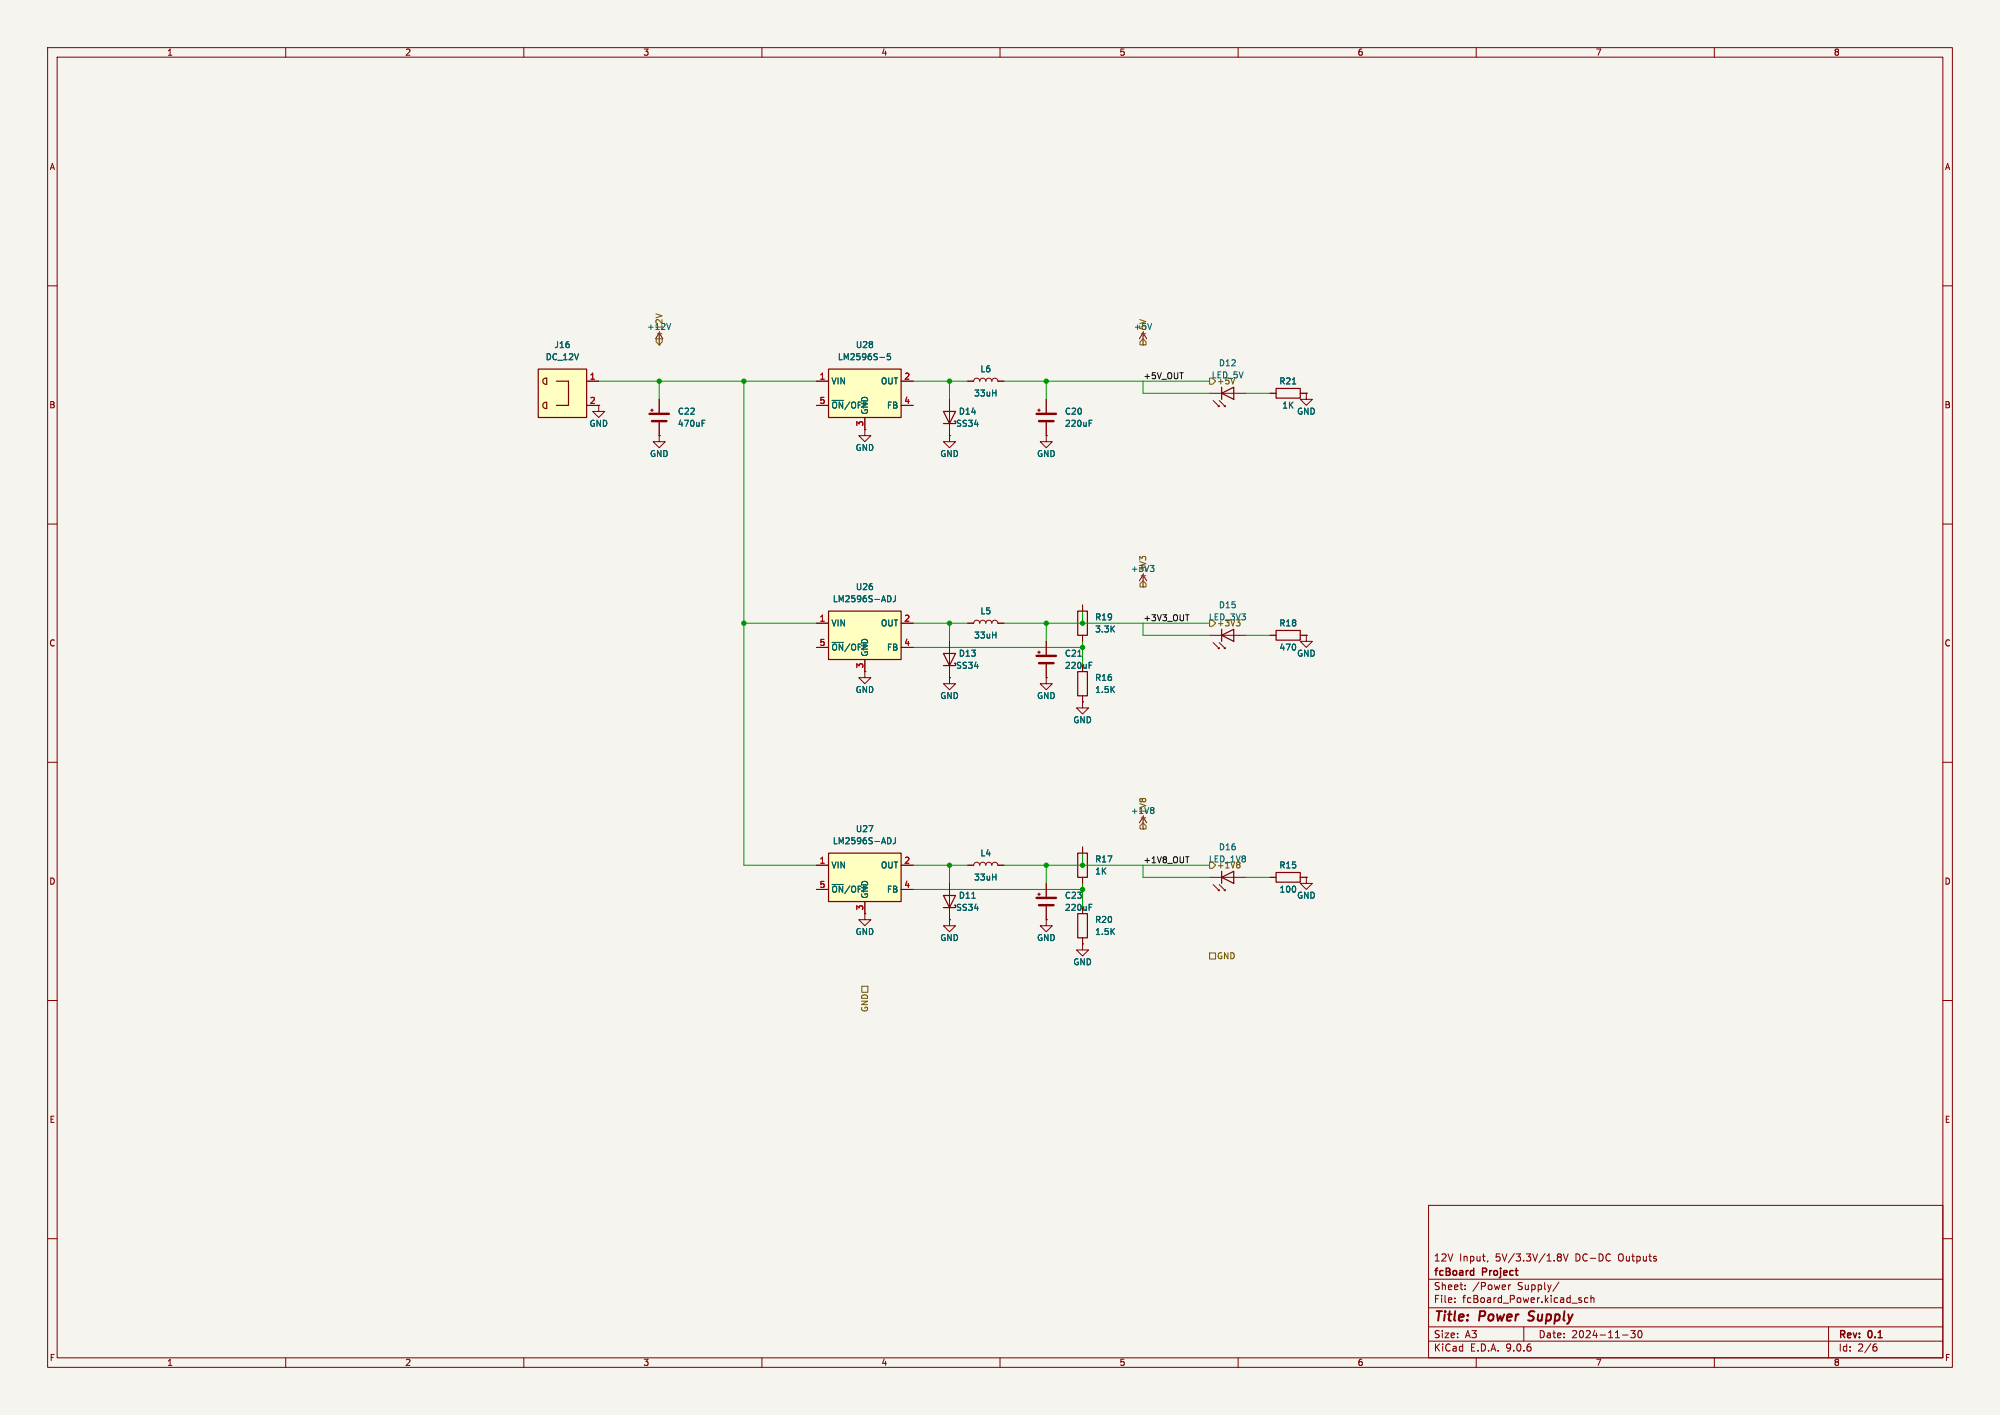
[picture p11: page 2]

3 OUT 2 FB 4 GND GND

Id: 2/6 Title: Power Supply

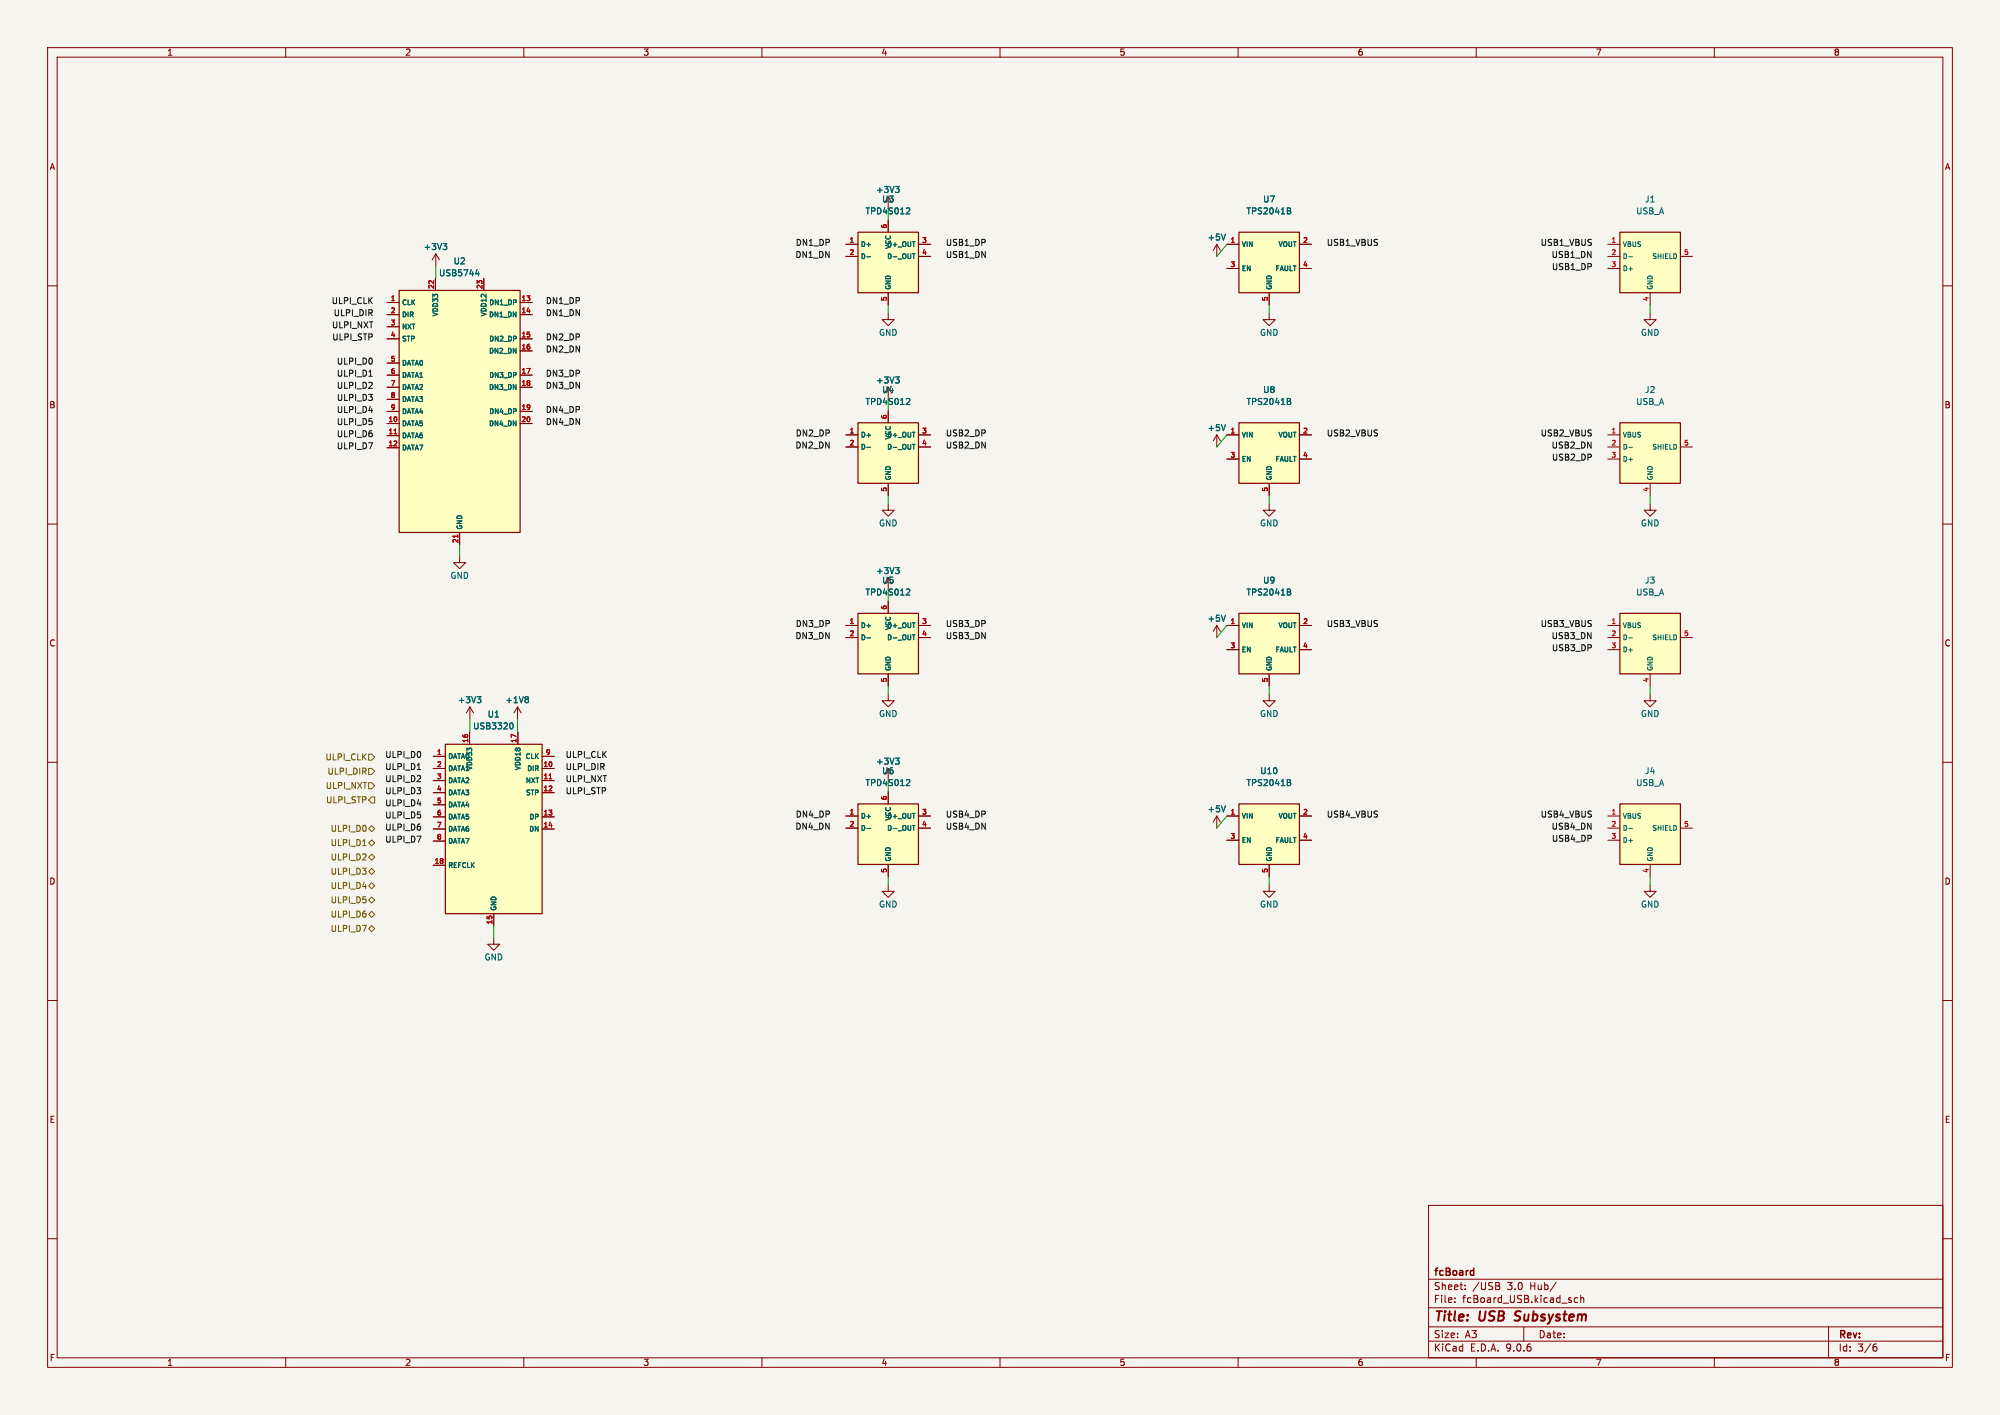
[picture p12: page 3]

Id: 3/6 Title: USB Subsystem

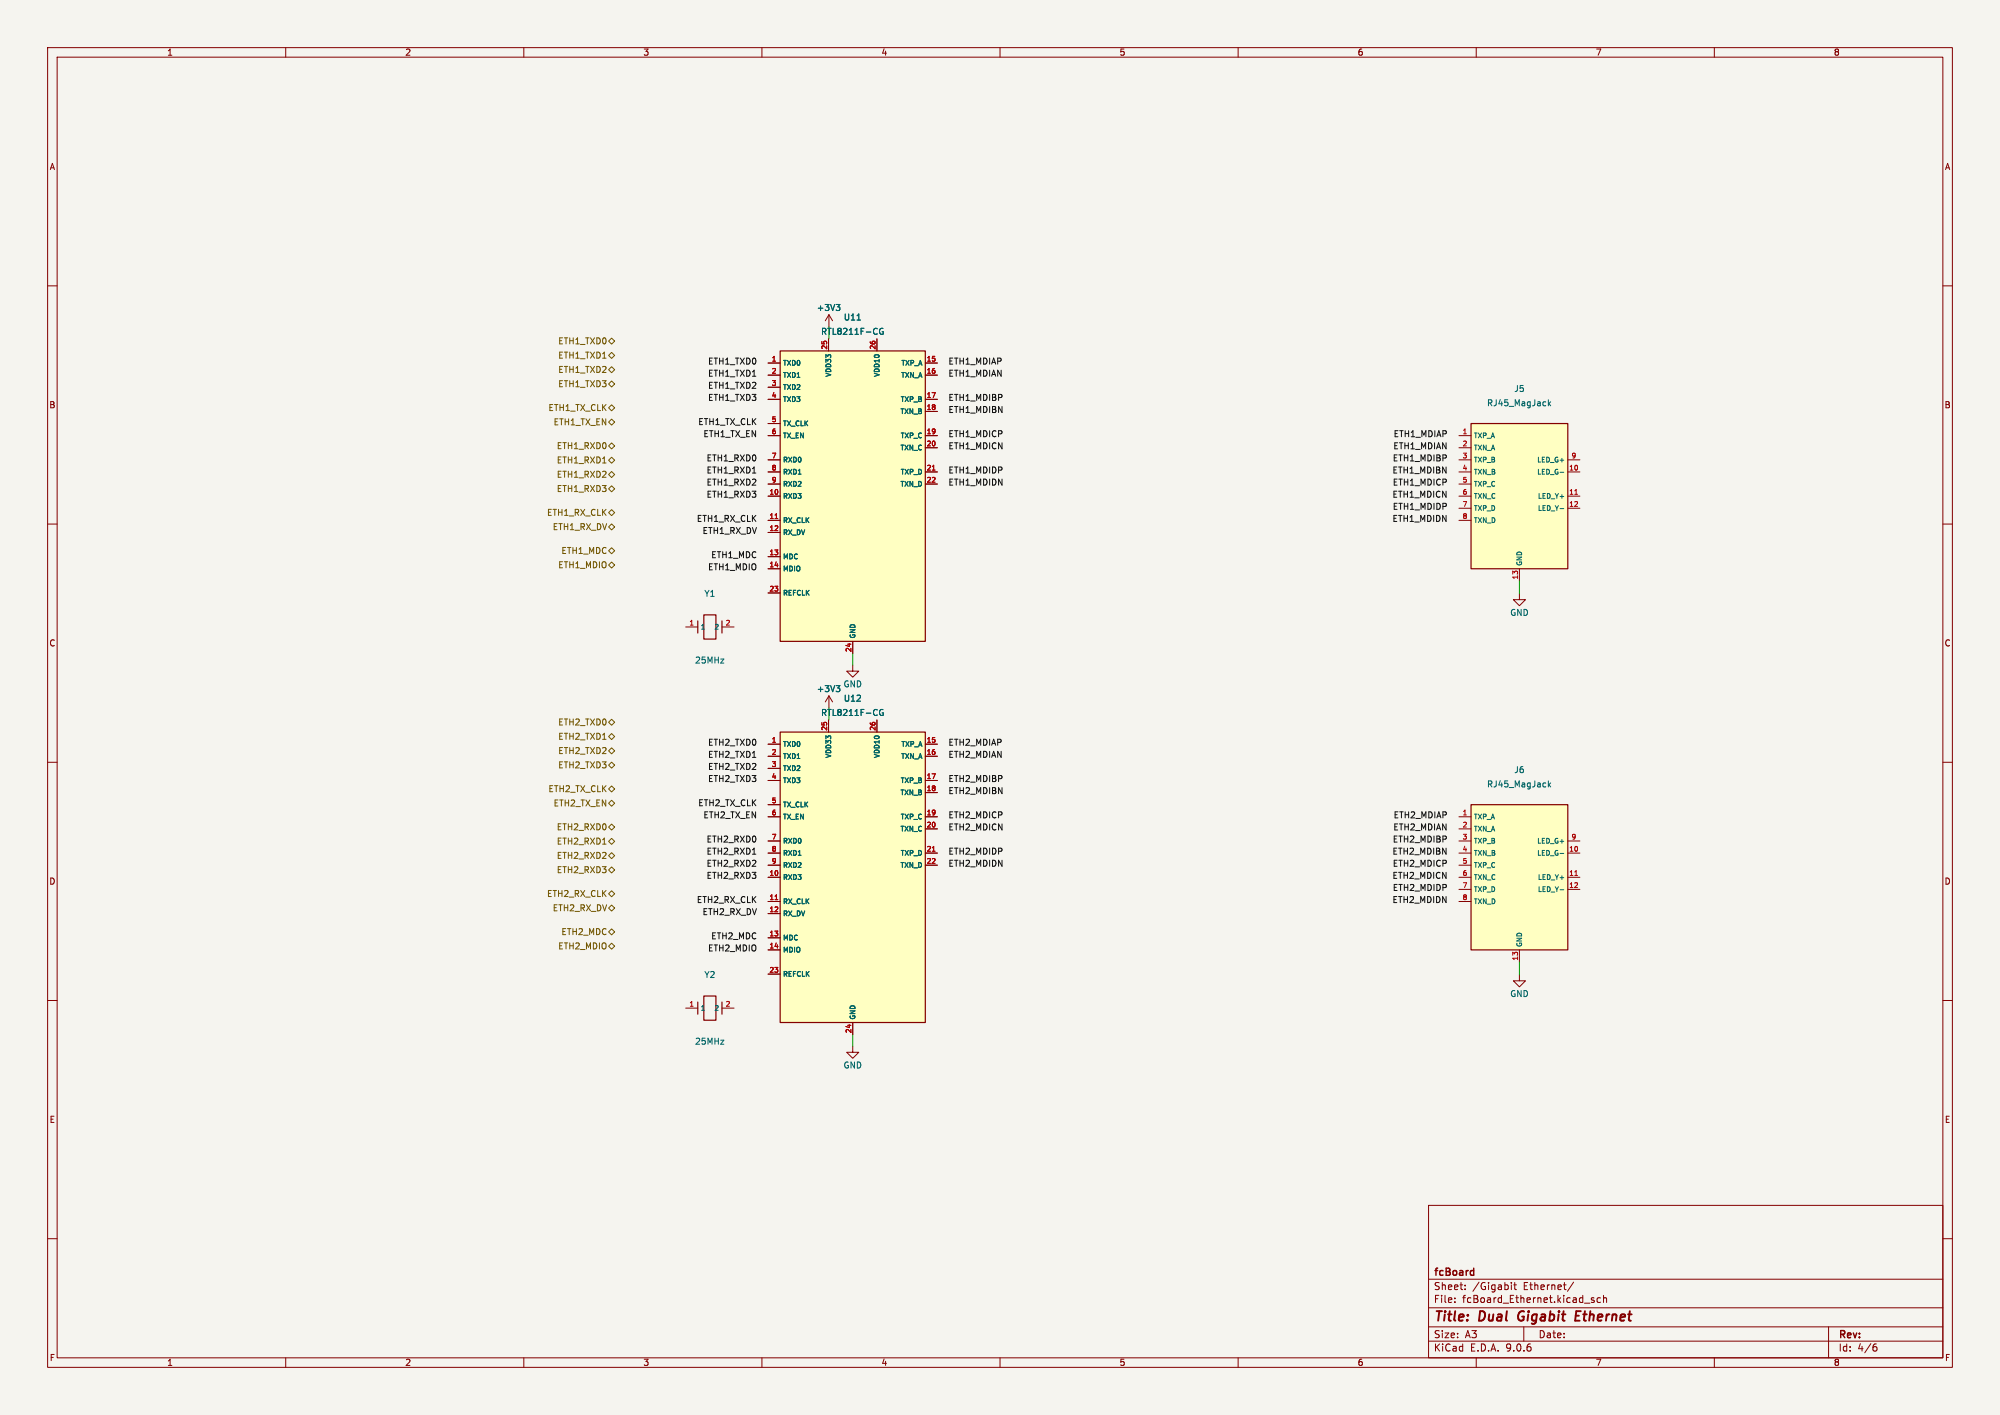
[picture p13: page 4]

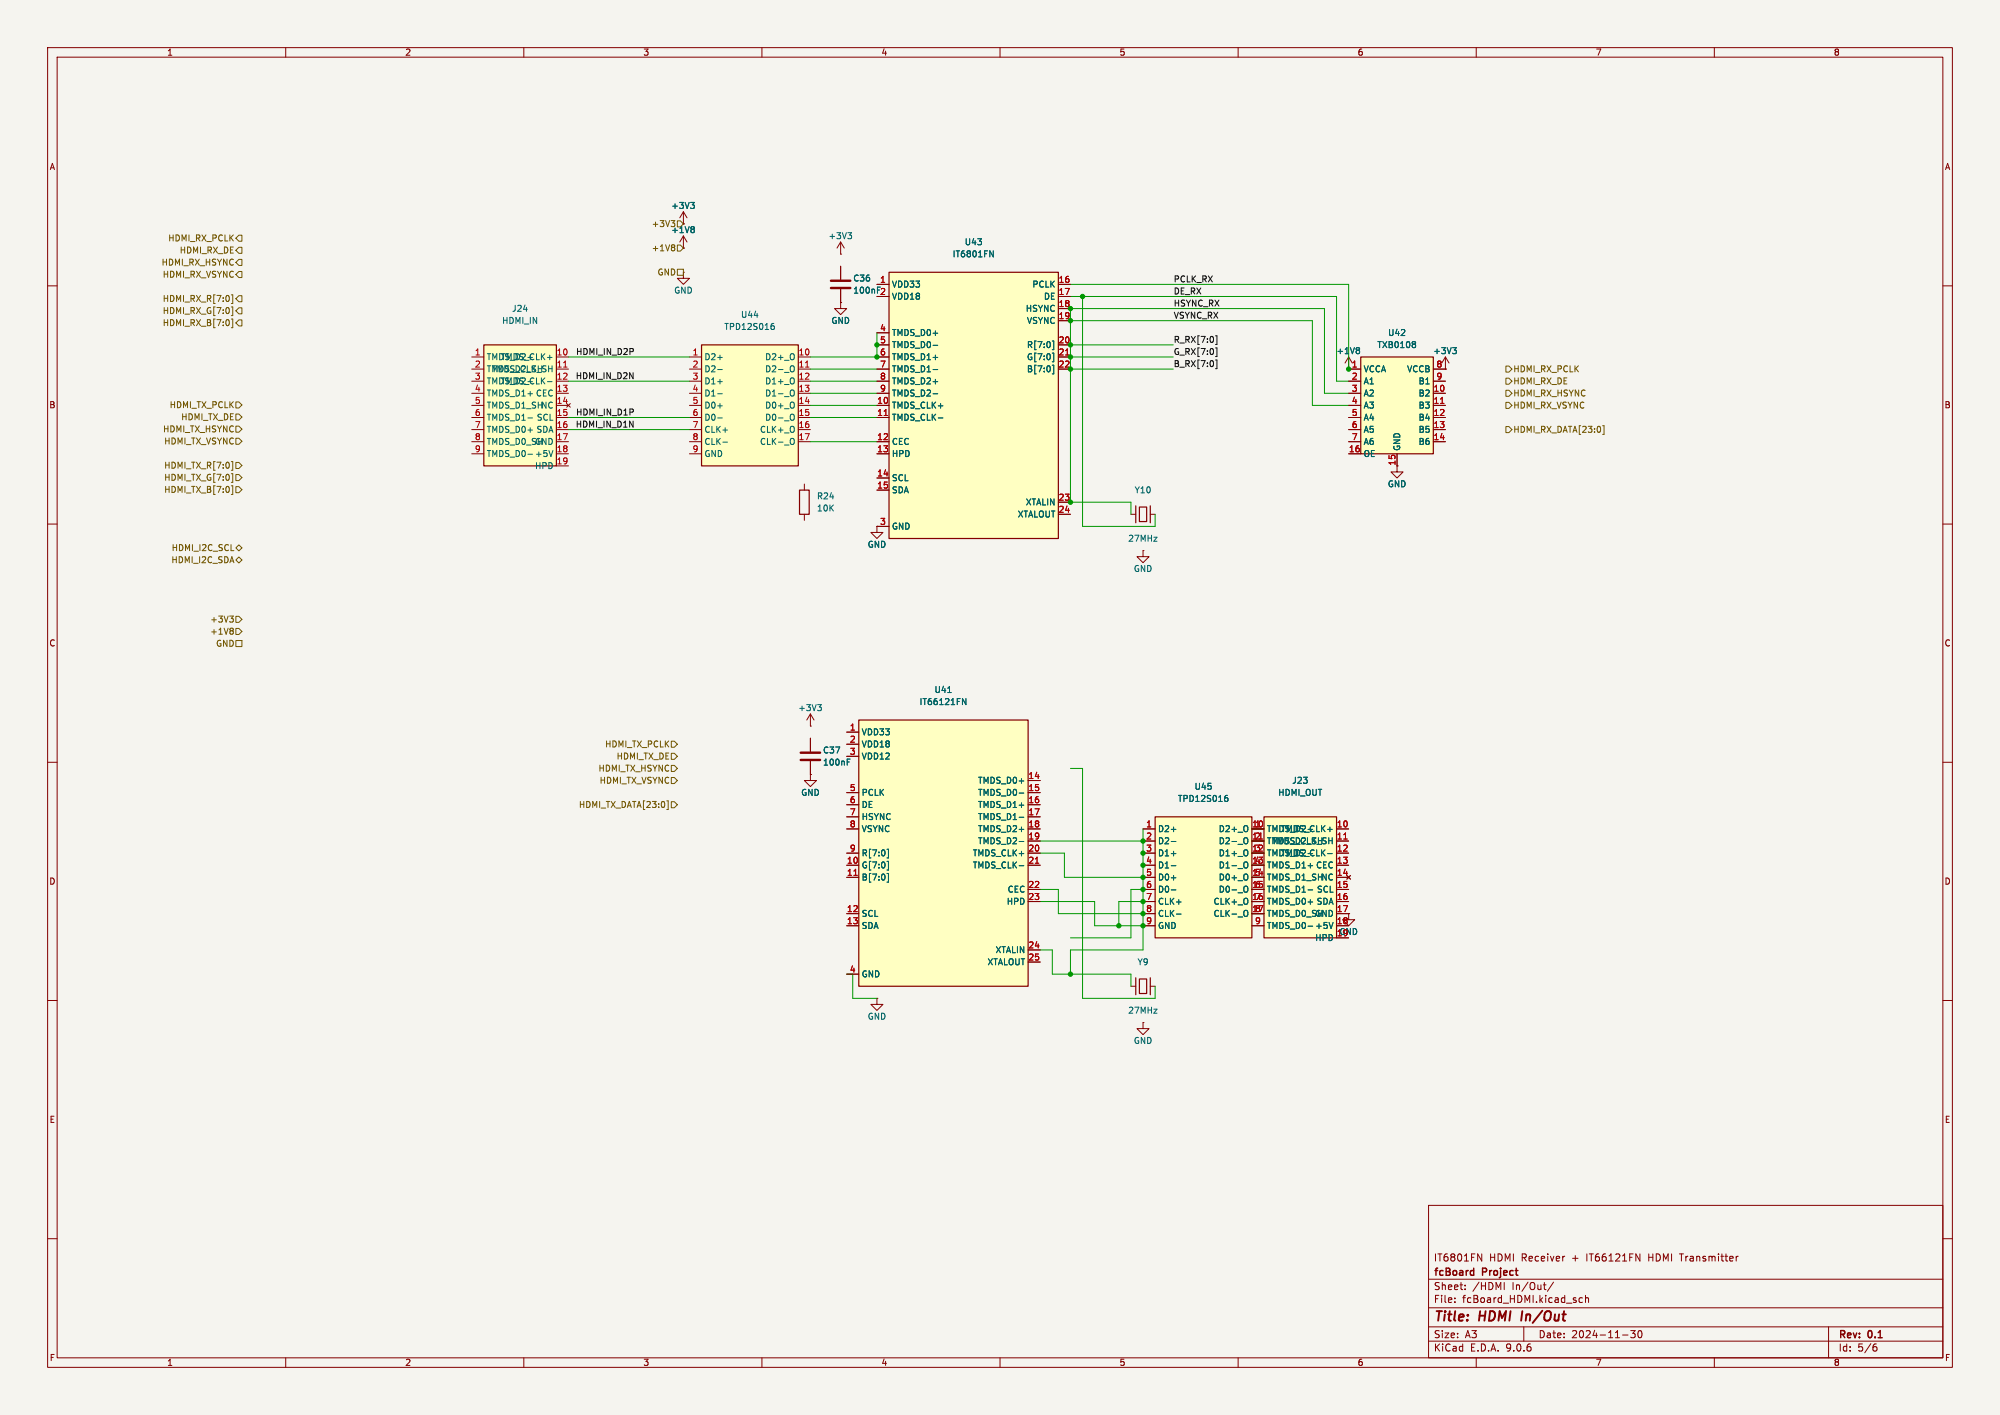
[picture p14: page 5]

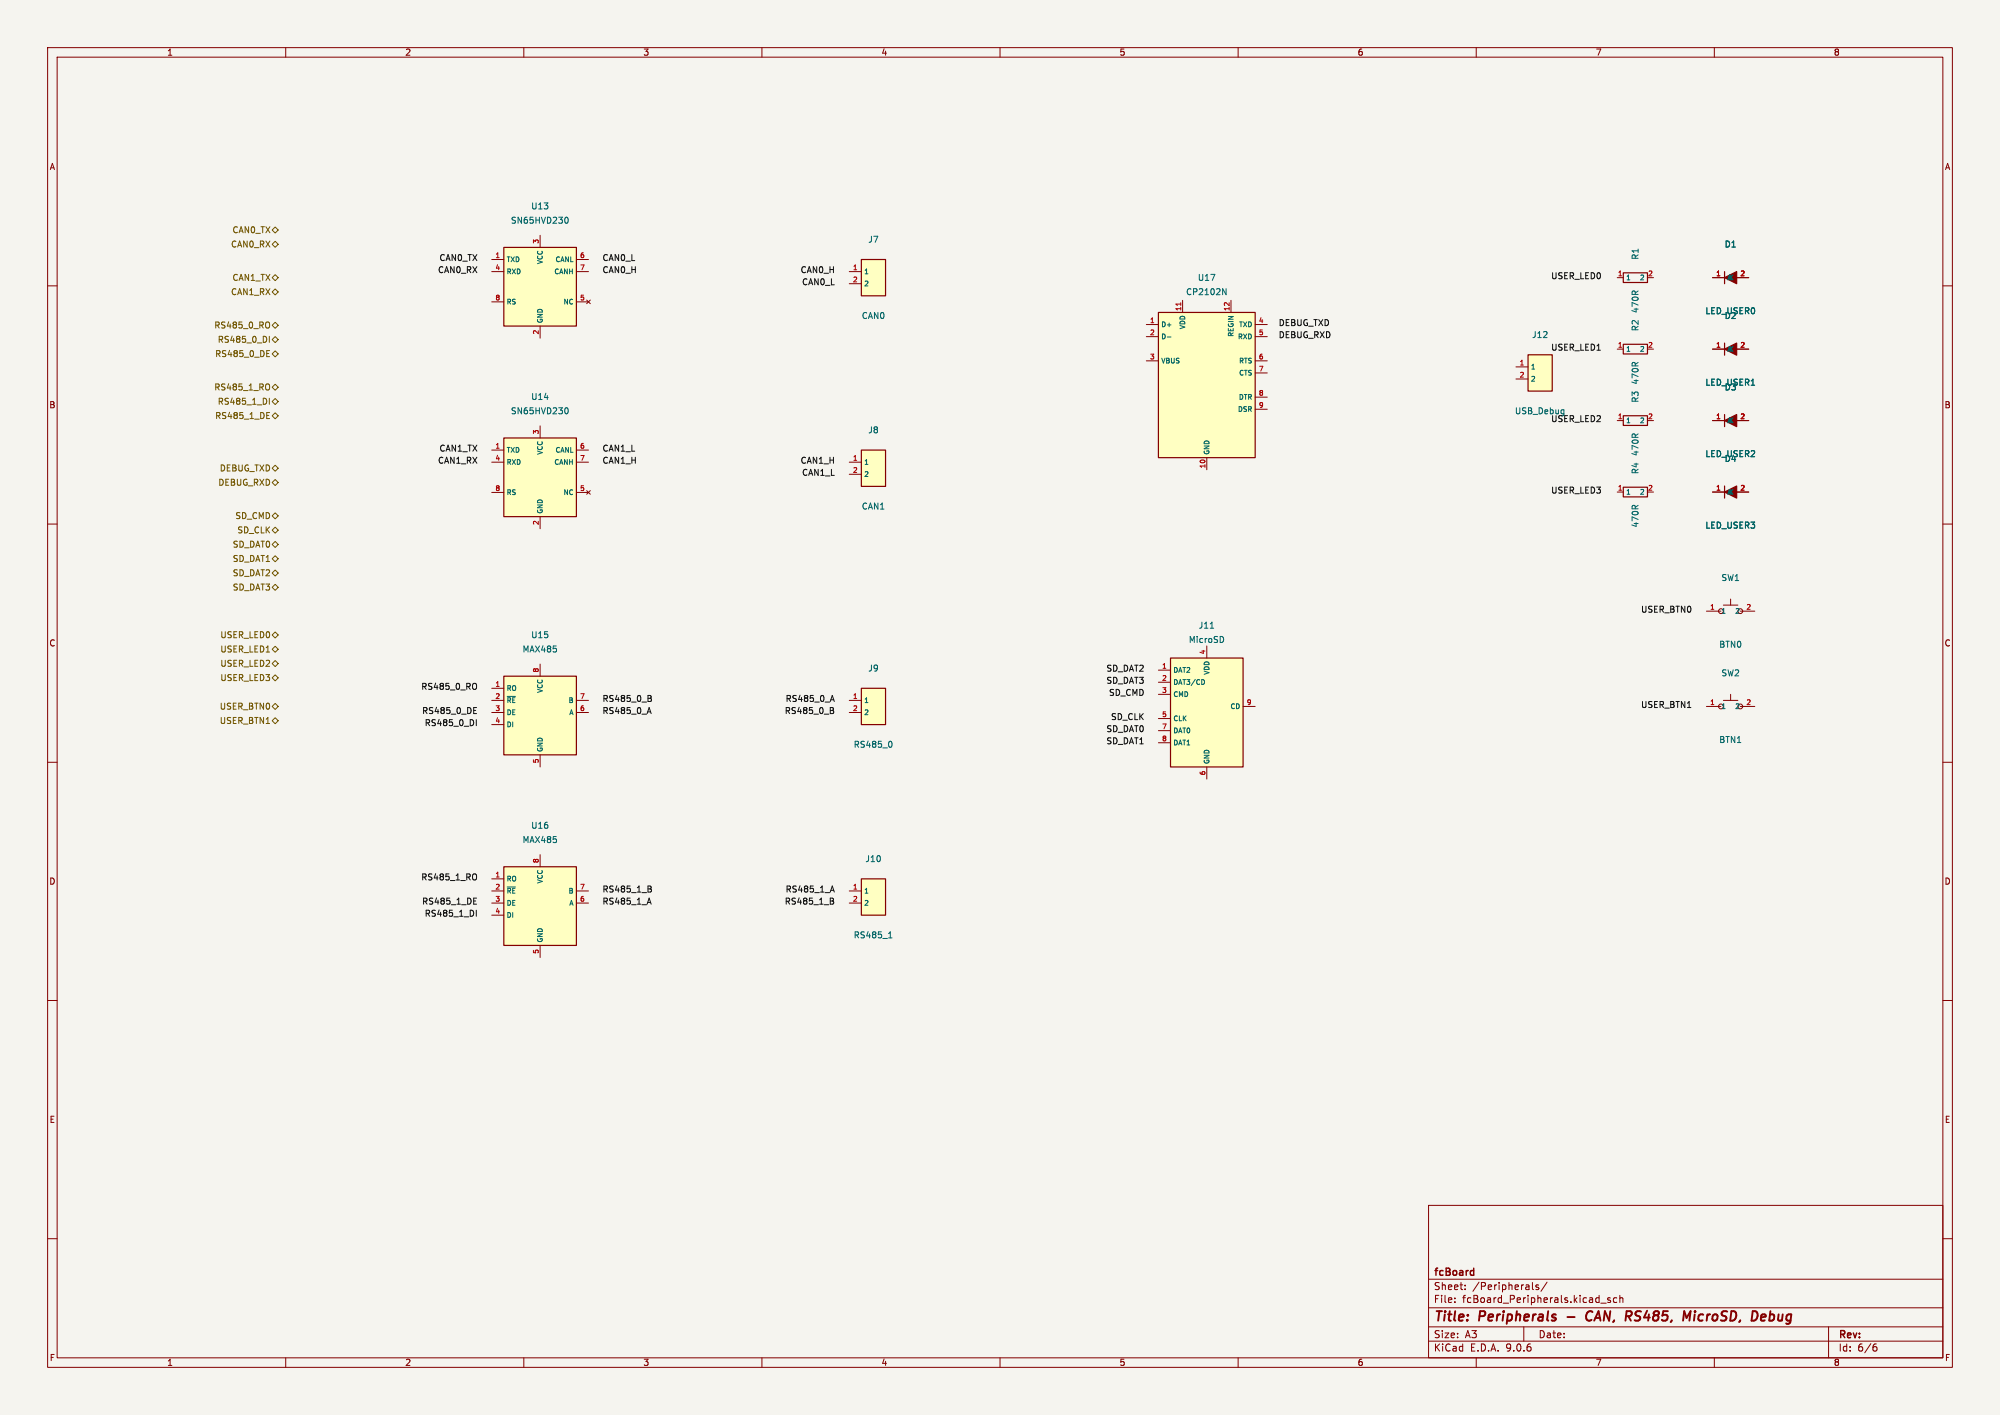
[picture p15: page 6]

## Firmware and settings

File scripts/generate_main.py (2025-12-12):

#!/usr/bin/env python3
"""
Main Schematic Generator

Generates the top-level hierarchical schematic (fcBoard.kicad_sch) with:
- All embedded symbols in lib_symbols (required for hierarchical sheets)
- Sheet references to all sub-schematics
- Title block and annotations

IMPORTANT: KiCad hierarchical designs require all symbols to be defined
in the root schematic's lib_symbols section for proper symbol resolution.

Usage:
    python scripts/generate_main.py
"""

import sys
from pathlib import Path

sys.path.insert(0, str(Path(__file__).parent))

from kicad_lib.symbols import COMMON_SYMBOLS, POWER_SYMBOLS, IC_SYMBOLS, CONNECTOR_SYMBOLS
from kicad_lib.generator import gen_uuid, generate_deterministic_uuid

# All symbols used across all sub-schematics
ALL_COMMON = ["R", "C", "CP", "L", "LED", "D_Schottky", "Crystal", "Ferrite_Bead", "Fuse"]
ALL_POWER = ["GND", "+12V", "+5V", "+3V3", "+1V8", "+2V5", "VBUS"]
ALL_IC = ["LM2596S-5", "LM2596S-ADJ", "USB5744", "USB3320", "RTL8211F",
          "IT6801FN", "IT66121FN", "MAX485", "CP2102N"]
ALL_CONNECTOR = ["Barrel_Jack", "USB_A", "USB_C", "RJ45_Magjack", "HDMI_A",
                 "Conn_2x10", "SW_Push", "TestPoint"]

PREFIX = "fcBoard"
PROJECT = "fcBoard"
SCHEMATIC_UUID = generate_deterministic_uuid(f"{PROJECT}_main")


def build_lib_symbols():
    """Build the complete lib_symbols section with all symbols."""
    symbols = []

    # Add common symbols
    for name in ALL_COMMON:
        if name in COMMON_SYMBOLS:
            symbols.append(COMMON_SYMBOLS[name].format(prefix=PREFIX))

    # Add power symbols
    for name in ALL_POWER:
        if name in POWER_SYMBOLS:
            symbols.append(POWER_SYMBOLS[name].format(prefix=PREFIX))

    # Add IC symbols
    for name in ALL_IC:
        if name in IC_SYMBOLS:
            symbols.append(IC_SYMBOLS[name].format(prefix=PREFIX))

    # Add connector symbols
    for name in ALL_CONNECTOR:
        if name in CONNECTOR_SYMBOLS:
            symbols.append(CONNECTOR_SYMBOLS[name].format(prefix=PREFIX))

    return '\n\t\t'.join(symbols)


def generate_main_schematic():
    """Generate the main hierarchical schematic."""

    lib_symbols = build_lib_symbols()

    schematic = f'''(kicad_sch
	(version 20250114)
	(generator "eeschema")
	(generator_version "9.0")
	(uuid "{SCHEMATIC_UUID}")
	(paper "A3")
	(title_block
		(title "ACU5EV SoM Carrier Board")
		(date "2024-12-12")
		(rev "1.0")
		(company "fcBoard Project")
		(comment 1 "Full-featured carrier board for ALINX ACU5EV SoM")
		(comment 2 "Zynq UltraScale+ MPSoC XCZU5EV - Embedded Symbols")
	)
	(lib_symbols
		{lib_symbols}
	)
	(text "ACU5EV SoM Carrier Board - Main Sheet\\n\\nHierarchical Design:\\n1. Power Supply (12V/5V/3.3V/1.8V)\\n2. USB 3.0 Hub (4 ports)\\n3. Gigabit Ethernet (2 ports)\\n4. HDMI In/Out\\n5. Peripherals (RS485, UART, GPIO)"
		(exclude_from_sim no)
		(at 25.4 30.48 0)
		(effects
			(font (size 2 2))
			(justify left)
		)
		(uuid "{gen_uuid()}")
	)
	(text "All sub-schematics use EMBEDDED symbols.\\nNo external library dependencies required.\\nJLCPCB LCSC Part numbers included for BOM."
		(exclude_from_sim no)
		(at 152.4 30.48 0)
		(effects
			(font (size 1.5 1.5))
			(justify left)
		)
		(uuid "{gen_uuid()}")
	)
	(sheet
		(at 25.4 76.2)
		(size 50.8 30.48)
		(exclude_from_sim no)
		(in_bom yes)
		(on_board yes)
		(dnp no)
		(fields_autoplaced yes)
		(stroke (width 0.1524) (type solid))
		(fill (color 255 255 194 1.0000))
		(uuid "{gen_uuid()}")
		(property "Sheetname" "Power Supply"
			(at 25.4 75.4884 0)
			(effects (font (size 1.27 1.27)) (justify left bottom))
		)
		(property "Sheetfile" "fcBoard_Power.kicad_sch"
			(at 25.4 107.2216 0)
			(effects (font (size 1.27 1.27)) (justify left top))
		)
	)
	(sheet
		(at 88.9 76.2)
		(size 50.8 30.48)
		(exclude_from_sim no)
		(in_bom yes)
		(on_board yes)
		(dnp no)
		(fields_autoplaced yes)
		(stroke (width 0.1524) (type solid))
		(fill (color 194 255 194 1.0000))
		(uuid "{gen_uuid()}")
		(property "Sheetname" "USB 3.0 Hub"
			(at 88.9 75.4884 0)
			(effects (font (size 1.27 1.27)) (justify left bottom))
		)
		(property "Sheetfile" "fcBoard_USB.kicad_sch"
			(at 88.9 107.2216 0)
			(effects (font (size 1.27 1.27)) (justify left top))
		)
	)
	(sheet
		(at 152.4 76.2)
		(size 50.8 30.48)
		(exclude_from_sim no)
		(in_bom yes)
		(on_board yes)
		(dnp no)
		(fields_autoplaced yes)
		(stroke (width 0.1524) (type solid))
		(fill (color 194 194 255 1.0000))
		(uuid "{gen_uuid()}")
		(property "Sheetname" "Gigabit Ethernet"
			(at 152.4 75.4884 0)
			(effects (font (size 1.27 1.27)) (justify left bottom))
		)
		(property "Sheetfile" "fcBoard_Ethernet.kicad_sch"
			(at 152.4 107.2216 0)
			(effects (font (size 1.27 1.27)) (justify left top))
		)
	)
	(sheet
		(at 215.9 76.2)
		(size 50.8 30.48)
		(exclude_from_sim no)
		(in_bom yes)
		(on_board yes)
		(dnp no)
		(fields_autoplaced yes)
		(stroke (width 0.1524) (type solid))
		(fill (color 255 194 194 1.0000))
		(uuid "{gen_uuid()}")
		(property "Sheetname" "HDMI In/Out"
			(at 215.9 75.4884 0)
			(effects (font (size 1.27 1.27)) (justify left bottom))
		)
		(property "Sheetfile" "fcBoard_HDMI.kicad_sch"
			(at 215.9 107.2216 0)
			(effects (font (size 1.27 1.27)) (justify left top))
		)
	)
	(sheet
		(at 279.4 76.2)
		(size 50.8 30.48)
		(exclude_from_sim no)
		(in_bom yes)
		(on_board yes)
		(dnp no)
		(fields_autoplaced yes)
		(stroke (width 0.1524) (type solid))
		(fill (color 255 255 255 1.0000))
		(uuid "{gen_uuid()}")
		(property "Sheetname" "Peripherals"
			(at 279.4 75.4884 0)
			(effects (font (size 1.27 1.27)) (justify left bottom))
		)
		(property "Sheetfile" "fcBoard_Peripherals.kicad_sch"
			(at 279.4 107.2216 0)
			(effects (font (size 1.27 1.27)) (justify left top))
		)
	)
	(sheet_instances
		(path "/"
			(page "1")
		)
	)
)
'''
    return schematic


def main():
    """Main entry point."""
    print("=" * 60)
    print("Main Schematic Generator")
    print("=" * 60)

    script_dir = Path(__file__).parent.resolve()
    project_root = script_dir.parent
    output_file = project_root / "fcBoard.kicad_sch"

    schematic = generate_main_schematic()

    with open(output_file, 'w', encoding='utf-8') as f:
        f.write(schematic)

    print(f"[OK] Generated: {output_file}")
    print()
    print("Embedded symbols included:")
    print(f"  - Common: {', '.join(ALL_COMMON)}")
    print(f"  - Power: {', '.join(ALL_POWER)}")
    print(f"  - ICs: {', '.join(ALL_IC)}")
    print(f"  - Connectors: {', '.join(ALL_CONNECTOR)}")
    print()
    print("Hierarchical sheets:")
    print("  - Power Supply (fcBoard_Power.kicad_sch)")
    print("  - USB 3.0 Hub (fcBoard_USB.kicad_sch)")
    print("  - Gigabit Ethernet (fcBoard_Ethernet.kicad_sch)")
    print("  - HDMI In/Out (fcBoard_HDMI.kicad_sch)")
    print("  - Peripherals (fcBoard_Peripherals.kicad_sch)")
    print()
    print("[NOTE] All symbols are embedded in lib_symbols for hierarchical compatibility")


if __name__ == "__main__":
    main()

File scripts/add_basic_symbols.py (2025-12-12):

#!/usr/bin/env python3
"""
Add Basic Symbols to fcBoard.kicad_sym Library

Adds R, C, CP, L, LED, D_Schottky, Crystal, Ferrite_Bead, Fuse,
GND, +12V, +5V, +3V3, +1V8, +2V5, VBUS, and connector symbols
to the fcBoard symbol library.

This allows schematic to reference fcBoard:R, fcBoard:GND, etc.
"""

import re
from pathlib import Path

# Basic symbols in KiCad 9.0 format
BASIC_SYMBOLS = '''
(symbol "R"
    (pin_numbers hide)
    (pin_names (offset 0))
    (exclude_from_sim no)
    (in_bom yes)
    (on_board yes)
    (property "Reference" "R" (at 2.032 0 90) (effects (font (size 1.27 1.27))))
    (property "Value" "R" (at 0 0 90) (effects (font (size 1.27 1.27))))
    (property "Footprint" "" (at -1.778 0 90) (effects (font (size 1.27 1.27)) hide))
    (property "Datasheet" "" (at 0 0 0) (effects (font (size 1.27 1.27)) hide))
    (property "Description" "Resistor" (at 0 0 0) (effects (font (size 1.27 1.27)) hide))
    (symbol "R_0_1"
        (rectangle (start -1.016 -2.54) (end 1.016 2.54) (stroke (width 0.254) (type default)) (fill (type none)))
    )
    (symbol "R_1_1"
        (pin passive line (at 0 5.08 270) (length 2.54) (name "~" (effects (font (size 1.27 1.27)))) (number "1" (effects (font (size 1.27 1.27)))))
        (pin passive line (at 0 -5.08 90) (length 2.54) (name "~" (effects (font (size 1.27 1.27)))) (number "2" (effects (font (size 1.27 1.27)))))
    )
)

(symbol "C"
    (pin_numbers hide)
    (pin_names (offset 0.254))
    (exclude_from_sim no)
    (in_bom yes)
    (on_board yes)
    (property "Reference" "C" (at 0.635 2.54 0) (effects (font (size 1.27 1.27)) (justify left)))
    (property "Value" "C" (at 0.635 -2.54 0) (effects (font (size 1.27 1.27)) (justify left)))
    (property "Footprint" "" (at 0.9652 -3.81 0) (effects (font (size 1.27 1.27)) hide))
    (property "Datasheet" "" (at 0 0 0) (effects (font (size 1.27 1.27)) hide))
    (property "Description" "Capacitor" (at 0 0 0) (effects (font (size 1.27 1.27)) hide))
    (symbol "C_0_1"
        (polyline (pts (xy -2.032 -0.762) (xy 2.032 -0.762)) (stroke (width 0.508) (type default)) (fill (type none)))
        (polyline (pts (xy -2.032 0.762) (xy 2.032 0.762)) (stroke (width 0.508) (type default)) (fill (type none)))
    )
    (symbol "C_1_1"
        (pin passive line (at 0 3.81 270) (length 2.794) (name "~" (effects (font (size 1.27 1.27)))) (number "1" (effects (font (size 1.27 1.27)))))
        (pin passive line (at 0 -3.81 90) (length 2.794) (name "~" (effects (font (size 1.27 1.27)))) (number "2" (effects (font (size 1.27 1.27)))))
    )
)

(symbol "CP"
    (pin_numbers hide)
    (pin_names (offset 0.254))
    (exclude_from_sim no)
    (in_bom yes)
    (on_board yes)
    (property "Reference" "C" (at 0.635 2.54 0) (effects (font (size 1.27 1.27)) (justify left)))
    (property "Value" "CP" (at 0.635 -2.54 0) (effects (font (size 1.27 1.27)) (justify left)))
    (property "Footprint" "" (at 0.9652 -3.81 0) (effects (font (size 1.27 1.27)) hide))
    (property "Datasheet" "" (at 0 0 0) (effects (font (size 1.27 1.27)) hide))
    (property "Description" "Polarized Capacitor" (at 0 0 0) (effects (font (size 1.27 1.27)) hide))
    (symbol "CP_0_1"
        (rectangle (start -2.286 0.508) (end 2.286 1.016) (stroke (width 0) (type default)) (fill (type none)))
        (polyline (pts (xy -1.778 2.286) (xy -0.762 2.286)) (stroke (width 0) (type default)) (fill (type none)))
        (polyline (pts (xy -1.27 1.778) (xy -1.27 2.794)) (stroke (width 0) (type default)) (fill (type none)))
        (rectangle (start 2.286 -0.508) (end -2.286 -1.016) (stroke (width 0) (type default)) (fill (type outline)))
    )
    (symbol "CP_1_1"
        (pin passive line (at 0 3.81 270) (length 2.794) (name "~" (effects (font (size 1.27 1.27)))) (number "1" (effects (font (size 1.27 1.27)))))
        (pin passive line (at 0 -3.81 90) (length 2.794) (name "~" (effects (font (size 1.27 1.27)))) (number "2" (effects (font (size 1.27 1.27)))))
    )
)

(symbol "L"
    (pin_numbers hide)
    (pin_names (offset 1.016))
    (exclude_from_sim no)
    (in_bom yes)
    (on_board yes)
    (property "Reference" "L" (at -1.27 0 90) (effects (font (size 1.27 1.27))))
    (property "Value" "L" (at 1.905 0 90) (effects (font (size 1.27 1.27))))
    (property "Footprint" "" (at 0 0 0) (effects (font (size 1.27 1.27)) hide))
    (property "Datasheet" "" (at 0 0 0) (effects (font (size 1.27 1.27)) hide))
    (property "Description" "Inductor" (at 0 0 0) (effects (font (size 1.27 1.27)) hide))
    (symbol "L_0_1"
        (arc (start 0 -2.54) (mid 0.6323 -1.905) (end 0 -1.27) (stroke (width 0) (type default)) (fill (type none)))
        (arc (start 0 -1.27) (mid 0.6323 -0.635) (end 0 0) (stroke (width 0) (type default)) (fill (type none)))
        (arc (start 0 0) (mid 0.6323 0.635) (end 0 1.27) (stroke (width 0) (type default)) (fill (type none)))
        (arc (start 0 1.27) (mid 0.6323 1.905) (end 0 2.54) (stroke (width 0) (type default)) (fill (type none)))
    )
    (symbol "L_1_1"
        (pin passive line (at 0 5.08 270) (length 2.54) (name "~" (effects (font (size 1.27 1.27)))) (number "1" (effects (font (size 1.27 1.27)))))
        (pin passive line (at 0 -5.08 90) (length 2.54) (name "~" (effects (font (size 1.27 1.27)))) (number "2" (effects (font (size 1.27 1.27)))))
    )
)
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

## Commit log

2025-11-30 Initial commit: KiCad carrier board for ACU5EV SoM
    - Power schematic with LM2596 regulators (5V, 3.3V, 1.8V)
    - USB subsystem with USB5744 hub, USB3320 ULPI PHY
    - Dual Ethernet with RTL8211F-CG PHY
    - HDMI input/output with IT6801FN and IT66121FN
    - Peripherals: CAN, RS485, MicroSD, Debug USB
    [AXK6A2337YG.step, J29_BANK65_66.csv, J30_BANK25_26_MGT.csv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]
2025-12-14 자동화2
2025-12-14 docs: CLI + YAML 기준 Quickstart 추가
    - kicad_auto_builder CLI를 공식 실행법으로 문서화
    - python -m kicad_auto_builder.cli validate/build 예시 추가
    - YAML 예제 파일 안내
    [parts_jlc.csv]
2025-12-14 refactor: scripts를 tools/archive_scripts로 이동 + Deprecated 처리
    - 모든 레거시 스크립트에 DEPRECATED 헤더 추가
    - tools/archive_scripts/README.md 생성
    - 정식 실행법: python -m kicad_auto_builder.cli

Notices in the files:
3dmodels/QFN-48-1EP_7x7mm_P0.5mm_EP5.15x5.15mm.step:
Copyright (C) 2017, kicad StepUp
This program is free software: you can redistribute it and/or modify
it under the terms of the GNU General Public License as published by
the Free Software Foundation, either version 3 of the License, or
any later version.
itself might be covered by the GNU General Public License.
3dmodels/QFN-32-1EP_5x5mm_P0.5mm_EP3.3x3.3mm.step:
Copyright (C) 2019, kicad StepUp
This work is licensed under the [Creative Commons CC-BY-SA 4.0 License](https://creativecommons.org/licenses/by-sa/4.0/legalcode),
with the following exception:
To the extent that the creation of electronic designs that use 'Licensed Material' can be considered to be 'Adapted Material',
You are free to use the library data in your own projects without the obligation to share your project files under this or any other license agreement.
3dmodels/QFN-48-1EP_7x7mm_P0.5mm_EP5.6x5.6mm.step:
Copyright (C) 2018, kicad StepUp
